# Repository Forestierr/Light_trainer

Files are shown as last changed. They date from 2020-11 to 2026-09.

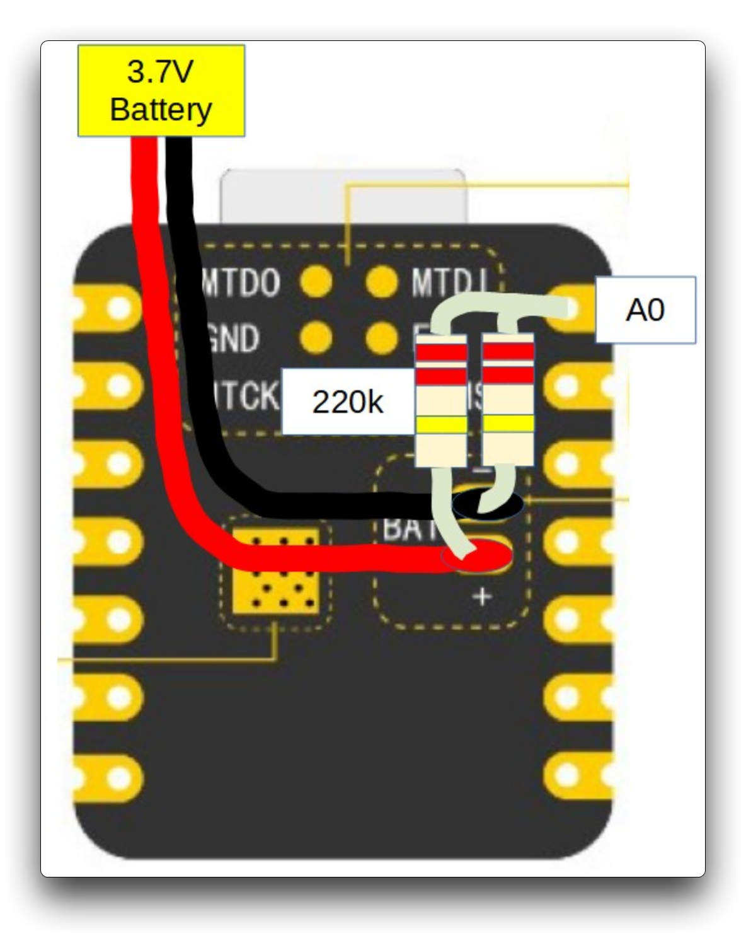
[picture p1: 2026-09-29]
1_Documentation/images/battery_mesurement.png

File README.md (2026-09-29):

<h1 align="center">⚡ Light Trainer — Système d'Entraînement Réactif Sans Fil ⚡</h1>

<p align="center">
  
  
  
  
  
</p>

<p align="center">
  <b>Pods lumineux interactifs, ultra-réactifs et modulaires pour l'entraînement sportif, le travail des réflexes, de l'agilité et de la réactivité cognitive.</b>
</p>

---

## 🌟 Points Forts du Système

* 🚀 **Zéro Latence & Réseau Maillé Auto-Organisé** : Communication instantanée multi-sauts via **ESP-NOW (2.4 GHz)**. Pas besoin de routeur Wi-Fi, les pods se découvrent et se synchronisent automatiquement.
* ✋ **Interaction 100% Sans Contact (ToF Laser)** : Télémètre **VL53L0X** cadencé à 50 Hz pour une détection millimétrique des frappes sans usure mécanique.
* 🌈 **Affichage 360° Haute Visibilité** : Anneau de 7 LEDs RVB adressables **WS2812B** avec gestion de jauges de progression et flashs de confirmation.
* 🔋 **Gestion d'Énergie Avancée & Autonomie** :
  * Batterie LiPo 3.7V avec **recharge USB-C automatique**.
  * **Deep Sleep ultra-basse consommation ($\approx 10\,\mu\text{A}$)** via coupure d'alimentation commutée $3\text{V}3\_S$ et réveil instantané sur interrupteur.
  * Mesure continue de la tension de batterie avec compensation ADC d'usine eFuse.
* 📱 **Double Interface** : Pilotage 100% gestuel sur le pod + portail Web de configuration intégré (Wi-Fi SoftAP).

---

## 📂 Structure du Répertoire

```
Light_trainer/
├── 1_Documentation/               # 📖 Documentation complète & schémas
│   ├── Architecture_Systeme.md    # Spécifications techniques & protocoles
│   ├── Dashboard_Web_App.md       # Spécifications de l'interface Web & API
│   ├── Guide_Montage_Materiel.md  # Guide pas-à-pas d'assemblage & BOM
│   ├── Manuel_Utilisation_et_Modes.md # Guide des gestes & 5 modes de jeu
│   ├── Roadmap_Idees_et_TODO.md   # Feuille de route & TODO pour la production
│   └── DOC_FAB/schema.pdf         # Schéma électronique officiel V3
├── 2_Mesures/                     # 📊 Cahier d'expérimentation & banc d'essais
│   └── Protocole_de_Tests_et_Mesures.md # Tableaux de relevés et qualification
├── 3_Datasheets/                  # 📑 Fiches techniques des composants
├── 4_Fabrication/                 # 🛠️ Fichiers de fabrication KiCad & Gerber
│   └── Version_02/light_trainer/  # Projet PCB KiCad V3
├── 5_Programmation/               # 💻 Codes sources & firmware
│   ├── XIAO-esp32-v3/main/        # Firmware principal complet (Production)
│   └── TEST_BENCH/                # Suite de qualification unitaire matérielle
└── README.md                      # Ce document
```

---

## 📐 Schéma & Câblage Matériel (V3 / Veroboard)

### Pinout du Seeed Studio XIAO ESP32-C3

```
                       +-------------------+
                       |    [ USB-C ]      |
     (ADC Batt)   D1 --| 2              14 |-- 5V VBUS  (Détection Charge USB)
   (Switch SW1)   D2 --| 3              13 |-- GND      (Masse Commune)
  (Buzzer Opt.)   D3 --| 4              12 |-- 3V3_OUT  (Sortie Régulateur LDO)
     (I2C SCL)    D4 --| 5              11 |-- D10      (Entrée Diviseur Charge)
     (I2C SDA)    D5 --| 6              10 |-- D9
                  D6 --| 7               9 |-- D8
    (LED Data)    D7 --| 8               8 |-- 3V3
                       +-------------------+
                          |  [BAT+]  [GND] |
                          |   (21)    (22) |
```

> [!TIP]
> **Résistances $100\text{ k}\Omega$ Unifiées** : Le circuit utilise uniquement des résistances standard de **$100\text{ k}\Omega$** ($R_1$ à $R_6$), simplifiant l'approvisionnement et le montage.

Consultez le [**Guide de Montage Matériel**](file:///c:/Users/Robin/Desktop/GitHub/Light_trainer/1_Documentation/Guide_Montage_Materiel.md) pour les détails d'implantation et les schémas complets.

---

## 🎮 Modes de Jeu & Navigation Gestuelle

| Geste ToF | Durée | Action en Mode Menu | Action en Cours de Jeu |
| :--- | :--- | :--- | :--- |
| **Tap Court** | $< 500\text{ ms}$ | Défilement des 5 modes (0 $\rightarrow$ 1 $\rightarrow$ 2 $\rightarrow$ 3 $\rightarrow$ 4 $\rightarrow$ 0) | *Ignoré* |
| **Hold Départ** | $1.5\text{ s}$ | **Départ de partie** (Jauge circulaire 0 à 100%) | *Non applicable* |
| **Frappe (Hit)** | $< 300\text{ ms}$ | *Ignoré* | **Validation de la cible** (Flash blanc instantané) |
| **Hold Menu** | $3.0\text{ s}$ | *Réinitialisation* | **Arrêt du jeu** et retour synchronisé au Menu pour tout le réseau |

Consultez le [**Manuel d'Utilisation**](file:///c:/Users/Robin/Desktop/GitHub/Light_trainer/1_Documentation/Manuel_Utilisation_et_Modes.md) pour découvrir les **5 modes sportifs** disponibles (Vitesse Solo, Duel Bicolore, Réflexe Aléatoire, Agilité Cognitive et Jeu Simon).

---

## 🧪 Banc de Tests et Qualification

Un firmware dédié autonome [`5_Programmation/TEST_BENCH/TEST_BENCH.ino`](file:///c:/Users/Robin/Desktop/GitHub/Light_trainer/5_Programmation/TEST_BENCH/TEST_BENCH.ino) permet de mesurer précisément les performances de votre prototype :

1. `TEST_BATTERY_STRESS` : Décharge extrême à pleine puissance (LEDs 100% blanches + RF) avec export CSV.
2. `TEST_BATTERY_GAME_SIM` : Test d'autonomie en conditions de match réelles.
3. `TEST_TOF_BENCHMARK` : Test de portée ToF, cadence de frappe (hits/min) et tenue aux perturbations solaires.
4. `TEST_RADIO_PING_RTT_RSSI` : Mesure de la portée radio, de la latence RTT (ms) et de la force du signal (RSSI).
5. `TEST_DEEP_SLEEP_POWER` : Validation de l'interrupteur matériel et mesure du courant de veille.
6. `TEST_ALL_INTERACTIVE` : Tableau de bord interactif par commandes Série.

---

## 🚀 Démarrage Rapide

### Prérequis Logiciels
* [Arduino IDE](https://www.arduino.cc/en/software) (version 2.x recommandée).
* Package de cartes : **ESP32 by Espressif Systems** (version 2.0.14+ ou 3.x).
* Sélectionner la carte : **`XIAO_ESP32C3`**.
* **Configuration Indispensable de la Flash** :
  > [!IMPORTANT]
  > Dans le menu **Outils $\rightarrow$ Partition Scheme**, sélectionnez impérativement **`Huge APP (3MB No OTA/1MB SPIFFS)`**.
  > La puce physique du XIAO ESP32-C3 dispose de 4 Mo de Flash. Sans ce réglage, le schéma standard réserve seulement 1.3 Mo à l'application, ce qui est insuffisant pour accueillir l'interface Web complète et provoque une erreur de compilation *`Sketch too big`*.
* Bibliothèques Arduino requises :
  * `FastLED`
  * `Adafruit_VL53L0X`

### Flasher le Projet
1. Ouvrez [`5_Programmation/XIAO-esp32-v3/main/main.ino`](file:///c:/Users/Robin/Desktop/GitHub/Light_trainer/5_Programmation/XIAO-esp32-v3/main/main.ino).
2. Branchez le XIAO ESP32-C3 via un câble USB-C.
3. Vérifiez que la carte est bien configurée en **Huge APP (3MB)**.
4. Cliquez sur **Téléverser**.
5. Ouvrez le Moniteur Série à **115200 bauds** pour observer le tableau de bord temps réel.

---

## 🗺️ Feuille de Route & Production

Pour découvrir les axes d'évolution logicielle pour le déploiement à grande échelle (SoftAP master exclusif, WebSockets, Gzip, PWA, calibration ToF, Web OTA et PlatformIO), consultez notre [**Feuille de Route & TODO Backlog**](file:///c:/Users/Robin/Desktop/GitHub/Light_trainer/1_Documentation/Roadmap_Idees_et_TODO.md).

---

## 📄 Licence

Ce projet est distribué sous licence **Apache 2.0**. Consultez le fichier [`LICENSE`](file:///c:/Users/Robin/Desktop/GitHub/Light_trainer/LICENSE) pour plus de détails.

---
<p align="center"><i>Robin Forestier — Projet Light Trainer</i></p>

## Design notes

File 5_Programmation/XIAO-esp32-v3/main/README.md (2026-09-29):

# Light Trainer - ESP32 Game System

Un système de jeu multi-joueurs utilisant ESP32 avec communication ESP-NOW, capteur de distance VL53L0X et LEDs WS2812B.

## Structure du Projet

```
main/
├── main.ino          # Fichier principal Arduino
├── Config.h          # Définitions de configuration globales
├── GameEngine.cpp    # Implémentation du moteur de jeu
├── GameEngine.h      # Déclarations du moteur de jeu
├── GameNetwork.cpp   # Implémentation de la logique réseau ESP-NOW
├── GameNetwork.h     # Déclarations de la logique réseau ESP-NOW
├── Hardware.cpp      # Implémentation de la gestion du matériel (LEDs, Capteur)
├── Hardware.h        # Déclarations de la gestion du matériel
├── WebConfig.cpp     # Implémentation du portail de configuration web
├── WebConfig.h       # Déclarations du portail de configuration web
└── README.md         # Ce fichier
```

## Matériel Requis

- **Seeed Studio XIAO ESP32-C3**
- **Capteur VL53L0X** (distance laser ToF I2C)
- **LEDs WS2812B** (ruban circulaire 7 LEDs)
- **Batterie LiPo 3.7V**
- **6 Résistances 100 kΩ** ($R_1$ à $R_6$)
- **1 Condensateur 100 nF** ($C_1$)
- **1 Interrupteur à glissière SPDT** ($SW_1$)

## Gestion de la Batterie & Recharge USB

Le système intègre une gestion complète de la batterie et de la recharge :

### Fonctionnalités

*   **Recharge USB-C automatique :** La batterie LiPo connectée aux pads `BAT+` / `GND` sous le XIAO est rechargée automatiquement dès le branchement du câble USB-C.
*   **Détection matérielle de Charge (D10) :** La broche `D10` est reliée au 5V `VBUS` via un pont $100\text{ k}\Omega / 200\text{ k}\Omega$ ($3.33\text{ V}$) pour détecter instantanément la connexion USB.
*   **Interrupteur ON/OFF & Veille Profonde (D2) :** L'interrupteur $SW_1$ coupe l'alimentation $3\text{V}3\_S$ du capteur/LEDs et bascule $D_2$ à LOW, mettant le XIAO en **Deep Sleep** ($\approx 10\,\mu\text{A}$). Le basculement sur ON réveille instantanément le système.
*   **Surveillance de la Tension (D1) :** Pont diviseur $100\text{ k}\Omega / 100\text{ k}\Omega$ avec condensateur de découplage $100\text{ nF}$ sur la broche ADC `D1`.
*   **Indication LED d'état :**
    *   **Orange :** Câble USB branché (Recharge en cours).
    *   **Rouge :** Batterie faible ($< 3.4\text{ V}$).
    *   **Veille de sécurité :** Coupure automatique si la batterie descend sous $3.0\text{ V}$.

## Configuration des Pins (Schéma V3 / Veroboard)

```cpp
#define LED_PIN     D7    // LEDs WS2812B Data (Broche 8)
#define SCL_PIN     D4    // I2C SCL VL53L0X (Broche 5)
#define SDA_PIN     D5    // I2C SDA VL53L0X (Broche 6)
#define SW_PIN      D2    // Interrupteur ON/OFF & Wake-up (Broche 3)
#define CHARGE_PIN  D10   // Détection Charge USB 5V (Broche 11)
#define BAT_ADC_PIN D1    // Mesure ADC Batterie (Broche 2)
#define BUZZER_PIN  D3    // Prévision Buzzer (Broche 4)
```

### Schéma de Câblage Veroboard

1. **Alimentation & Batterie :**
   * Pôle (+) de la batterie $\rightarrow$ Pad `BAT+` (Pin 21) du XIAO.
   * Pôle (-) de la batterie $\rightarrow$ Pad `GND` (Pin 22) du XIAO et masse commune `GND`.
2. **Interrupteur $SW_1$ :**
   * Broche 2 $\rightarrow$ `3V3_OUT` (Pin 12) du XIAO.
   * Broche 1 $\rightarrow$ Rail $3\text{V}3\_S$, relié à la broche `D2` et à la résistance pull-down $R_3$ ($100\text{ k}\Omega$ vers `GND`).
3. **LEDs WS2812B :**
   * `DIN` $\rightarrow$ Broche `D7` du XIAO.
   * `VDD` $\rightarrow$ Rail $3\text{V}3\_S$.
   * `GND` $\rightarrow$ `GND`.
4. **Capteur ToF VL53L0X :**
   * `VIN` $\rightarrow$ Rail $3\text{V}3\_S$.
   * `GND` $\rightarrow$ `GND`.
   * `SCL` $\rightarrow$ Broche `D4` du XIAO.
   * `SDA` $\rightarrow$ Broche `D5` du XIAO.
5. **Diviseur Batterie :**
   * $R_1$ ($100\text{ k}\Omega$) entre `BAT` et `D1`.
   * $R_2$ ($100\text{ k}\Omega$) et $C_1$ ($100\text{ nF}$) en parallèle entre `D1` et `GND`.
6. **Diviseur Détection USB (VBUS) :**
   * $R_4$ ($100\text{ k}\Omega$) entre `VBUS` (Pin 14) et `D10`.
   * $R_5 + R_6$ ($100\text{ k}\Omega + 100\text{ k}\Omega$) en série entre `D10` et `GND`.

## Modes de Jeu

Le système supporte 5 modes de jeu différents :

1.  **Mode 0**: Vitesse Solo — Couleur principale : Vert (`0x00FF00`), sans délai.
2.  **Mode 1**: Duel Bicolore — Joueur 1 : Rouge (`0xFF0000`), Joueur 2 : Vert (`0x00FF00`), sans délai (2 cibles actives en permanence).
3.  **Mode 2**: Réflexe Aléatoire — Couleur principale : Bleu (`0x0000FF`), délai aléatoire de 1 à 5s.
4.  **Mode 3**: Agilité Cognitive — C1 : Jaune (`0xFFFF00`), C2 : Magenta (`0xFF00FF`), délai aléatoire de 1 à 5s.
5.  **Mode 4**: Jeu Simon — Mémoire séquentielle & accélération progressive (rose de départ, couleurs signatures par pod).

## Configuration de Compilation (IDE Arduino / PlatformIO)

> [!IMPORTANT]
> Dans le menu **Outils $\rightarrow$ Partition Scheme**, sélectionnez **`Minimal SPIFFS (1.9MB APP with OTA/190KB SPIFFS)`** (ou `min_spiffs.csv` sous PlatformIO).
> Grâce à la pré-compression GZIP de l'interface Web (réduite de 84 Ko à 18 Ko), le binaire complet ne pèse que 1.45 Mo. Cela permet de réserver **deux partitions applicatives de 1.9 Mo** (`ota_0` et `ota_1`) et d'assurer les mises à jour sans fil **Over-The-Air (OTA)** sans câble USB.

## Fonctionnalités Clés

*   **Initialisation des lumières en début de partie** : Au démarrage d'une partie, le pod maître éteint ses lumières. Les pods esclaves reçoivent la couleur du mode de jeu sélectionné et l'affichent immédiatement.
*   **Retour au menu via le capteur ToF** : Il est possible de revenir au menu principal à tout moment pendant le jeu en couvrant le capteur ToF (courte distance) pendant 3 secondes. Si un pod esclave déclenche cette action, il envoie un signal au pod maître, qui propage ensuite la commande à tous les autres pods pour réinitialiser le système en mode MENU.

## États du Système

- **MENU**: État initial, en attente de sélection de mode ou démarrage du jeu.
- **CONTROLLER**: Pod maître, gère le déroulement du jeu et les activations.
- **CONTROLLER_TARGET**: Le maître est une cible active.
- **ACTIVE_TARGET**: Pod esclave, est une cible active.
- **IDLE_LISTENER**: Pod esclave, en attente d'activation.

## Diagramme d'États

```mermaid
stateDiagram-v2
    [*] --> MENU

    MENU --> CONTROLLER : startGame() / 's' / ToF (< TOF_MIN_DISTANCE)
    MENU --> IDLE_LISTENER : CMD_START from CONTROLLER

    CONTROLLER --> CONTROLLER_TARGET : CMD_ACTIVATE (self)
    CONTROLLER_TARGET --> CONTROLLER : triggerHit / ToF (< TOF_MIN_DISTANCE)

    IDLE_LISTENER --> ACTIVE_TARGET : CMD_ACTIVATE (self)
    ACTIVE_TARGET --> IDLE_LISTENER : triggerHit / ToF (< TOF_MIN_DISTANCE)

    CONTROLLER --> MENU : returnToMenu() / 'r' / ToF (3s)
    CONTROLLER_TARGET --> MENU : returnToMenu() / 'r' / ToF (3s)
    IDLE_LISTENER --> MENU : CMD_RETURN_TO_MENU from CONTROLLER / 'r' / ToF (3s) (initiateur)
    ACTIVE_TARGET --> MENU : CMD_RETURN_TO_MENU from CONTROLLER / 'r' / ToF (3s) (initiateur)

    note left of MENU : État initial, en attente de sélection de mode ou démarrage du jeu.
    note right of CONTROLLER : Pod maître, gère le déroulement du jeu et les activations.
    note right of CONTROLLER_TARGET : Le maître est une cible active.
    note left of IDLE_LISTENER : Pod esclave, en attente d'activation.
    note left of ACTIVE_TARGET : Pod esclave, est une cible active.
```

### Types de Messages

- `CMD_START`: Démarrage du jeu
- `CMD_ACTIVATE`: Activation d'une cible
- `CMD_HIT`: Cible touchée
- `CMD_PING`: Découverte des nœuds & mesure RTT/RSSI
- `CMD_ACK`: Accusé de réception ping
- `CMD_RETURN_TO_MENU`: Retour synchronisé au menu principal
- `CMD_MANUAL_SET`: Allumage forcé en mode manuel coach
- `CMD_TEST_LEDS`: Banc de test dynamique des LEDs
- `CMD_POD_TELEMETRY`: Télémétrie périodique batterie & charge USB
- `CMD_HEARTBEAT`: Battement de cœur régulier du Master (maintien du bail & synchro état)
- `CMD_CLAIM_MASTER`: Revendication du rôle Master (élection dynamique ou geste Hold 1.5s)

### Structure des Messages

```cpp
typedef struct __attribute__((packed)) struct_message {
  uint32_t msgId;     // Identifiant unique séquentiel
  uint64_t senderID;  // ID du pod expéditeur
  uint64_t targetID;  // ID de la cible (0 = broadcast à tous)
  uint8_t msgType;    // Type de message (CMD_*)
  uint8_t ttl;        // Nombre de sauts restants (Mesh multi-hop)
  uint32_t color;     // Couleur à afficher
} struct_message;
```

## Utilisation & Expérience Utilisateur (UX)

### Contrôles Gestuels par Capteur ToF (VL53L0X)

L'interaction repose sur des gestes numériques fiables et rapides, avec tolérance aux reflets et micro-coupures optiques :

- **Changer de Mode (en mode MENU) - *Tap Court*** :
  - Un passage bref de la main ($< 150\text{ mm}$ pendant moins de $500\text{ ms}$) fait défiler les modes (**Mode 0 $\rightarrow$ 1 $\rightarrow$ 2 $\rightarrow$ 3 $\rightarrow$ 0**).
  - Les 7 LEDs s'illuminent immédiatement de la couleur du mode sélectionné.
- **Lancer la Partie (en mode MENU) - *Maintien 1.5s (Hold)*** :
  - Maintenez la main au-dessus du pod ($< 150\text{ mm}$).
  - Les 7 LEDs affichent une **jauge circulaire de progression** qui se remplit. À $100\%$ ($1.5\text{ s}$), un flash blanc confirme le départ et le jeu commence.
- **Toucher une Cible (en Jeu) - *Hit Ultra-Rapide*** :
  - Tout passage rapide à $< 150\text{ mm}$ valide instantanément la touche avec un **flash blanc de confirmation ($60\text{ ms}$)**.
  - Le capteur tourne en mode `HIGH_SPEED` (50 Hz) pour garantir 0 latence.
- **Retour au Menu (depuis n'importe quel état) - *Maintien 3s*** :
  - Maintenez la main sur n'importe quel pod pendant $3\text{ secondes}$.
  - L'action réinitialise tous les pods du réseau en mode MENU de manière synchronisée.

### Contrôles Série

- `'s'`: Démarrer le jeu (le pod devient `CONTROLLER`)
- `'h'`: Simuler un hit
- `'0'-'3'`: Changer de mode de jeu (en mode `MENU`)
- `'r'`: Retour au menu principal
- `'d'`: Afficher immédiatement le Dashboard complet de débogage
- `'?'`: Afficher l'aide des commandes série

## Débogage Série Avancé (Dashboard)

Le système intègre un **tableau de bord ASCII temps réel** imprimé automatiquement toutes les 5 secondes (ou sur commande `'d'`) sur le port Série (115200 bauds) :

```text
+-----------------------------------------------------------------------+
|                     LIGHT TRAINER - DEBUG DASHBOARD                   |
+-----------------------------------------------------------------------+
| Pod ID           : 34:B7:DA:55:A1:2C (Dec: 57962454147372)
| Etat du Pod      : CONTROLLER (Master)
| Mode de Jeu      : Mode 1 (Duel - 2 Couleurs, sans delai)
| Parametres Mode  : C1=#FF0000, C2=#00FF00, Delai=[0ms - 0ms]
| Capteur ToF      : 115 mm [MAIN DETECTEE - Zone active <= 150mm]
| Pods Connectes   : 2 pod(s) decouvert(s)
|   [1] ID: E0:5A:1B:77:88:99 (Dec: 246675200379033)
|   [2] ID: F4:12:FA:11:22:33 (Dec: 268361099682355)
| Cibles Actives   : 1 cible(s) en cours
|   * Pod E0:5A:1B:77:88:99 | Couleur: #FF0000 | Activee depuis: 2.3s (Timeout: 15s)
| Dernier Msg RX   : CMD_HIT (msgId: 14, Emetteur: E0:5A:1B:77:88:99, Cible: 0 (BROADCAST), Couleur: #FF0000, Il y a 1s)
| Dernier Msg TX   : CMD_ACTIVATE (msgId: 15, Cible: E0:5A:1B:77:88:99, Couleur: #FF0000, Il y a 1s)
| Derniere Erreur  : Aucune erreur enregistree
| Uptime / RAM     : Uptime: 45s | Free Heap: 182340 octets
+-----------------------------------------------------------------------+
| Commandes Serie  : [s]=Start  [h]=Hit  [0-3]=Mode  [r]=Menu  [d]=Dashboard [?]=Aide
+-----------------------------------------------------------------------+
```

Vous pouvez également modifier la verbosité des logs en temps réel via `#define CURRENT_DEBUG_LEVEL` dans `Config.h` (`DEBUG_ERROR`, `DEBUG_INFO`, `DEBUG_VERBOSE`).

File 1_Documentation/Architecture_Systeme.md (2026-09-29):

# Architecture Système & Spécifications Techniques — Light Trainer V3

Ce document décrit en détail l'architecture matérielle, logicielle, réseau et énergétique du système **Light Trainer V3**.

---

## 1. Vue d'Ensemble du Système

Le **Light Trainer** est un écosystème de pods lumineux interactifs et autonomes destinés à l'entraînement sportif (réactivité, agilité, vitesse de décision).

```mermaid
graph TD
    User["Utilisateur / Sportif"] -->|Geste / Frappe sans contact| ToF["Capteur ToF VL53L0X (I2C)"]
    ToF -->|Interruption / Distance mm| ESP["Microcontrôleur Seeed XIAO ESP32-C3"]
    ESP -->|Signal Data D7 (GRB)| LEDs["Anneau 7 LEDs WS2812B"]
    ESP -->|ESP-NOW Mesh Flooding (2.4 GHz)| Peer["Autres Pods Light Trainer"]
    ESP -->|WiFi SoftAP + Web Server| Smartphone["Interface Web Config (Mobile/PC)"]
    
    Battery["Batterie LiPo 3.7V"] -->|BAT+ / BAT-| Charger["Chargeur Linéaire Intégré (USB-C)"]
    Battery -->|Pont 100k/100k| ADC["Mesure ADC (D1)"]
    Switch["Interrupteur SPDT (SW1)"] -->|Alimentation 3V3_S| ToF
    Switch -->|Alimentation 3V3_S| LEDs
    Switch -->|Signal D2 (Wakeup)| ESP
    USB["Port USB-C (5V VBUS)"] -->|Pont 100k/200k| ChargePin["Détection Charge (D10)"]
```

---

## 2. Architecture Électrique & Énergie

### 2.1. Étage d'Alimentation et Gestion de Batterie
* **Microcontrôleur** : Seeed Studio XIAO ESP32-C3 (Flash physique 4 Mo, architecture RISC-V 32 bits, 160 MHz).
* **Schéma de Partitionnement Flash** : Nécessite la configuration **`Huge APP (3MB No OTA/1MB SPIFFS)`** dans l'IDE Arduino. L'interface Web complète intégrée en Flash (`PROGMEM`) représentant environ 1.3 Mo de binaire, la table standard de 1.3 Mo déborde sans ce réglage.
* **Batterie** : Accumulateur Lithium-Polymère (LiPo) 3.7 V monocellule (4.2 V max, 3.0 V coupure).
* **Recharge USB-C** : Assurée automatiquement par le contrôleur de charge intégré sous le XIAO ESP32-C3 via les pads `BAT+` et `GND`.

### 2.2. Cartographie des Pins (Pinout V3 / Veroboard)

| Nom Broche | Pin XIAO | GPIO ESP32-C3 | Fonction | Rôle & Caractéristiques |
| :--- | :--- | :--- | :--- | :--- |
| **`BAT_ADC_PIN`** | `D1` | `GPIO3` | Entrée ADC Batterie | Pont diviseur $100\text{ k}\Omega / 100\text{ k}\Omega$ ($V_{\text{batt}} = 2 \times V_{\text{ADC}}$) + C1 $100\text{ nF}$ |
| **`SW_PIN`** | `D2` | `GPIO4` | Détection Switch / Wakeup | Détection $3\text{V}3\_S$ + Réveil Deep Sleep sur front montant |
| **`BUZZER_PIN`** | `D3` | `GPIO5` | Sortie Buzzer (Option) | Sortie PWM pour signaux sonores (TP2) |
| **`SCL_PIN`** | `D4` | `GPIO6` | Bus I2C SCL | Horloge I2C pour VL53L0X (Pull-up $10\text{ k}\Omega$ intégrée au module) |
| **`SDA_PIN`** | `D5` | `GPIO7` | Bus I2C SDA | Données I2C pour VL53L0X (Pull-up $10\text{ k}\Omega$ intégrée au module) |
| **`LED_PIN`** | `D7` | `GPIO20` | Sortie WS2812B Data | Signal série cadencé à 800 kHz pour les 7 LEDs |
| **`CHARGE_PIN`** | `D10` | `GPIO10` | Détection USB 5V VBUS | Pont diviseur $100\text{ k}\Omega / 200\text{ k}\Omega$ ($V_{\text{pin}} = 3.33\text{ V}$) |

### 2.3. Gestion de l'Interrupteur et Mode Veille Profonde (Deep Sleep)
Pour maximiser l'autonomie et supprimer tout courant de fuite sans nécessiter d'interrupteur haute puissance :
1. L'interrupteur à glissière $SW_1$ coupe la ligne $3\text{V}3\_S$ alimentant les périphériques (LEDs et capteur ToF).
2. Lorsque $SW_1$ est basculé sur OFF, la broche `D2` passe à `LOW` (tirée à la masse par la résistance de pull-down $R_3 = 100\text{ k}\Omega$).
3. Le microcontrôleur détecte la transition, éteint la radio WiFi, isole ses GPIOs (`LED_PIN`, `SCL`, `SDA` configurées en haute impédance / pull-down), configure le réveil sur front montant via `esp_deep_sleep_enable_gpio_wakeup(1ULL << D2, ESP_GPIO_WAKEUP_GPIO_HIGH)`, et entre en **Deep Sleep** ($I_{\text{sleep}} \approx 10\text{--}15\,\mu\text{A}$).
4. Le basculement de $SW_1$ sur ON réinjecte $3.3\text{ V}$ sur `D2`, ce qui réveille instantanément le microcontrôleur.

---

## 3. Protocole Réseau & Topologie Mesh ESP-NOW

### 3.1. Philosophie du Réseau
* **Protocole de transport** : ESP-NOW (Protocole propriétaire Espressif sans fil basé sur des trames d'action 802.11 sans association de point d'accès).
* **Canal radio** : Canal 1 fixe verrouillé.
* **Topologie** : Réseau Mesh sans maître fixe prédéfini (*Peer-to-Peer* avec élection dynamique du Master lors du démarrage de partie).

### 3.2. Format de la Trame Radio (`struct_message`)
La trame est compactée sur 28 octets pour garantir une latence d'émission inférieure à 2 ms :

```cpp
typedef struct __attribute__((packed)) struct_message {
  uint32_t msgId;     // Identifiant unique incrémental pour le filtrage anti-boucle
  uint64_t senderID;  // Adresse MAC unique du pod expéditeur (64 bits)
  uint64_t targetID;  // ID du pod cible (0 = BROADCAST à tous, sinon MAC ciblée)
  uint8_t  msgType;   // Type de commande (MsgType)
  uint8_t  ttl;       // Time-To-Live (nombre de sauts restants, défaut = 3)
  uint32_t color;     // Couleur RGB associée OU données de télémétrie compactées
} struct_message;
```

#### Commandes Réseau (`enum MsgType`) :
| Valeur | Nom | Rôle & Charge Utile |
| :--- | :--- | :--- |
| `0` | **`CMD_START`** | Ordre de début de partie émis par le Master vers la flotte. |
| `1` | **`CMD_ACTIVATE`** | Activation d'un pod spécifique (ou broadcast). `color` contient le code RGB. |
| `2` | **`CMD_HIT`** | Signal de frappe émis par l'esclave touché vers le Master. |
| `3` | **`CMD_PING`** | Requête de mesure de portée, latence RTT et force de signal ($RSSI$). |
| `4` | **`CMD_ACK`** | Réponse immédiate de l'esclave au ping avec horodatage. |
| `5` | **`CMD_RETURN_TO_MENU`** | Ordre d'arrêt synchronisé de la partie et réinitialisation en mode Menu. |
| `6` | **`CMD_MANUAL_SET`** | Ordre du coach via l'interface Web pour forcer l'allumage manuel d'un pod. |
| `7` | **`CMD_TEST_LEDS`** | Déclenchement d'un banc de test visuel sur les 7 LEDs d'un pod distant. |
| `8` | **`CMD_POD_TELEMETRY`** | Diffusion périodique (toutes les 5 s) de l'état de batterie et de charge. |

#### Encapsulation de Télémétrie sur 32 bits (`CMD_POD_TELEMETRY`) :
Pour éviter de gonfler la taille du paquet radio, les informations de santé du pod sont encapsulées dans le champ 32 bits `color` :
* **Bits 0 à 7** (`color & 0xFF`) : Pourcentage de batterie restant (`batPct`, $0\text{--}100\,\%$).
* **Bits 8 à 23** (`(color >> 8) & 0xFFFF`) : Tension batterie en centièmes de Volt ($V_{\text{batt}} \times 100$, ex: $412 = 4.12\text{ V}$).
* **Bit 24** (`(color >> 24) & 0x01`) : Statut de charge USB (`isCharging`, $1$ si branché sur $5\text{V}$, $0$ sur batterie).

---

### 3.3. Algorithme de Routage Mesh (Flooding avec Déduplication)
```mermaid
sequenceDiagram
    autonumber
    participant M as Pod Maître (Controller)
    participant P1 as Pod 1 (Relais Mesh)
    participant P2 as Pod 2 (Cible finale)

    M->>P1: CMD_ACTIVATE (Target=Pod 2, TTL=3, msgId=101)
    Note over P1: Vérifie cache : msgId 101 non vu.<br/>Ajoute à la table des messages vus.
    P1->>P2: Relais Mesh : CMD_ACTIVATE (Target=Pod 2, TTL=2, msgId=101)
    Note over P2: Target = Mon ID !<br/>Allume les LEDs en Vert.
    P2-->>P1: CMD_HIT (Sender=Pod 2, Target=Broadcast, TTL=3, msgId=202)
    P1-->>M: Relais Mesh : CMD_HIT (Sender=Pod 2, TTL=2, msgId=202)
    Note over M: Validation du point et activation de la cible suivante !
```

---

### 3.4. Gestion de Présence de la Flotte (Node Liveness, Sommeil & Élagage)
* **Battement de Cœur (Heartbeat / Discovery)** : Chaque pod diffuse son paquet `CMD_POD_TELEMETRY` toutes les $5\text{ s}$ (`DISCOVERY_INT`).
* **Détection de Veille / Déconnexion ($12\text{ s}$)** :
  - Tout pod distant dont la dernière trame reçue remonte à plus de $12\text{ secondes}$ (`millis() - node.lastSeen > 12000`) est immédiatement qualifié hors-ligne (`online = false`).
  - Dans l'interface Web (Mode Manuel et Diagnostic), il est grisé avec la mention *"💤 En veille"*.
  - **Protection du Moteur de Jeu** : La méthode `GameNetwork.getKnownNodes()` filtre strictement les pods inactifs. Le moteur de jeu ne sélectionnera jamais un pod endormi comme cible !
* **Élagage Automatique (Pruning à $60\text{ s}$)** :
  - Si un pod reste silencieux pendant plus de $60\text{ secondes}$, il est supprimé de la table des nœuds connus dans `GameNetwork.update()` afin de libérer de l'espace pour de nouveaux pods sans saturation mémoire.

---

## 4. Moteur Gestuel & Détection Optique ToF (VL53L0X)

Le capteur de distance laser à temps de vol (Time-of-Flight) VL53L0X est configuré en mode **`HIGH_SPEED`** à 50 Hz (cycle de 20 ms) pour une réactivité sportive instantanée sans contact.

```mermaid
stateDiagram-v2
    [*] --> HorsPortee : Distance > 150 mm

    HorsPortee --> ZoneActive : Distance <= 150 mm
    
    state ZoneActive {
        [*] --> TapDetect : t < 500 ms
        TapDetect --> StartHold : t >= 1500 ms (Jauge 100%)
        StartHold --> MenuHold : t >= 3000 ms
    }

    ZoneActive --> HitValide : Retrait rapide de la main en jeu
    ZoneActive --> HorsPortee : Retrait de la main en Menu
```

### Paramètres de Détection
* **Seuil de frappe (`TOF_TRIGGER_DISTANCE`)** : $150\text{ mm}$ (détection fiable de la main sans toucher physiquement le pod).
* **Tap Court (`GESTURE_TAP_MAX_MS`)** : $< 500\text{ ms}$ (changement de mode de jeu en Menu).
* **Maintien Démarrage (`GESTURE_START_HOLD_MS`)** : $1500\text{ ms}$ avec jauge visuelle circulaire.
* **Maintien Retour Menu (`GESTURE_MENU_HOLD_MS`)** : $3000\text{ ms}$ pour réinitialiser tout le système.
* **Tolérance aux micro-décrochages (`GESTURE_GLITCH_TOLERANCE_MS`)** : $250\text{ ms}$ (évite d'annuler le maintien en cas de vibration ou ombre).

---

## 5. Machine à États Logicielle (Game Engine)

```mermaid
stateDiagram-v2
    [*] --> MENU

    MENU --> CONTROLLER : Maintien 1.5s / Touche 's' (Ce pod devient Maître)
    MENU --> IDLE_LISTENER : Réception CMD_START d'un autre pod

    CONTROLLER --> CONTROLLER_TARGET : Le Maître s'active lui-même comme cible
    CONTROLLER_TARGET --> CONTROLLER : Hit détecté sur le Maître

    CONTROLLER --> CONTROLLER : Réception CMD_HIT d'un esclave -> Choix nouvelle cible

    IDLE_LISTENER --> ACTIVE_TARGET : Réception CMD_ACTIVATE (Cible = Mon ID)
    ACTIVE_TARGET --> IDLE_LISTENER : Hit détecté sur l'esclave -> Envoi CMD_HIT

    CONTROLLER --> MENU : Maintien 3s / 'r' -> Envoi CMD_RETURN_TO_MENU
    IDLE_LISTENER --> MENU : Réception CMD_RETURN_TO_MENU / Maintien 3s
    ACTIVE_TARGET --> MENU : Réception CMD_RETURN_TO_MENU / Maintien 3s
```

---

## 6. Architecture Web Embarquée, Streaming Zero-Copy & Portail Captif

### 6.1. Streaming HTTP Zero-Copy depuis la Flash (`PROGMEM`)
L'interface Web complète du Light Trainer (HTML5, SVG vectoriels, styles CSS modernes, scripts d'animation et moteur de graphes) représente environ 75 Ko de code source.
* **Problématique de la mémoire RAM (Heap)** : Dans l'environnement Arduino ESP32, instancier une `String` de 75 Ko ou concaténer de gros buffers entraîne une fragmentation sévère du tas (Heap). Le serveur Web échoue alors à allouer le buffer contigu nécessaire et renvoie un en-tête `Content-Length: 0`, provoquant une page blanche ou le blocage du portail captif.
* **Solution Zero-Copy (`server.send_P`)** :
  - La chaîne complète est déclarée en mémoire Flash constante : `static const char DASHBOARD_HTML[] PROGMEM = R"rawliteral(...)rawliteral";`.
  - Le serveur Web utilise la méthode zero-copy : `server.send_P(200, "text/html", DASHBOARD_HTML, sizeof(DASHBOARD_HTML) - 1);`.
  - Le microcontrôleur lit directement la Flash via le bus MMU et transmet les octets par paquets réseau MTU (1460 octets) sans jamais allouer la page en RAM !

### 6.2. Portail Captif Haute Résilience
Pour garantir l'ouverture automatique du tableau de bord lors de la connexion WiFi sur iOS, Android, Windows et macOS :
1. **Serveur DNS Wildcard (Port 53 UDP)** : Toutes les requêtes de résolution de noms de domaine sont interceptées et redirigées vers l'IP locale `192.168.4.1`.
2. **Codes d'Erreur DNS (`NoError`)** : Configuration explicite de `dnsServer.setErrorReplyCode(DNSReplyCode::NoError)` afin de ne pas rejeter les requêtes modernes AAAA (IPv6) ou HTTPS (Type 65) qui feraient abandonner le système d'exploitation mobile.
3. **Interception des Sondes Dédiées OS** :
   - Apple iOS / macOS : `/hotspot-detect.html`, `/canonical.html`
   - Android / ChromeOS : `/generate_204`, `/gen_204`
   - Windows 10/11 : `/connecttest.txt`, `/ncsi.txt`
   - Firefox / Linux : `/success.txt`, `/library/test/success.html`
4. **Gestion des Redirections 302** : Toute URI inconnue non préfixée par `/api/` renvoie un code HTTP `302 Redirect` vers `http://192.168.4.1/` avec un corps textuel d'accompagnement pour satisfaire les clients stricts.

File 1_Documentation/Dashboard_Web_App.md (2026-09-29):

# Spécifications & Architecture Détaillée : Dashboard Web & Portail Captif V3

Ce document formalise la conception complète du portail captif et de l'interface Web du **Light Trainer V3**.

---

## 🧭 1. Vue d'Ensemble des 4 Espaces de l'Interface Web

L'application s'articule autour de **4 onglets ergonomiques** :

```mermaid
graph TD
    Root["Interface Web (Portail Captif 192.168.4.1)"]
    Root --> Tab1["🎯 1. Entraînement Auto<br/>(Chronomètre, Scores, Stats & Graphiques)"]
    Root --> Tab2["🕹️ 2. Mode Manuel Coach<br/>(Carte des pods, Allumage pod par pod)"]
    Root --> Tab3["🧪 3. Tests & Diagnostic<br/>(Test ToF, Ping Radio, Test LEDs, Batterie)"]
    Root --> Tab4["⚙️ 4. Réglages & Logs<br/>(Journal en direct, Paramètres NVS, Export CSV)"]
```

---

## 📱 2. Détail des Fonctionnalités par Onglet

### 🎯 Onglet 1 : Mode Jeu / Entraînement Automatique
* **Chronomètre & Télécommande** : Grand affichage numérique avec boutons `[Démarrer]`, `[Pause]`, `[Stop]`.
* **Sélection du Mode Sportif** :
  * Mode 0 : Vitesse Solo (1 Couleur, sans délai)
  * Mode 1 : Duel 2 Joueurs (Bicolore Rouge vs Vert, sans délai)
  * Mode 2 : Réflexe Aléatoire (1 Couleur avec délai variable)
  * Mode 3 : Agilité Cognitive (Alternance 2 Couleurs avec délai variable)
  * Mode 4 : Jeu Simon (Mémoire séquentielle & accélération progressive)
* **Statistiques Live & Cartes Dynamiques** :
  * *Vue Duel* : Comparaison en direct Joueur 1 vs Joueur 2, temps moyen, record et barre de domination proportionnelle.
  * *Vue Simon* : Badge d'état (Démonstration / À vous / Succès / Game Over), Tour actuel, Longueur de séquence, Record de la session, Progression étape par étape et Vitesse tempo ($ms$).
  * *Synthèse Globale* : Total de touches, Cadence ($BPM$), Temps moyen ($ms$), Meilleur record ($ms$).
* **Graphique Haute Précision Auto-Adaptatif** : Tracé vectoriel lissé avec axe $Y$ dynamique (adapté aux temps $> 500\text{ ms}$) et ligne de moyenne pointillée.

---

### 🕹️ Onglet 2 : Mode Manuel (Contrôle Direct par le Coach)
* **Visualisation de la Grille des Pods & Suivi de Présence** :
  * Le compteur d'en-tête affiche la proportion de pods actifs : ex. `1/3 Pods` si 2 pods sont en veille ou éteints.
  * Chaque pod découvert dans le réseau maillé apparaît sous forme de carte interactive :
    * Nom / ID du pod (`Pod 1 (Master)`, `Pod 2`, `Pod 3`...)
    * Niveau de batterie ($V$ et $\%$) et icône de charge USB `⚡`
    * Force du signal radio ($RSSI$ en $dBm$)
    * Statut actif (Cible en cours avec liseré vert fluo)
  * **Gestion Visuelle des Pods en Veille (Deep Sleep)** :
    * Tout pod silencieux depuis $>12\text{ s}$ est automatiquement détecté hors-ligne.
    * Sa carte passe en mode estompé (`opacity: 0.38`), l'avatar adopte une bordure en pointillés, et la mention *"💤 En veille (Xs)"* apparaît.
    * Les clics sont désactivés pour éviter d'envoyer des commandes infructueuses dans le vide.
* **Contrôle Tactile Instantané** :
  * Palette de couleurs rapides : 🟢 Vert, 🔴 Rouge, 🔵 Bleu, 🟡 Jaune, 🟣 Magenta, ⚪ Blanc.
  * **Clic sur un Pod Actif** : Le coach clique sur le Pod #2 $\rightarrow$ le pod #2 s'allume immédiatement de la couleur choisie.
  * **Boutons globaux** : `[Tout Allumer]`, `[Tout Éteindre]`, `[Flash Général]`.
* **Détection de frappe en mode manuel** : Lorsqu'un athlète frappe le pod allumé, le pod s'éteint et la page Web émet un signal sonore/visuel avec le temps écoulé depuis l'allumage par le coach !

---

### 🧪 Onglet 3 : Banc de Tests & Diagnostics en Direct
Permet à l'utilisateur de vérifier l'état du matériel en 1 coup d'œil sans démonter :

| Composant | Outil de Diagnostic Intégré | Ce que l'utilisateur voit à l'écran |
| :--- | :--- | :--- |
| **Capteur ToF** | Testeur de Distance Temps Réel | Jauge dynamique indiquant la distance exacte en $mm$ et détection d'obstacle (Vert si $< 150\text{ mm}$, indicateur d'erreurs optiques/soleil). |
| **Réseau Radio** | Outil Ping & Portée Actif | Bouton `[Tester la liaison]` : Envoie des pings (`CMD_PING`) vers chaque pod distant via ESP-NOW, mesure et affiche le temps de réponse (RTT en $ms$) et la force du signal ($RSSI$ en $dBm$). |
| **LEDs WS2812B** | Séquenceur de Test LED | Boutons de test rapide : Cycle RGB, Blanc $100\%$ (test de puissance), Chenillard circulaire (test des 7 LEDs individuelles). |
| **Alimentation Flotte** | Tableau de Batterie Global | Section dédiée **"Batterie de toute la flotte"** : Cartes individuelles pour le Master et tous les esclaves avec tension en direct ($V$), jauge colorée ($\%$, alerte rouge si $\le 20\%$), badge de charge USB (`⚡ Charge USB`), et statut hors-ligne/veille. |

---

### ⚙️ Onglet 4 : Réglages, Logs Système & Exportation

#### A. Journal d'Événements en Direct (Console de Logs)
* Fenêtre de log déroulante (type terminal) affichant tous les événements système horodatés :
  ```text
  [12:04:15.120] [RADIO] Nouveau pod découvert : Pod #2 (MAC: E0:5A:1B:77:88:99) RSSI: -52 dBm
  [12:04:18.450] [GAME] Démarrage du Mode 0 (Vitesse Solo)
  [12:04:19.230] [HIT] Pod #2 touché ! Temps de réaction : 215 ms
  [12:04:20.100] [TOF] Mesure : 112 mm (Main détectée)
  [12:04:25.800] [POWER] Tension batterie Pod Master : 4.12V (95%)
  ```
* Filtres de logs : `Tous`, `Erreurs`, `Radio`, `Jeu`, `Batterie`.
* Bouton `[Effacer les logs]` et `[Copier les logs]`.

#### B. Paramètres Système (Sauvegardés en Flash NVS)
* Curseur de luminosité globale des LEDs ($10\%$ à $100\%$).
* Éditeur de couleurs des modes de jeu (Color Picker).
* Réglage des délais aléatoires min/max entre cibles.
* Seuil de déclenchement ToF (ajustable de $50\text{ mm}$ à $300\text{ mm}$).

#### C. Export des Données (CSV)
* Bouton `[Télécharger la séance (CSV)]` : Télécharge le fichier structuré de la session directement sur le smartphone pour analyse dans Excel / Google Sheets.

---

## ⚡ 3. Architecture Logicielle & Coexistence Radio

```mermaid
flowchart TD
    subgraph ESP32["Seeed Studio XIAO ESP32-C3"]
        subgraph ModeAP["Interface SoftAP (192.168.4.1)"]
            DNS["Serveur DNS Captif (Port 53)<br/>Redirection globale"]
            HTTP["Serveur Web HTTP (Port 80)"]
            REST["Endpoints REST API (JSON)"]
        end

        subgraph ModeSTA["Interface STA (Canal 1 fixe)"]
            ESPNOW["ESP-NOW Mesh Flooding<br/>(Zéro latence avec les pods)"]
        end

        subgraph Core["Moteur de Jeu & Logique"]
            GameEngine["Game Engine (Auto / Manuel)"]
            LogBuffer["Buffer Circulaire de Logs (RAM)"]
            HitHistory["Historique des Frappes (RAM)"]
            HardwareMgr["Hardware (ToF 50Hz, LEDs, ADC)"]
        end

        DNS --> HTTP
        HTTP --> REST
        REST <--> GameEngine
        REST <--> LogBuffer
        REST <--> HitHistory
        GameEngine <--> ESPNOW
        GameEngine <--> HardwareMgr
    end

    Phone["Smartphone / Tablette (Portail Captif)"] <-->|Requêtes HTTP / JSON (Poll 250ms)| HTTP
```

---

## 🔌 4. Spécification des Endpoints API REST (JSON)

| Méthode & Route | Description | Exemple de Données Échangées |
| :--- | :--- | :--- |
| `GET /api/status` | Statut du jeu, chronomètre, scores, bicolore, ToF et historique batterie | `{"state":"RUNNING","mode":0,"time":34820,"hits":18,"lastRt":210,"bestRt":175,"avgRt":238,"cadence":31,"vBat":4.12,"batPct":92,"charging":false,"tofDist":85,"batHistory":[{"t":0,"pct":85,"v":4.02,"chg":false},{"t":60,"pct":92,"v":4.12,"chg":true}]}` |
| `GET /api/pods` | Liste complète des pods du réseau avec télémétrie, état de veille et MAC | `{"pods":[{"id":"34B7DA55A12C","name":"Pod 1 (Master)","isMaster":true,"isTarget":false,"rssi":0,"vBat":4.12,"batPct":92,"charging":false,"online":true,"lastSeenSec":0,"mac":"34:B7:DA:55:A1:2C"},{"id":"E05A1B778899","name":"Pod 2","isMaster":false,"isTarget":true,"rssi":-52,"vBat":3.98,"batPct":85,"charging":false,"online":true,"lastSeenSec":3,"mac":"E0:5A:1B:77:88:99"}]}` |
| `GET /api/logs` | Derniers logs système horodatés | `{"logs":[{"t":12450,"lvl":"INFO","msg":"Hit Pod 2 (210ms)"}]}` |
| `GET /api/history` | Historique de toutes les frappes de la séance | `{"hits":[{"num":1,"pod":"Pod 2","col":"#00FFFF","rt":210,"t":1450}]}` |
| `POST /api/game` | Actions de jeu (Start, Pause, Stop, Mode) | `{"action":"START", "mode": 1}` |
| `POST /api/manual` | Allumage/extinction manuel d'un pod spécifique ou global | `{"action":"SET_POD", "podId":"12345", "color":"00FF00"}` |
| `POST /api/test` | Déclenchement de tests unitaires (Ping, LED, Logs) | `{"type":"PING"}`, `{"type":"LED"}`, `{"type":"CLEAR_LOGS"}` |
| `POST /api/settings` | Sauvegarde des réglages (Luminosité NVS, Redémarrage) | `{"brightness":80}`, `{"action":"RESTART"}` |
| `GET /api/export` | Fichier CSV prêt à télécharger | `Numero_Touche;Pod_ID;Couleur_RGB;Temps_Reaction_ms;Temps_Ecoule_s\n...` |

#### Détail des Champs Renvoyés par `/api/pods` :
* `id` : Identifiant unique 64 bits du microcontrôleur (adresse MAC sous forme d'entier).
* `name` : Nom lisible du pod (`Pod 1 (Master)`, `Pod 2`, `Pod 3`...).
* `isMaster` : `true` pour le nœud coordinateur hébergeant le serveur Web.
* `isTarget` : `true` si le pod est actuellement la cible allumée à frapper.
* `rssi` : Puissance du signal reçu en dBm ($0\text{ dBm}$ pour le Master local).
* `vBat` : Tension de batterie mesurée en Volts (précision $0.01\text{ V}$).
* `batPct` : Estimation du pourcentage de batterie restant ($0\text{--}100\,\%$).
* `charging` : `true` si le câble USB $5\text{V}$ est branché (recharge active).
* `online` : `true` si une trame radio a été reçue il y a $\le 12\text{ secondes}$, `false` si le pod est en veille ou éteint.
* `lastSeenSec` : Nombre de secondes écoulées depuis la dernière réception radio.
* `mac` : Adresse MAC formatée en hexadécimal standard (`XX:XX:XX:XX:XX:XX`).

---

## 💡 5. Extension du Protocole ESP-NOW pour le Mode Manuel & Tests

Pour supporter le contrôle manuel et les tests de diagnostic à distance, nous étendons les types de messages (`MsgType`) :

```cpp
enum MsgType {
  CMD_START,          // Démarrage jeu auto
  CMD_ACTIVATE,       // Activation d'une cible auto
  CMD_HIT,            // Confirmation de frappe
  CMD_PING,           // Découverte & mesure RTT/RSSI
  CMD_ACK,            // Réponse au ping
  CMD_RETURN_TO_MENU, // Arrêt & retour menu
  CMD_MANUAL_SET,     // Allumer un pod spécifique en mode manuel
  CMD_TEST_LEDS,      // Ordre de test visuel LED sur un pod distant
  CMD_POD_TELEMETRY   // Remontée de télémétrie périodique (Batterie, Charge)
};
```

---

## 🚀 6. Performance Mémoire & Portail Captif Résilient

### 6.1. Zéro Allocation Dynamique sur le Tas (PROGMEM Streaming)
* **Contrainte** : Le bundle HTML/CSS/JS complet mesure $\approx 75\text{ Ko}$. Sur ESP32, allouer une telle chaîne en RAM provoque immédiatement un épuisement du tas contigu (`heap fragmentation`), provoquant des réponses `Content-Length: 0` ou un reboot `LoadProhibited`.
* **Solution** : Le document entier est stocké en mémoire Flash morte via la macro `PROGMEM` :
  ```cpp
  static const char DASHBOARD_HTML[] PROGMEM = R"rawliteral(<!DOCTYPE html>...</html>)rawliteral";
  ```
  Le serveur utilise l'API de streaming zero-copy :
  ```cpp
  server.send_P(200, "text/html", DASHBOARD_HTML, sizeof(DASHBOARD_HTML) - 1);
  ```
  Les octets sont injectés directement depuis la Flash vers le contrôleur WiFi sans occuper un seul octet de RAM dynamique supplémentaire.

### 6.2. Configuration DNS Captive Portal sans Erreur
* **Compatibilité Multi-OS** :
  - `dnsServer.setErrorReplyCode(DNSReplyCode::NoError)` est activé pour renvoyer des réponses DNS valides même sur requêtes AAAA (IPv6) ou HTTPS (Type 65).
  - L'IP du serveur DNS est annoncée dans la configuration DHCP SoftAP (`WiFi.softAPConfig(apIP, apIP, subnet, IPAddress(192, 168, 4, 2), apIP)`).
  - Interception native des sondes captive Android, iOS, Windows et macOS avec redirection 302 descriptive.

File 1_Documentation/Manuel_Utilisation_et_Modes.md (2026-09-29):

# Manuel d'Utilisation & Guide des Modes de Jeu — Light Trainer V3

Ce manuel explique comment faire fonctionner vos pods **Light Trainer**, naviguer dans les menus grâce aux gestes sans contact et profiter des différents modes d'entraînement.

---

## 1. Démarrage Rapide

1. **Mise sous tension** :

   - Basculez l'interrupteur mécanique $SW_1$ sur la position **ON**.
   - Les pods s'allument instantanément en mode **MENU** (couleur du mode actif affichée sur les 7 LEDs).

2. **Synchronisation automatique** :

   - Les pods se découvrent mutuellement via le réseau sans fil maillé ESP-NOW dès l'allumage, sans aucune configuration WiFi nécessaire !

---

## 2. Contrôle Gestuel par Capteur ToF (VL53L0X)

L'intégralité du système se pilote par de simples mouvements de la main au-dessus du pod (portée $< 150\text{ mm}$), sans avoir à toucher physiquement le boîtier.

```
                  [ MAIN DU JOUEUR ]
                         ||
                      ( 15 cm )
                         ||
                 [ CAPTEUR ToF LASER ]
               +-----------------------+
               |  (O) (O) (O) (O) (O)  |  (Anneau 7 LEDs)
               +-----------------------+
```

### Table des Gestes :

| Geste | Durée | Action en Mode MENU | Action en Cours de JEU |
| :--- | :--- | :--- | :--- |
| **Tap Court** | $< 500\text{ ms}$ | **Changement de Mode** (Passe au mode suivant 0 $\rightarrow$ 1 $\rightarrow$ 2 $\rightarrow$ 3 $\rightarrow$ 4 $\rightarrow$ 0) | *Ignoré (évite les fausses frappes)* |
| **Maintien Démarrage (Hold 1.5s)** | $1.5\text{ s}$ | **Lancer la Partie** : Les 7 LEDs affichent une jauge circulaire progressive. À 100%, flash blanc et départ immédiat ! | *Non applicable* |
| **Frappe Rapide (Hit)** | $< 300\text{ ms}$ | *Ignoré* | **Validation de la Cible** : Flash blanc instantané ($60\text{ ms}$) et transmission radio au Master. |
| **Maintien Retour Menu (Hold 3s)** | $3.0\text{ s}$ | *Réinitialisation* | **Arrêter le Jeu & Retour au Menu** : Envoie un ordre d'arrêt synchronisé à tous les pods du réseau. |

---

## 3. Les Modes d'Entraînement Sportif

### 🟢 Mode 0 — Vitesse Simple (Solo Training)
* **Couleur de base** : Vert (`#00FF00`).
* **Délai entre cibles** : $0\text{ seconde}$ (activation instantanée de la cible suivante).
* **Déroulement** :
  1. Dès le départ, une cible s'allume en Vert.
  2. Le joueur frappe la cible.
  3. Dès la touche validée, une nouvelle cible s'allume instantanément sur un autre pod au hasard.
* **Objectif** : Vitesse pure, cardio et travail d'appuis.

---

### 🔴🟢 Mode 1 — Duel & Vitesse Bicolore (2 Joueurs)
* **Couleurs** : Joueur 1 = Rouge (`#FF0000`), Joueur 2 = Vert (`#00FF00`).
* **Délai entre cibles** : $0\text{ seconde}$ (réapparition instantanée).
* **Déroulement & Mécanique Compétitive** :
  1. Dès le départ, **deux pods s'allument simultanément** : l'un en Rouge (pour le Joueur 1), l'autre en Vert (pour le Joueur 2).
  2. Chaque joueur se concentre sur sa propre couleur.
  3. Dès que le Joueur 1 éteint la cible Rouge, **une nouvelle cible Rouge s'allume instantanément** sur un autre pod disponible, sans affecter la cible Verte qui reste allumée !
  4. De la même façon, dès que le Joueur 2 éteint la cible Verte, celle-ci réapparaît immédiatement sur un autre pod.
  5. Il y a donc en permanence deux couleurs actives sur le terrain, permettant une course aux points effrénée et continue.
* **Objectif** : Compétition directe 1 contre 1, vision périphérique et discrimination visuelle sous pression.

---

### 🔵 Mode 2 — Réflexe & Attention Aléatoire
* **Couleur de base** : Bleu (`#0000FF`).
* **Délai aléatoire** : Entre $0.5\text{ seconde}$ et $5\text{ secondes}$.
* **Déroulement** :
  1. Après extinction d'une cible, un temps mort imprévisible s'écoule.
  2. Soudainement, un pod s'allume en Bleu.
* **Objectif** : Temps de réaction au stimulus imprévisible, concentration et posture d'attente active.

---

### 🟡🟣 Mode 3 — Agilité Cognitive & Coordination
* **Couleurs** : Jaune (`#FFFF00`) et Magenta (`#FF00FF`).
* **Délai aléatoire** : Entre $0\text{ s}$ et $4\text{ secondes}$.
* **Déroulement** :
  - Les cibles alternent entre des couleurs différentes imposant des règles motrices (ex: Jaune = main droite / pied droit, Magenta = main gauche / pied gauche).
* **Objectif** : Agilité motrice, coordination et dissociation droite/gauche.

---

### 🔴🟡🔵 Mode 4 — Jeu Simon (Mémoire Séquentielle & Accélération)
* **Couleur de base / Représentation** : Rose système (`#FF2D55`). Chaque pod de la flotte dispose d'une couleur signature unique :
  - Pod 1 (Master) : Vert (`#30D158`)
  - Pod 2 : Rouge (`#FF453A`)
  - Pod 3 : Bleu (`#0A84FF`)
  - Pod 4 : Jaune (`#FFD60A`)
  - Pod 5 : Magenta (`#BF5AF2`)
  - Pod 6 : Cyan (`#30B0C7`)
  *(Si 1 seul pod est connecté, les couleurs alternent séquentiellement sur l'anneau central du Master).*
* **Déroulement** :
  1. **Phase Démonstration** : Les pods s'allument l'un après l'autre selon une séquence générée dynamiquement.
  2. **Phase Joueur** : Le joueur doit reproduire la séquence exacte en frappant les pods dans le bon ordre.
  3. **Progression & Accélération** : À chaque manche réussie, flash vert général, la séquence gagne $+1$ étape et la vitesse de démonstration s'accélère automatiquement selon le coefficient configuré (ex. $-6\%$ par tour).
  4. **Fin de Partie** : En cas d'erreur de frappe ou d'inactivité ($>5\text{ s}$), flash rouge général et enregistrement du score record.
* **Objectif** : Mémoire de travail sous effort, lucidité et vitesse de mémorisation spatiale.

---

## 4. Signaux Lumineux de la Batterie & Recharge

| Couleur des LEDs | Signification | Action Recommandée |
| :--- | :--- | :--- |
| 🟠 **Orange Fixe** | **Câble USB branché** (Recharge de la batterie LiPo en cours). | Laisser branché jusqu'à charge complète. |
| 🔴 **Rouge Clignotant** | **Batterie Faible** ($V_{\text{batt}} < 3.4\text{ V}$, reste environ 10%). | Rebrancher le pod sur un chargeur USB-C. |
| 🔴 **Rouge Fixe puis Extinction** | **Coupure Critique** ($V_{\text{batt}} \le 3.0\text{ V}$). | Le pod se met en sécurité pour préserver la chimie LiPo. |

### Suivi de la Batterie de Toute la Flotte via le Web :
Dans l'onglet **Diagnostics** du portail Web, la section **"Batterie de toute la flotte"** centralise en temps réel :
* La tension exacte ($V$) et le pourcentage restant ($\%$) de chaque pod du maillage.
* Le statut de charge USB (`⚡ Charge USB`).
* L'état de présence : les pods éteints ou en veille prolongée sont signalés par la mention *"💤 En veille"* avec le temps écoulé depuis la dernière émission radio.

---

## 5. Portail Web de Configuration & Entraînement

En plus des gestes physiques ToF, le Light Trainer intègre un portail Web complet et réactif accessible sans installation depuis n'importe quel smartphone, tablette ou ordinateur :

1. Connectez votre appareil au réseau WiFi diffusé par le pod maître : **`LightTrainer_Config`** (ou `LightTrainer`).
2. Ouvrez votre navigateur internet à l'adresse : **`http://192.168.4.1`** (le portail captif s'ouvre généralement automatiquement).
3. Vous disposez alors de 4 espaces de contrôle :
   - **🎯 Entraînement Automatique** : Lancez et pilotez à distance les 5 modes d'entraînement (Vitesse Solo, Duel Bicolore, Réflexe Aléatoire, Agilité Cognitive, Jeu Simon), avec chronomètre géant, graphiques de temps de réaction et analyse comparative Duel / Simon.
   - **🕹️ Mode Manuel Coach** : Allumez n'importe quel pod à la couleur de votre choix d'un simple toucher sur votre écran, mesurez le temps mis par l'athlète pour frapper le pod ordonné, ou déclenchez des flashs d'alerte généraux.
   - **🧪 Tests & Diagnostic** : Visualisez la distance mesurée par le capteur ToF en millimètres, lancez un test de ping radio ESP-NOW mesurant le temps d'aller-retour ($RTT$) et le niveau de signal ($RSSI$) de chaque pod, et contrôlez l'état de batterie de toute la flotte.
   - **⚙️ Réglages & Export CSV** : Réglez la luminosité globale des LEDs ($10\%$ à $100\%$, mémorisée en Flash NVS), consultez la console de logs en direct, et exportez l'historique complet des frappes de votre séance d'entraînement au format CSV.

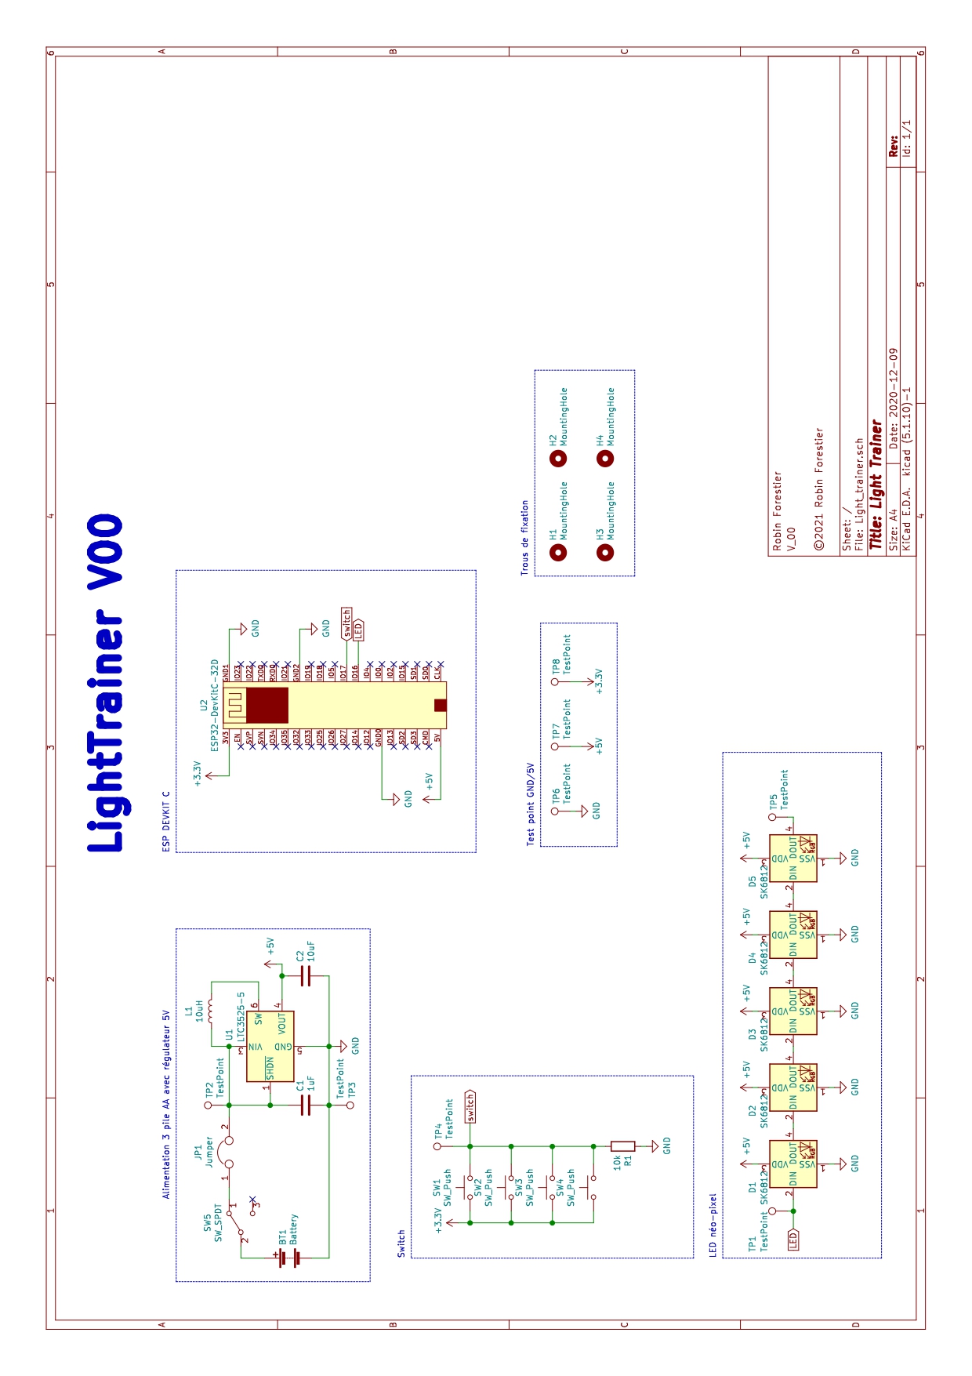
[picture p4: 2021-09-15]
1_Documentation/Wiki/SCHEMATICS_V1.jpg

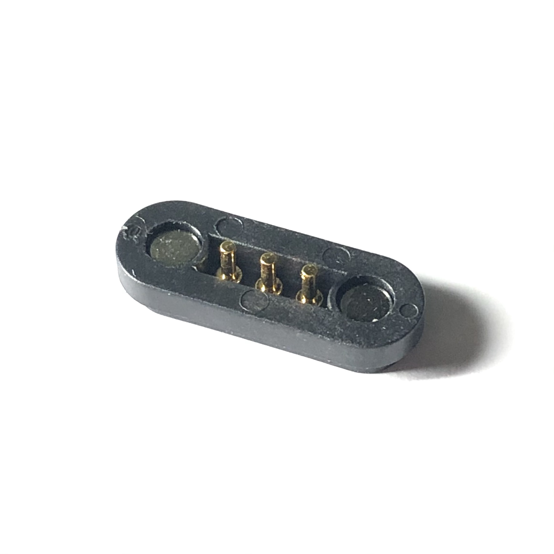
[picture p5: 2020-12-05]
1_Documentation/Photos/Conn_2.JPEG

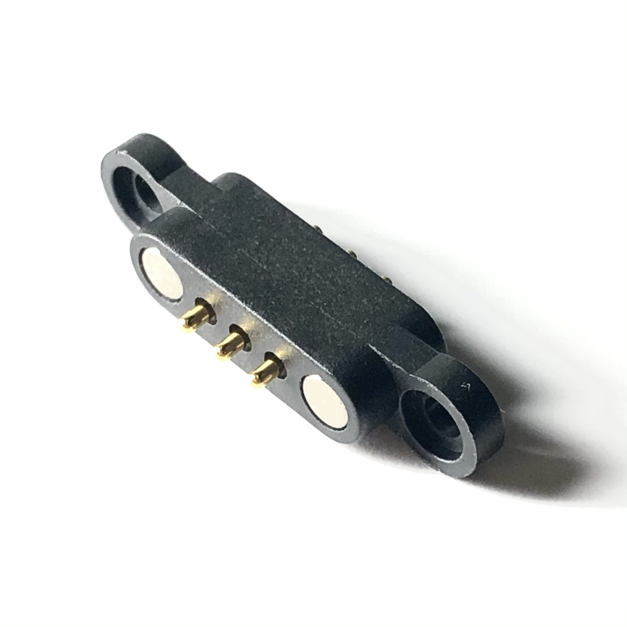
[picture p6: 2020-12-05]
1_Documentation/Photos/Conn_3.JPEG

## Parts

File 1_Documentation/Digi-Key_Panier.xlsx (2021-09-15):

Index | Quantité | Référence | Référence fabricant | Description | Référence client | Disponible | Articles différés | Prix unitaire | Prix calculé CHF
1 | 5 | 1965-1000-ND | ESP32-DEVKITC-32D | EVAL BOARD FOR ESP-WROOM-32 |  | 5 | 0 | 9,1 | 45,50 Fr.
2 | 5 | MCP1825S-5002E/DB-ND | MCP1825S-5002E/DB | IC REG LINEAR 5V 500MA SOT223-3 |  | 5 | 0 | 0,57000 | 2,85 Fr.
3 | 3 | 1528-1104-ND | 1655 | ADDRESS LED DISC SERIAL RGB 1=10 |  | 3 | 0 | 4,10000 | 12,30 Fr.
4 | 20 | CH160-ND | MX1A-11NW | SWITCH PUSH SPST-NO 0.01A 12V |  | 20 | 0 | 0,80600 | 16,12 Fr.
5 | 5 | LTC3525ESC6-5#TRMPBFCT-ND | LTC3525ESC6-5#TRMPBF | IC REG BOOST 5V 175MA SC70-6 |  | 5 | 0 | 4,45000 | 22,25 Fr.
6 | 5 | 36-2464-ND | 2464 | BATTERY HOLDER AA 3 CELL PC PIN |  | 5 | 0 | 1,56000 | 7,80 Fr.
7 | 5 | 1276-6471-1-ND | CL21B105KOFNNNG | CAP CER 1UF 16V X7R 0805 |  | 5 | 0 | 0,09 | 0,45 Fr.
8 | 5 | 1276-6455-1-ND | CL21A106KOQNNNG | CAP CER 10UF 16V X5R 0805 |  | 5 | 0 | 0,10000 | 0,50 Fr.
9 | 5 | 587-3064-1-ND | CBC3225T100KR | FIXED IND 10UH 900MA 172.9 MOHM |  | 5 | 0 | 0,27000 | 1,35 Fr.
10 | 5 | RNCP1206FTD10K0CT-ND | RNCP1206FTD10K0 | RES 10K OHM 1% 1/2W 1206 |  | 5 | 0 | 0,09000 | 0,45 Fr.
11 | 5 | CKN10602-ND | 1101M2S5CQE2 | SWITCH SLIDE SPDT 6A 120V |  | 5 | 0 | 5,29000 | 26,45 Fr.

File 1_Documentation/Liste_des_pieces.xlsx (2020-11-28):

Nom | Vendeur | prix unitaire | nombres | prix total | Liens
Geekcreit® ESP32 | Bangood | 8.30 CHF | 2 | 16.60 CHF | https://www.banggood.com/fr/Geekcreit-ESP32-WiFi+bluetooth-Development-Board-Ultra-Low-Power-Consumption-Dual-Cores-Pins-Unsoldered-p-1214159.html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
Batterie Charger 10x | Bangood | 3.70 CHF | 1 | 3.70 CHF | https://www.banggood.com/fr/10-Pcs-TP4056-Micro-USB-5V-1A-Lithium-Battery-Charging-Module-Board-TE585-Lipo-Charger-p-1255764.html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
Batterie Module indicateur | Bangood | 1.60 CHF | 2 | 3.20 CHF | https://www.banggood.com/fr/1S-8S-Single-3_7V-Lithium-Battery-Capacity-Indicator-Module-4_2V-Blue-Display-Electric-Vehicle-Battery-Power-Tester-Li-ion-p-17474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
LiPo 750mAh Eachine | Bangood | 5.70 CHF | 2 | 11.40 CHF | https://www.banggood.com/fr/Eachine-3_7V-750mah-25C-Lipo-Battery-for-Eachine-QX95-QX90-QX80-E30-E30W-Syma-X5-X5C-X5SC-X5SW-CX30W-p-995494.html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
Connecteur a ressort 5x | AliExpresse | 10.86 CHF | 1 | 10.86 CHF
 |  | 0.00 CHF | 0 | 0.00 CHF
 |  | 0.00 CHF | 0 | 0.00 CHF
 |  | 0.00 CHF | 0 | 0.00 CHF
 |  | 0.00 CHF | 0 | 0.00 CHF
 |  | 0.00 CHF | 0 | 0.00 CHF
 |  | 0.00 CHF | 0 | 0.00 CHF
 |  | 0.00 CHF | 0 | 0.00 CHF
 |  | 0.00 CHF | 0 | 0.00 CHF
 |  | 0.00 CHF | 0 | 0.00 CHF
 |  | 0.00 CHF | 0 | 0.00 CHF
 |  | 0.00 CHF | 0 | 0.00 CHF
 |  | 0.00 CHF | 0 | 0.00 CHF
 |  | 0.00 CHF | 0 | 0.00 CHF
 |  | 0.00 CHF | 0 | 0.00 CHF
 |  | 0.00 CHF | 0 | 0.00 CHF
 |  | 0.00 CHF | 0 | 0.00 CHF
 |  | 0.00 CHF | 0 | 0.00 CHF
 |  | 0.00 CHF | 0 | 0.00 CHF
 |  | 0.00 CHF | 0 | 0.00 CHF
 |  | 0.00 CHF | 0 | 0.00 CHF
 |  | 0.00 CHF | 0 | 0.00 CHF
Total |  |  |  | 45.76 CHF

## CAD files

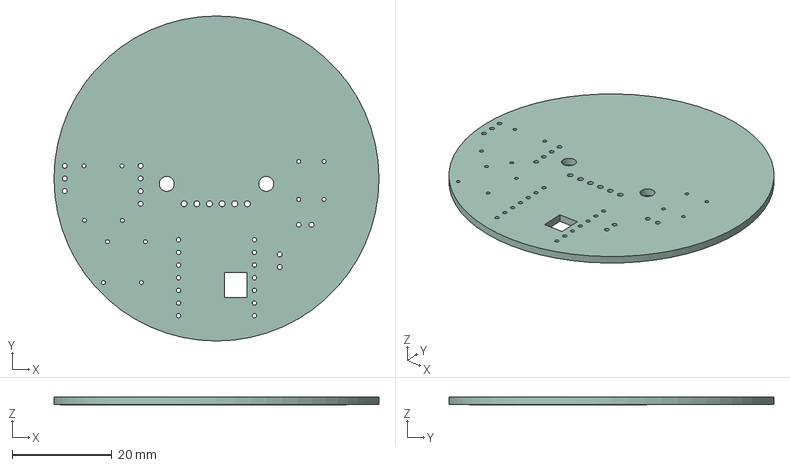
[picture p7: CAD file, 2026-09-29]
4_Fabrication/Version_02/light_trainer/shapes3D/LIGHT_TRAINER_PCB.step
65.3 x 65.3 x 1.54 mm
light_trainer_copper
light_trainer_PCB

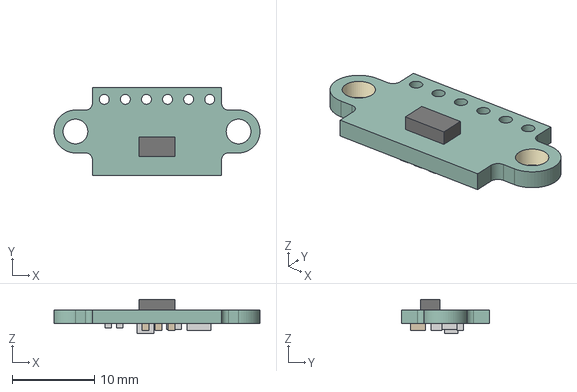
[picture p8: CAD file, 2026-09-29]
4_Fabrication/Version_02/light_trainer/shapes3D/VL53L0_1XV2.step
25.0 x 10.7 x 4.15 mm

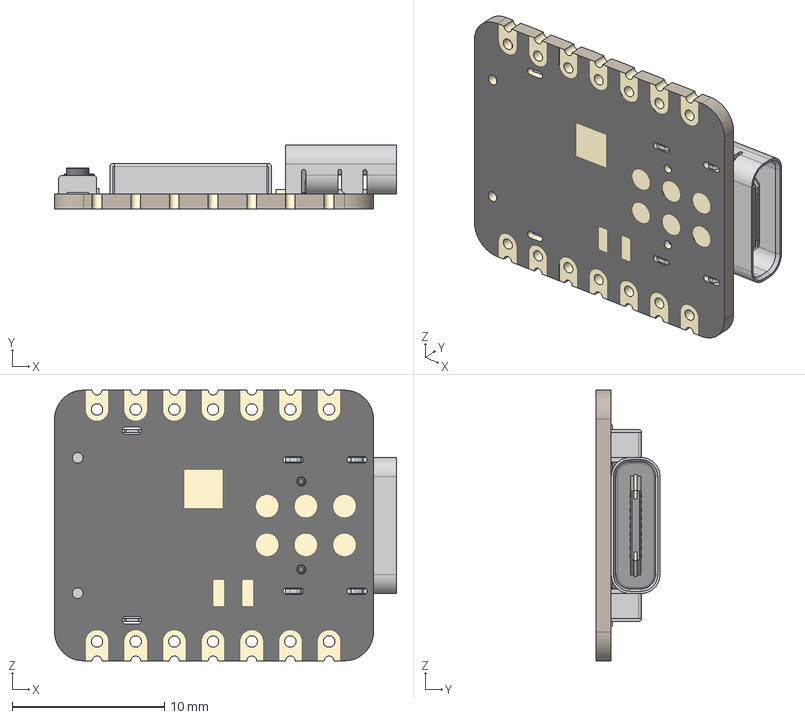
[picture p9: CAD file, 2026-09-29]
4_Fabrication/Version_02/light_trainer/shapes3D/Seeed Studio XIAO-ESP32-C3.step
22.5 x 4.21 x 17.8 mm
BOSS-EXTRUDE14_8_
BOSS-EXTRUDE7_4_
BOSS-EXTRUDE7_3_
BOSS-EXTRUDE14_4_
BOSS-EXTRUDE14_2_
BOSS-EXTRUDE14_11_
BOSS-EXTRUDE7_7_
BOSS-EXTRUDE14_9_
BOSS-EXTRUDE14_3_
BOSS-EXTRUDE14_7_
MIRROR2
BOSS-EXTRUDE14_5_
BOSS-EXTRUDE14_12_
BOSS-EXTRUDE7_8_
BOSS-EXTRUDE7_1_
BOSS-EXTRUDE14_10_
BOSS-EXTRUDE7_9_
BOSS-EXTRUDE14_6_
BOSS-EXTRUDE14_1_
BOSS-EXTRUDE7_6_
BOSS-EXTRUDE7_2_
CUT-EXTRUDE5
BOSS-EXTRUDE7_5_
U.FL Connector v1
Button (1) x 2
Shield

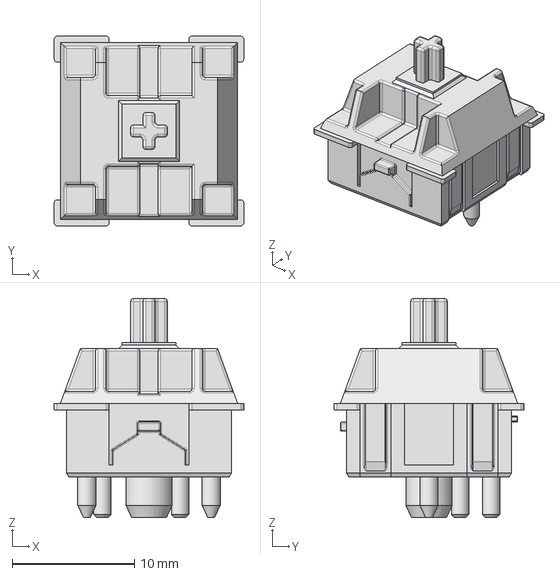
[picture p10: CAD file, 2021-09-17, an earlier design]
4_Fabrication/Version_00/C_KiCAD/Light_trainer_v1/shapes3D/Cherry_-_MX1A-11NW.step
15.5 x 15.5 x 17.9 mm

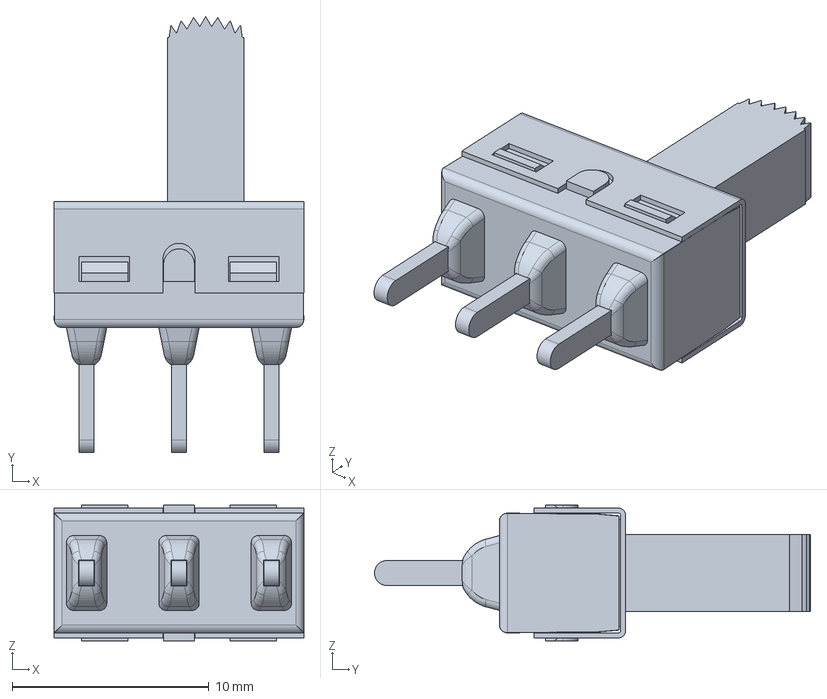
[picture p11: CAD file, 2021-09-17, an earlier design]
4_Fabrication/Version_00/C_KiCAD/Light_trainer_v2/shapes3D/1101M2S5CQE2.stp
12.7 x 22.2 x 6.91 mm

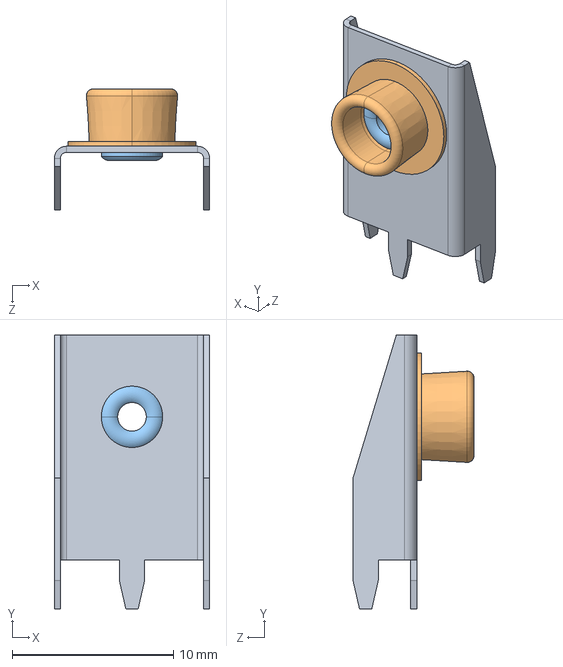
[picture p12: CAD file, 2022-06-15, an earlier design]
4_Fabrication/Version_01/C_KiCAD/Light_trainer_v1/shapes3D/keystone-PN593.STEP
9.65 x 17.0 x 7.52 mm

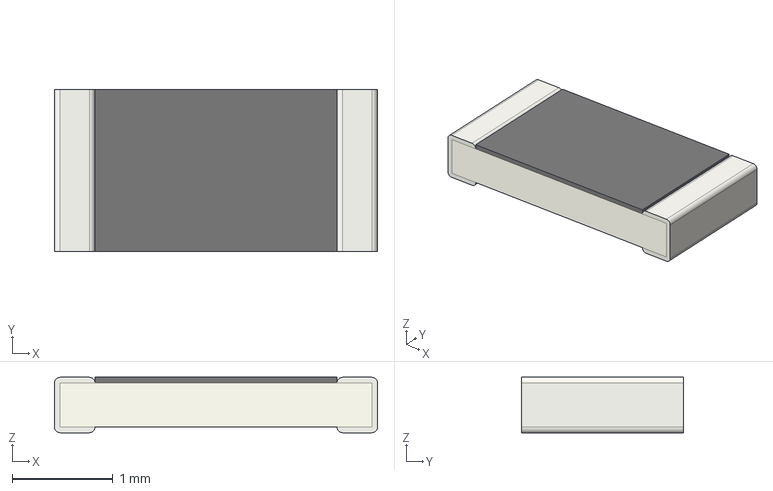
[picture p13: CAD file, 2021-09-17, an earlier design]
4_Fabrication/Version_00/C_KiCAD/Light_trainer_v1/shapes3D/R_1206_3216Metric.step
3.20 x 1.60 x 0.55 mm

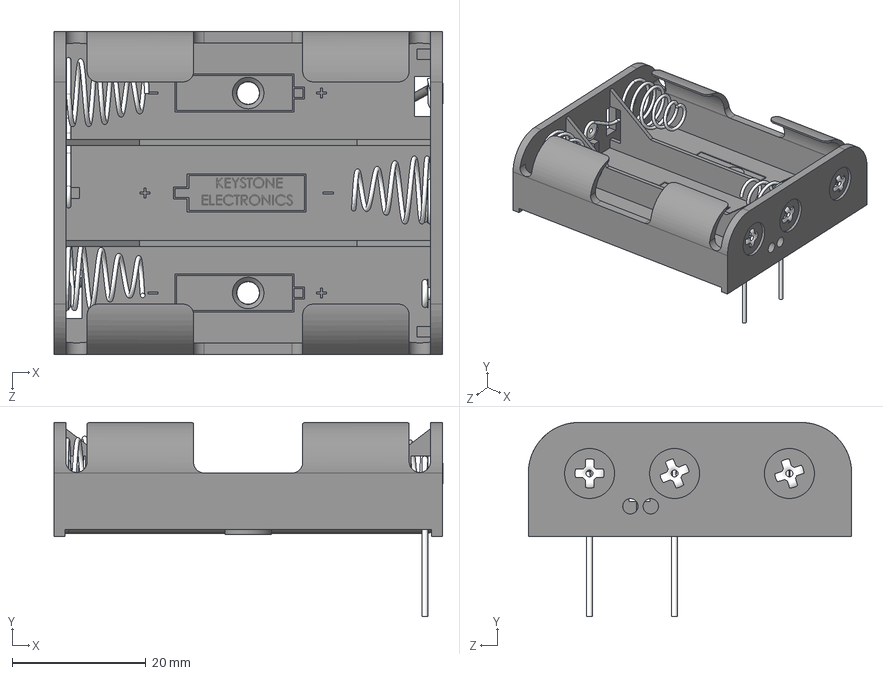
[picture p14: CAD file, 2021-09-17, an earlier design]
4_Fabrication/Version_00/C_KiCAD/Light_trainer_v2/shapes3D/keystone-PN2464.step
58.1 x 29.0 x 48.3 mm

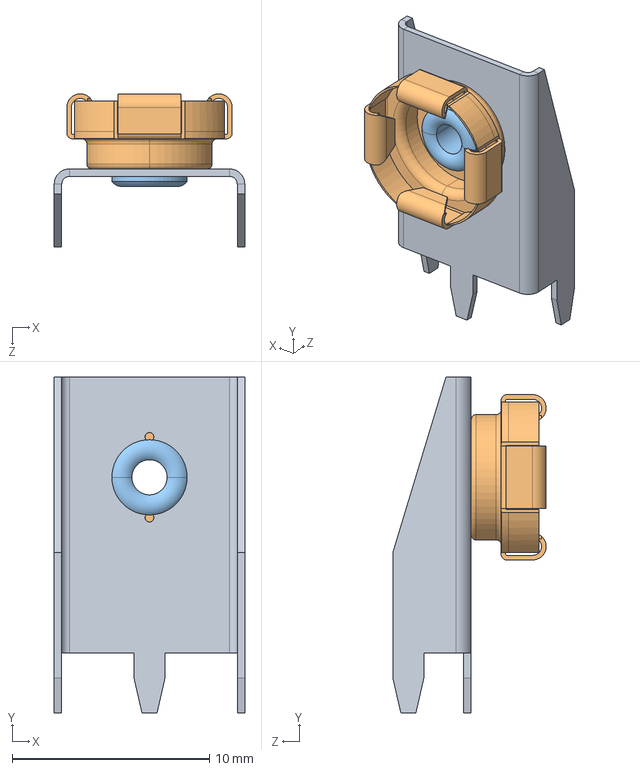
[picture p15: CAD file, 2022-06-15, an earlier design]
4_Fabrication/Version_01/C_KiCAD/Light_trainer_v1/shapes3D/keystone-PN594.step
9.65 x 17.0 x 7.77 mm

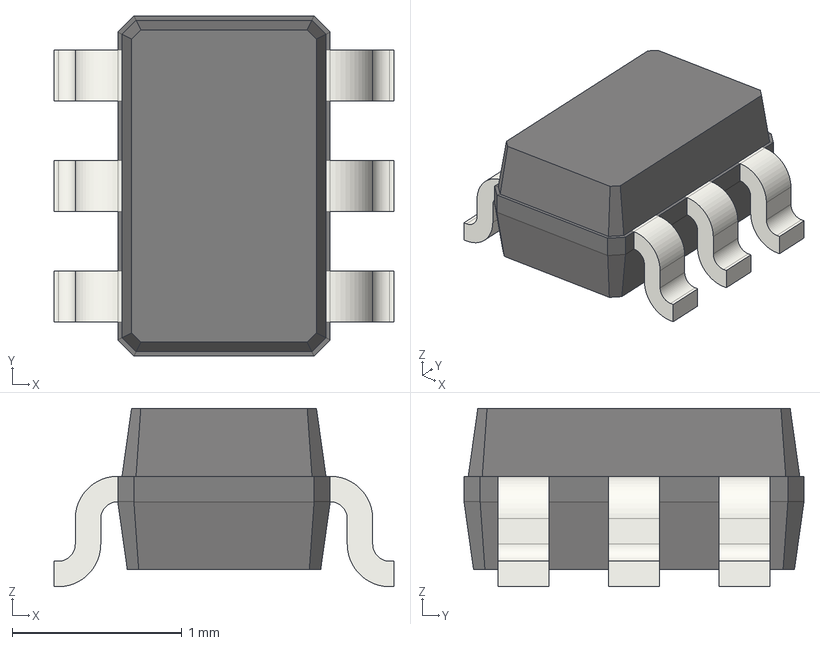
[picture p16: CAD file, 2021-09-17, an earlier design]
4_Fabrication/Version_00/C_KiCAD/Light_trainer_v1/shapes3D/SOT-363_SC-70-6.step
2.00 x 2.00 x 1.05 mm

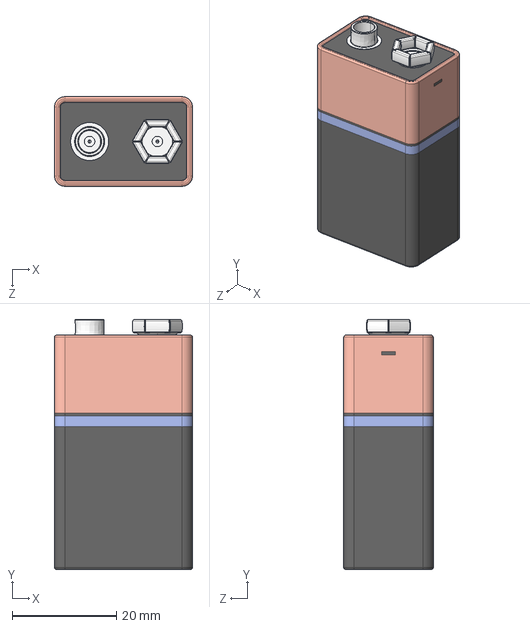
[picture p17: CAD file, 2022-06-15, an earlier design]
4_Fabrication/Version_01/C_KiCAD/Light_trainer_v1/shapes3D/9V Battery.STEP
26.5 x 48.0 x 17.2 mm

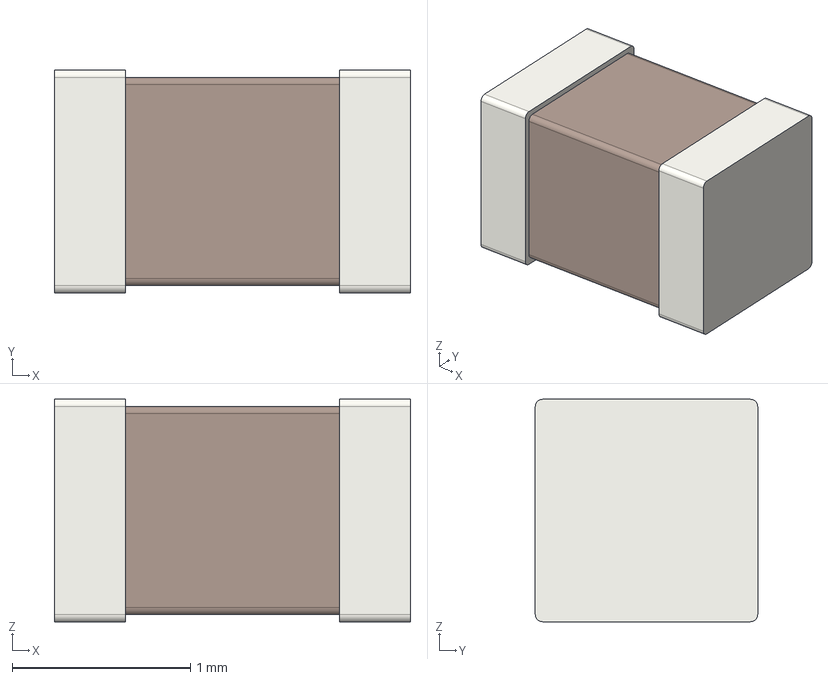
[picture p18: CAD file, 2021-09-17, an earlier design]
4_Fabrication/Version_00/C_KiCAD/Light_trainer_v1/shapes3D/C_0805_2012Metric.step
2.00 x 1.25 x 1.25 mm

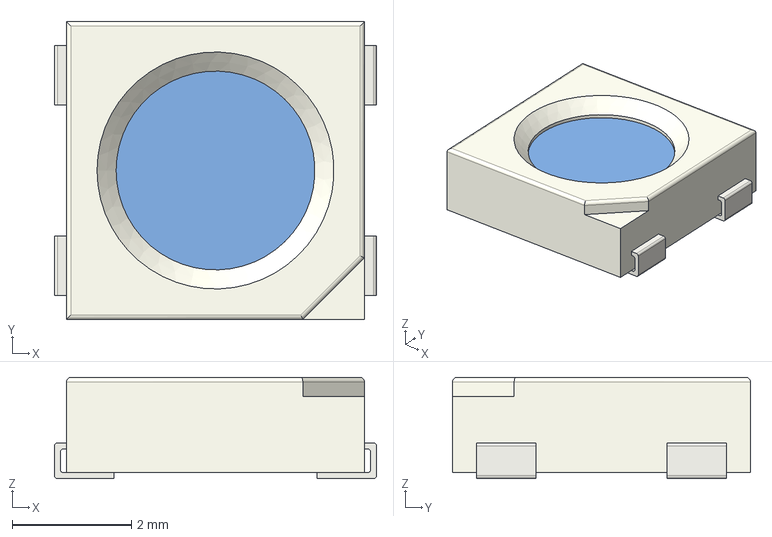
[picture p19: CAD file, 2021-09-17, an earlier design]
4_Fabrication/Version_00/C_KiCAD/Light_trainer_v2/shapes3D/LED_SK6812_PLCC4_5.0x5.0mm_P3.2mm.step
5.40 x 5.00 x 1.70 mm

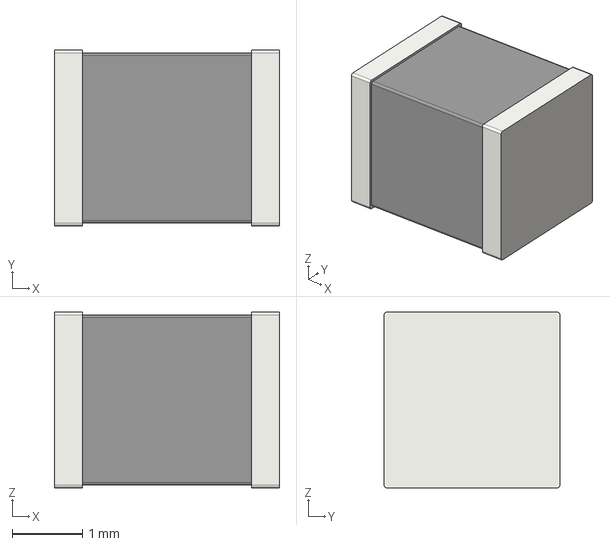
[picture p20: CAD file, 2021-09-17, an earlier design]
4_Fabrication/Version_00/C_KiCAD/Light_trainer_v1/shapes3D/L_1210_3225Metric.step
3.20 x 2.50 x 2.50 mm

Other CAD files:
4_Fabrication/Version_01/D_LIBS/629105150521.stp

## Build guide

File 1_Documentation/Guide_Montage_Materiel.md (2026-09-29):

# Guide de Montage & Fabrication Matérielle — Light Trainer V3

Ce guide détaille les étapes de montage, le schéma de câblage et la liste des composants (BOM) pour fabriquer un prototype **Veroboard** ou assembler le **PCB V3**.

---

## 1. Liste des Composants (BOM - Bill of Materials)

Pour fabriquer **1 Pod Light Trainer V3**, vous avez besoin de :

| Réf. Schéma | Désignation | Spécifications | Quantité | Rôle dans le circuit |
| :--- | :--- | :--- | :--- | :--- |
| **`U1`** | **Seeed Studio XIAO ESP32-C3** | Microcontrôleur WiFi/BLE + chargeur LiPo | 1 | Cerveau du pod, gestion RF et I/O |
| **`U2`** | **VL53L0X** | Module télémètre laser ToF (I2C) | 1 | Détection gestuelle sans contact |
| **`D1`..`D7`** | **Anneau LEDs WS2812B** | 7 LEDs RGB adressables 5050 (ou ruban) | 1 | Éclairage, jauges et animations visuelles |
| **`BT1`** | **Batterie LiPo 3.7V** | 1S (ex: 500 mAh à 1200 mAh avec protection) | 1 | Alimentation autonome nomade |
| **`SW1`** | **Interrupteur à glissière SPDT** | 1 pôle, 2 directions (ON/OFF) | 1 | Interrupteur matériel marche/arrêt |
| **`R1` à `R6`** | **Résistances $100\text{ k}\Omega$** | $1/4\text{ W}$, tolérance 1% ou 5% | **6** | Ponts diviseurs et pull-down unifiés |
| **`C1`** | **Condensateur $100\text{ nF}$** | Céramique multicouche (100nF / 50V) | 1 | Filtrage HF de la mesure ADC batterie |
| **`VERO`** | **Plaque d'essai Veroboard** | À bandes cuivrées ou à pastilles | 1 | Support mécanique et électrique |
| **`FILS`** | **Fils de câblage souples** | 28 AWG / 30 AWG (Siliconés recommandés) | Q.S. | Connexions inter-modules |

> [!TIP]
> **Uniformité des résistances** : Toutes les résistances ($R_1$ à $R_6$) ont été unifiées à la valeur standard **$100\text{ k}\Omega$**. Vous n'avez besoin que d'une seule référence de résistance pour l'ensemble du projet !

---

## 2. Schéma Électrique Détaillé

Le schéma complet est disponible au format PDF dans [`1_Documentation/DOC_FAB/schema.pdf`](file:///c:/Users/Robin/Desktop/GitHub/Light_trainer/1_Documentation/DOC_FAB/schema.pdf).

### Vue d'Ensemble des Blocs Fonctionnels :

```
             +-------------------------------------------------------+
             |               Seeed Studio XIAO ESP32-C3              |
             |                                                       |
 [BAT+] ---->| (Pad 21) BAT+                             3V3_OUT (12)|----+
 [BAT-] ---->| (Pad 22) GND                                 VBUS (14)|--+ |
             |                                                       |  | |
             | (D1 / Pin 2)  BAT_ADC                         GND (13)|  | |
             | (D2 / Pin 3)  SW_PIN / WAKEUP                         |  | |
             | (D4 / Pin 5)  SCL                                     |  | |
             | (D5 / Pin 6)  SDA                                     |  | |
             | (D7 / Pin 8)  LED_DATA                                |  | |
             | (D10 / Pin 11) CHARGE_PIN                             |  | |
             +-------------------------------------------------------+  | |
                                                                        | |
  +---------------------------------------------------------------------+ |
  | (Ligne VBUS 5V)                                                       |
  |                                                                       |
  +--[ R4: 100k ]----+----> Broche D10 (Détection USB)                   |
                     |                                                    |
             [ R5+R6: 200k ] (2x 100k en série)                           |
                     |                                                    |
                    GND                                                   |
                                                                          |
  +-----------------------------------------------------------------------+
  | (Ligne 3V3_OUT)
  |
  +----[ Broche 2 de SW1 ]
         [ Broche 1 de SW1 ] ----+---> Rail 3V3_S (Alimentation commutée)
                                 |
                                 +---> Broche D2 (Détection ON/OFF & Wakeup)
                                 |
                             [ R3: 100k ] (Pull-down)
                                 |
                                GND

  Ligne Batterie BAT+
  |
  +--[ R1: 100k ]----+----> Broche D1 (Mesure ADC Batterie)
                     |
               +-----+-----+
               |           |
           [ R2: 100k ] [ C1: 100nF ]
               |           |
               +-----+-----+
                     |
                    GND
```

---

## 3. Instructions de Montage Pas-à-Pas (Veroboard)

### Étape 1 : Préparation du XIAO ESP32-C3

1. Retournez le XIAO ESP32-C3 pour accéder aux pastilles de soudure de batterie sous la carte :
   - Soudez le fil **ROUGE (+)** de la batterie sur le pad **`BAT+`** (Pin 21).
   - Soudez le fil **NOIR (-)** de la batterie sur le pad **`GND`** (Pin 22).
2. Soudez deux rangées de connecteurs mâles (ou soudez directement les fils sur les pastilles latérales `D0` à `D10`).

### Étape 2 : Câblage de l'Interrupteur $SW_1$ & Rail $3\text{V}3\_S$

1. Connectez la **broche centrale (Broche 2)** de l'interrupteur $SW_1$ à la broche **`3V3_OUT`** (Pin 12) du XIAO.
2. Connectez la **broche de sortie (Broche 1)** de $SW_1$ au rail d'alimentation commuté nommé **`3V3_S`**.
3. Reliez ce rail `3V3_S` à :
   - La broche **`D2`** du XIAO (signal de réveil / détection d'état).
   - Une résistance de pull-down **$R_3 = 100\text{ k}\Omega$** reliée à la masse `GND`.
   - La broche **`VIN`** du capteur VL53L0X.
   - La broche **`VDD / +5V`** de l'anneau de LEDs WS2812B.

### Étape 3 : Câblage des Ponts Diviseurs

1. **Pont de mesure batterie (Broche D1)** :
   - Connectez **$R_1$ ($100\text{ k}\Omega$)** entre `BAT+` et `D1`.
   - Connectez **$R_2$ ($100\text{ k}\Omega$)** et **$C_1$ ($100\text{ nF}$)** en parallèle entre `D1` et `GND`.
2. **Pont de détection charge USB (Broche D10)** :
   - Connectez **$R_4$ ($100\text{ k}\Omega$)** entre `VBUS` (Pin 14) et `D10`.
   - Mettez **deux résistances $100\text{ k}\Omega$ en série ($R_5 + R_6 = 200\text{ k}\Omega$)** entre `D10` et `GND`.

### Étape 4 : Raccordement des Périphériques

1. **Capteur ToF VL53L0X** :
   - `VIN` $\rightarrow$ Rail `3V3_S`
   - `GND` $\rightarrow$ `GND`
   - `SCL` $\rightarrow$ Broche **`D4`** du XIAO
   - `SDA` $\rightarrow$ Broche **`D5`** du XIAO
2. **Anneau de LEDs WS2812B (7 LEDs)** :
   - `DIN` $\rightarrow$ Broche **`D7`** du XIAO
   - `VDD` $\rightarrow$ Rail `3V3_S`
   - `GND` $\rightarrow$ `GND`

---

## 4. Points de Contrôle Avant Mise sous Tension

Avant de brancher la batterie LiPo ou le câble USB, effectuez les contrôles suivants au multimètre en mode continuité (bip) :

1. [ ] **Pas de court-circuit `BAT+` / `GND`** : Résistance infinie ou $> 100\text{ k}\Omega$.
2. [ ] **Pas de court-circuit `3V3_OUT` / `GND`**.
3. [ ] **Pas de court-circuit `VBUS` / `GND`**.
4. [ ] **Fonctionnement de l'interrupteur $SW_1$** :
   - En position **ON** : Continuité entre `3V3_OUT` et `3V3_S`.
   - En position **OFF** : Résistance de $100\text{ k}\Omega$ entre `3V3_S` et `GND` (due à $R_3$).
5. [ ] **Tension sur D10 avec câble USB branché** : Doit être de **$\approx 3.33\text{ V}$** (diviseur 5V par 100k / 200k).
6. [ ] **Tension sur D1 avec batterie à 4.0V** : Doit être de **$\approx 2.00\text{ V}$** (diviseur 100k / 100k).

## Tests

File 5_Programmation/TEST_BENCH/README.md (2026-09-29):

# Banc de Tests et Qualification Matérielle - Light Trainer V3

Ce banc de test (`TEST_BENCH.ino`) est conçu pour mesurer et qualifier avec précision les performances réelles de votre prototype Light Trainer V3 (Veroboard / PCB V3 avec XIAO ESP32-C3).

---

## 📋 Comment utiliser le Banc de Test ?

1. Ouvrez `5_Programmation/TEST_BENCH/TEST_BENCH.ino` dans l'IDE Arduino.
2. À la ligne 30, choisissez le test que vous souhaitez effectuer avec `#define CURRENT_TEST` :
   ```cpp
   #define CURRENT_TEST TEST_TOF_BENCHMARK
   ```
3. Téléversez le code dans le XIAO ESP32-C3.
4. Ouvrez le **Moniteur Série Arduino** réglé à **115200 bauds** (ou le Traceur Série pour les graphiques).

---

## 🧪 Description des Tests Disponibles

### 1. `TEST_BATTERY_STRESS` — Décharge Maximale (Pire Cas)
* **Conditions de test** :
  - 7 LEDs blanches à 100% de puissance (`RGB = 255, 255, 255`).
  - Transmission radio ESP-NOW continue à 20 paquets / seconde.
  - Télémètre ToF VL53L0X en lecture continue à 50 Hz.
* **Consommation estimée** : ~450 mA à 500 mA.
* **Format de sortie (CSV prêt pour Excel)** :
  ```csv
  Temps_s; Horodatage; Tension_mV; Pourcentage_pct; USB
  0; 00:00:00; 4180; 98; NON
  5; 00:00:05; 4165; 97; NON
  ...
  ```
* **Objectif** : Mesurer l'autonomie minimale absolue de la batterie LiPo et tracer la courbe de décharge sous forte charge. Coupure automatique à 3.0V pour préserver la batterie.

---

### 2. `TEST_BATTERY_GAME_SIM` — Décharge en Session de Jeu Réelle
* **Conditions de test** :
  - Luminosité nominale (50 / 255).
  - Alternance dynamique des couleurs et flashs courts (60 ms).
  - Échanges radio ESP-NOW réalistes.
* **Consommation estimée** : ~80 mA à 120 mA moyen.
* **Objectif** : Valider l'autonomie réelle en entraînement sportif (objectif : **> 3 à 5 heures**).

---

### 3. `TEST_TOF_BENCHMARK` — Qualification ToF, Frappes & Perturbations Solaires
* **Fonctionnalités** :
  - **Mesure de distance en temps réel** (mm) à 50 Hz.
  - **Compteur de Hits validés** avec calcul de la durée de frappe (ms) et de la cadence (hits/minute).
  - **Détection des perturbations solaires / optiques** : comptabilise les erreurs optiques et les pertes de signal dues aux infrarouges du soleil.
  - **Retour visuel dynamique** :
    - Jauge bleue progressive à l'approche de la main (150 mm à 500 mm).
    - Jauge verte en zone active (< 150 mm).
    - **Flash blanc instantané** lors de la validation d'un Hit.
* **Objectif** :
  - Mesurer la réactivité (latence < 30 ms).
  - Tester en extérieur sous plein soleil pour mesurer le taux d'erreur optique.

---

### 4. `TEST_RADIO_PING_RTT_RSSI` — Portée Radio, Latence & Force du Signal
* **Configuration** :
  - Flashé sur **Pod 1** avec `#define RADIO_ROLE ROLE_PINGER`
  - Flashé sur **Pod 2** avec `#define RADIO_ROLE ROLE_PONGER`
* **Métriques mesurées** :
  - **Latence RTT (Round Trip Time)** : temps aller-retour en millisecondes.
  - **Force du signal RSSI** : niveau en dBm mesuré en réception.
  - **Taux de perte de paquets (Packet Loss %)** : pourcentage d'échecs.
* **Indicateur LED de qualité du signal en direct** :
  - 🟢 **Vert** : Signal excellent ($> -65\text{ dBm}$)
  - 🟡 **Jaune** : Signal moyen ($-65\text{ dBm}$ à $-80\text{ dBm}$)
  - 🔴 **Rouge** : Signal faible / limite de décrochage ($< -85\text{ dBm}$)
* **Objectif** : Éloigner les pods pour trouver la distance maximale en champ libre et en intérieur à travers des murs.

---

### 5. `TEST_DEEP_SLEEP_POWER` — Interrupteur ON/OFF & Veille Profonde
* **Fonctionnalités** :
  - Détection de l'état de l'interrupteur mécanique `SW1` sur `D2` (3V3_S).
  - Détection de la présence du câble USB 5V sur `D10` (`CHARGE_PIN`).
  - Mesure instantanée de la tension batterie sur `D1`.
  - **Test du Deep Sleep** : Lorsque l'interrupteur est basculé sur OFF (et hors USB), le microcontrôleur coupe les LEDs, ferme le bus I2C, isole les GPIOs et passe en veille profonde.
  - **Réveil instantané** dès que l'interrupteur est rebasculé sur ON.
* **Objectif** : Vérifier au multimètre que la consommation en veille est inférieure à $20\,\mu\text{A}$.

---

### 6. `TEST_ALL_INTERACTIVE` — Tableau de Bord Interactif
* **Commandes Série (115200 bauds)** :
  - `r` / `g` / `b` : Allume les LEDs en Rouge / Vert / Bleu
  - `w` : Allume les LEDs en Blanc 100%
  - `o` : Éteint les LEDs
  - `t` : Déclenche une mesure ToF
  - `p` : Envoie un paquet Ping ESP-NOW
  - `?` : Affiche le menu d'aide

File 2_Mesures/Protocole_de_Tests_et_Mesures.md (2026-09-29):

# Protocole de Tests et Relevé de Mesures — Light Trainer V3

Ce document sert de cahier d'expérimentation pour consigner les résultats mesurés sur les prototypes Veroboard / PCB V3.

---

## 📊 1. Test d'Autonomie et Décharge Batterie

* **Batterie testée** : LiPo 3.7V (Capacité : _______ mAh)
* **Mode de test** : `TEST_BATTERY_STRESS` ou `TEST_BATTERY_GAME_SIM`

| Temps (h:min) | Tension $V_{\text{batt}}$ (V) | Pourcentage (%) | Consommation mesurée (mA) | Remarques / Comportement |
| :--- | :--- | :--- | :--- | :--- |
| **00:00** | 4.20 V | 100 % | | Début du test |
| **00:30** | | | | |
| **01:00** | | | | |
| **01:30** | | | | |
| **02:00** | | | | |
| **03:00** | | | | |
| **04:00** | | | | |
| **Fin (Coupure)**| 3.00 V | 0 % | | Durée totale : _____ h _____ min |

---

## 📡 2. Test de Portée Radio & Latence ESP-NOW

* **Mode de test** : `TEST_RADIO_PING_RTT_RSSI` (Canal 1, Broadcast, 10 pings/sec)
* **Conditions météo / environnement** : ___________________________

| Distance (m) | Obstacles (Vue directe / Murs) | RSSI moyen (dBm) | Latence RTT (ms) | Perte de paquets (%) | Statut LED |
| :--- | :--- | :--- | :--- | :--- | :--- |
| **1 m** | Vue directe (Bench) | | | | 🟢 Vert |
| **5 m** | Vue directe | | | | |
| **10 m** | Vue directe | | | | |
| **20 m** | Vue directe (Extérieur) | | | | |
| **30 m** | Vue directe (Extérieur) | | | | |
| **50 m** | Vue directe (Extérieur) | | | | |
| **Portée Max** | Décrochage complet | | | | 🔴 Rouge |
| **Intérieur** | 1 Mur béton / brique | | | | |
| **Intérieur** | 2 Murs | | | | |

---

## 🎯 3. Qualification Capteur ToF (VL53L0X) & Tenue au Soleil

* **Mode de test** : `TEST_TOF_BENCHMARK`

| Environnement | Éclairement (Lux / Météo) | Distance max détectée (mm) | Faux Hits / min | Taux d'erreurs optiques (%) | Réactivité / Remarques |
| :--- | :--- | :--- | :--- | :--- | :--- |
| **Intérieur sombre** | < 100 lux | | 0 | | Réactivité maximale |
| **Intérieur éclairé**| ~500 lux (Néons/LEDs) | | 0 | | |
| **Extérieur à l'ombre**| ~5 000 lux | | | | |
| **Plein Soleil direct**| > 50 000 lux | | | | Vérifier saturation IR |

---

## ⚡ 4. Consommation Électrique & Veille Profonde (Deep Sleep)

* **Appareil de mesure** : Multimètre en série avec la batterie (calibre $\mu\text{A}$ / $\text{mA}$)

| État du Pod | Tension $V_{\text{batt}}$ (V) | Courant mesuré | Autonomie théorique calculée |
| :--- | :--- | :--- | :--- |
| **Deep Sleep (Switch OFF)** | 3.7 V | **_____ $\mu\text{A}$** | > 1 an |
| **Veille Inactivité (Timeout)** | 3.7 V | **_____ $\mu\text{A}$** | > 1 an |
| **Menu / Écoute passive** | 3.7 V | _____ mA | |
| **Cible active (LEDs 50%)** | 3.7 V | _____ mA | |
| **Stress Test (LEDs 100% Blanc + RF)** | 3.7 V | _____ mA | |
| **Recharge USB en cours** | 5.0 V (USB) | _____ mA | Temps de charge : _____ min |

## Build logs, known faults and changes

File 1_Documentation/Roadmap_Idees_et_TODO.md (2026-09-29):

# Feuille de Route, Idées d'Évolution & TODO — Light Trainer

Ce document consigne les axes d'amélioration logicielle, les évolutions architecturales et le plan d'action (TODO) pour faire évoluer le projet **Light Trainer** d'un stade de prototype fonctionnel vers un **produit fini, robuste, déployable et industrialisable**.

---

## 🧭 Synthèse des Piliers Stratégiques

```mermaid
mindmap
  root((Light Trainer<br/>Roadmap Production))
    1. Réseau & Flotte
      Master SoftAP Exclusif
      Élection Dynamique du Master
      Heartbeat & Synchro Microseconde
      Veille Synchronisée Mesh
    2. Web & Interface Coach
      WebSockets ou SSE
      Compression Gzip / Assets
      PWA Installable Hors-ligne
      Créateur d'Entraînements & Drills
    3. Optique & ToF
      Auto-calibration Lumière Ambiante
      Détection par Dérivée d(dist)/dt
      Sauvegarde des Profils en NVS
    4. Déploiement & OTA
      Mise à jour Web OTA Multi-Pods
      Gestion des Noms & Identifiants
      Logs Crash Persistants (LittleFS)
    5. Ergonomie & Hardware
      Feedback Audio (Buzzer PWM)
      Jauges & Animations LED Étendues
    6. Toolchain & Qualité
      Migration PlatformIO
      Intégration Continue (CI)
```

---

## 1. Architecture Réseau & Flotte

### 1.1. SoftAP Exclusif au Master (Suppression des Conflits RF)
* **Constat actuel** : Tous les pods démarrent actuellement un point d'accès SoftAP (`LightTrainer` ou `LightTrainer_Config`) sur le canal 1. Lorsque 6 pods sont allumés à proximité, 6 points d'accès diffusent des balises 802.11 balayant le spectre radio et augmentant les collisions de paquets ESP-NOW.
* **Solution cible** :
  - Tous les pods démarrent en mode **`WIFI_STA` pur**.
  - Seul le pod qui prend le rôle de **Master** (démarré via appui long 1.5s ou sélection Web initiale) active son interface SoftAP (`WIFI_AP_STA`).
  - Si le Master s'éteint ou est mis en veille, un autre pod peut reprendre l'AP automatiquement.
* **Bénéfice** : Réduction drastique de la congestion RF 2.4 GHz, gain d'autonomie pour les pods esclaves (pas de balises AP à émettre).

### 1.2. Élection Dynamique du Master & Tolérance aux Pannes
* **Constat actuel** : Le Master est déterminé par le premier pod sur lequel l'utilisateur déclenche un démarrage de jeu ou connecte son smartphone.
* **Solution cible** :
  - Implémenter un protocole d'élection de leader inspiré de Raft/Bully pour les réseaux ad-hoc : le pod avec l'ID MAC le plus bas ou le niveau de batterie le plus élevé assure la coordination si le Master actif tombe en panne.
  - Sauvegarde de l'état de jeu courant dans les trames de heartbeat pour reprise transparente.

### 1.3. Synchronisation Temporelle & Mesure Précise de la Latence ($\mu\text{s}$)
* **Constat actuel** : Le temps de réaction est calculé entre l'activation ordonnée par le Master et la réception du message `CMD_HIT`. Cela inclut la latence aller-retour radio (~2 à 5 ms).
* **Solution cible** :
  - Intégrer un horodatage absolu dans chaque pod synchronisé par trames périodiques ESP-NOW (synchronisation d'horloge type SNTP local / PTP léger).
  - L'esclave horodate la détection physique ToF à la microseconde près et transmet `reactionTimeMs` directement dans le paquet `CMD_HIT`.

---

## 2. Interface Web Coach & Expérience Applicative

### 2.1. Migration HTTP Polling $\rightarrow$ WebSockets ou Server-Sent Events (SSE)
* **Constat actuel** : Le dashboard interroge l'ESP32 toutes les 250 ms (`pollStatus`) et 2000 ms (`pollPods`) via des requêtes HTTP `GET` répétées. Bien que fonctionnel grâce à `send_P`, cela génère un trafic TCP/HTTP constant et sollicite inutilement la stack réseau.
* **Solution cible** :
  - Passer sur une connexion persistante **WebSocket** ou **SSE** (Server-Sent Events).
  - Le Master pousse un événement JSON uniquement lors d'un changement d'état : nouvelle touche, chronomètre, détection batterie ou changement de statut pod.
* **Bénéfice** : Réactivité instantanée (< 5 ms affichage Web), consommation CPU et RF réduite sur l'ESP32.

### 2.2. Compression GZIP & Pipeline d'Assets
* **Constat actuel** : Le code HTML/CSS/JS est stocké en clair sous forme de chaîne `PROGMEM` (~75 Ko).
* **Solution cible** :
  - Pré-compiler et compresser les assets Web en **GZIP** (`index.html.gz` ~20 Ko).
  - Utiliser `server.sendHeader("Content-Encoding", "gzip")` et `server.send_P(200, "text/html", DASHBOARD_GZ, sizeof(DASHBOARD_GZ))`.
* **Bénéfice** : Division par 3.5 du temps de chargement initial de la page sur mobile et économie de 50 Ko de mémoire Flash.

### 2.3. Transformation en Progressive Web App (PWA)
* **Constat actuel** : L'utilisateur ouvre la page via le navigateur ou le portail captif.
* **Solution cible** :
  - Ajouter un `manifest.json` et un Service Worker minimal.
  - Permettre l'installation en "Application native" sur l'écran d'accueil iOS/Android avec icône personnalisée, fonctionnement en plein écran sans barre d'adresse et cache hors-ligne.
* **Est - ce fonctionelle ?**

### 2.4. Créateur d'Entraînements Personnalisés (Drill Builder)
* **Idée** : Permettre au coach de programmer des séquences d'entraînement personnalisées :
  - Exemple : Pod 1 (Rouge) $\rightarrow$ Pod 3 (Bleu) $\rightarrow$ Pause 2s $\rightarrow$ Pod 2 (Vert).
  - Enregistrement des séquences favorites dans la mémoire NVS de l'ESP32 ou dans le `localStorage` du navigateur.

---

## 3. Capteur ToF & Traitement du Signal Optique

### 3.1. Auto-Calibration Dynamique de la Lumière Ambiante
* **Constat actuel** : Le seuil de déclenchement est fixé statiquement à $150\text{ mm}$. En plein soleil ou sous des néons fluorescents pulsés à 100 Hz, le VL53L0X peut renvoyer des valeurs erratiques (code d'erreur 8190 ou distances instables).
* **Solution cible** :
  - À l'allumage, réaliser une séquence d'étalonnage de 1 seconde pour mesurer le bruit de fond ambiant et la distance au plafond / obstacles fixes.
  - Ajuster automatiquement la fenêtre de validité et le seuil de détection.

### 3.2. Détection par Dérivée Temporelle ($d(\text{dist})/dt$)
* **Constat actuel** : Détection sur condition statique `distance <= TOF_TRIGGER_DISTANCE`.
* **Solution cible** :
  - Calculer la vitesse d'approche de la main : si $\frac{\Delta \text{distance}}{\Delta t} < -V_{\text{seuil}}$, la main est en mouvement rapide d'attaque vers le pod.
  - Rejeter les fausses détections dues aux passages lointains ou ombres lentes.

### 3.3. Sauvegarde des Profils de Calibration en Flash NVS
* Sauvegarder un offset optique propre à chaque boîtier (lié à la vitre de protection en polycarbonate/acrylique et aux tolérances mécaniques) directement en mémoire non-volatile via l'API `Preferences` d'ESP32.

---

## 4. Déploiement, Maintenance & Production Industrielle

### 4.1. Mises à Jour Over-The-Air (Web OTA Multi-Pods)
* **Constat actuel** : Chaque mise à jour du firmware nécessite de brancher physiquement chaque pod en USB-C sur le PC et d'utiliser l'IDE Arduino.
* **Solution cible** :
  - Intégrer un endpoint `/update` sur le serveur Web (bibliothèque `Update.h` d'ESP32).
  - Permettre au coach de téléverser un fichier `.bin` depuis son smartphone pour mettre à jour le Master.
  - Option avancée : Propager le nouveau binaire aux pods esclaves via des blocs ESP-NOW (Mesh OTA distribué).

### 4.2. Identification & Nommage Personnalisé des Pods
* Permettre au coach de renommer chaque pod depuis l'interface Web (ex. : *"Pod Poteau Gauche"*, *"Pod Ligne Centrale"*).
* Sauvegarder ce nom personnalisé en Flash NVS sur le pod correspondant.

### 4.3. Journal d'Erreurs Persistant (Crash Dumper)
* Stocker les 20 derniers crashs système ou redémarrages inattendus (cause de reset ESP32, trace mémoire, exception) dans la partition SPIFFS/LittleFS pour faciliter le diagnostic SAV à distance.

---

## 5. Ergonomie & Retour Sensoriel

### 5.1. Intégration du Buzzer Piézoélectrique (Sortie D3 / GPIO5)
* Le schéma matériel V3 prévoit la broche `D3` (TP2) pour un buzzer passif ou magnétique.
* **Évolutions logicielles** :
  - Bips courts de compte à rebours au départ ($3, 2, 1, \text{GO}$).
  - Tonalité aiguë ($2.5\text{ kHz}, 30\text{ ms}$) pour valider une frappe réussie.
  - Tonalité grave ($400\text{ Hz}, 200\text{ ms}$) en cas de fausse couleur ou d'erreur sur le jeu Simon.
  - Option silencieuse configurable depuis le Dashboard Web pour les entraînements en salle fermée.

---

## 6. Chaîne de Compilation & Qualité Logicielle

### 6.1. Migration vers PlatformIO
* **Bénéfices** :
  - Fichier `platformio.ini` standardisant le partitionnement (`huge_app.csv`), la vitesse d'horloge, les flags de compilation (`-O2`, `-DDEBUG`) et les versions strictes des bibliothèques (`FastLED`, `Adafruit_VL53L0X`).
  - Suppression des erreurs de partitionnement manuelles dans l'IDE Arduino.
  - Téléversement et monitoring série en une seule commande en ligne de commande.

### 6.2. Intégration Continue (GitHub Actions)
* Compiler automatiquement le code à chaque push/pull-request pour garantir l'absence de régression de compilation ou de dépassement de mémoire Flash/RAM.

---

## 📋 Tableau de Suivi des Tâches (TODO Backlog)

### 🔴 Priorité P0 — Indispensable pour la Fiabilité en Production
- [x] **Réseau** : Désactiver le point d'accès SoftAP sur tous les pods esclaves (`WIFI_STA` pur) ; n'activer le SoftAP que sur le Master.
- [ ] **Compilation** : Fournir un fichier de partitionnement personnalisé ou formaliser la configuration IDE Arduino `Partition Scheme -> Huge APP (3MB)` dans tous les guides.
- [x] **Réseau** : Gérer la ré-élection du Master si le Master actuel s'éteint ou est mis en veille pendant une session.
- [ ] **Robustesse Web** : Mettre en cache les requêtes DNS sur le portail captif pour limiter les interruptions sur Android / iOS récents.

### 🟡 Priorité P1 — Confort, Performance & UX Avancée
- [x] **Web** : Compresser le payload HTML/CSS/JS en GZIP (`.gz`) dans la mémoire Flash pour réduire le temps de transfert HTTP (15.6 Ko vs 72 Ko).
- [x] **Web** : Remplacer le polling HTTP 250 ms par un Smart Polling adaptatif (100 ms en jeu / 1000 ms en veille, flux déclenché par événements, séparation `/api/config`) pour alléger la boucle `loop()`.
- [ ] **Optique** : Ajouter un algorithme de détection de dérivée de distance pour fiabiliser la détection des frappes rapides.
- [ ] **Énergie** : Implémenter la commande de mise en veille synchronisée de la flotte (`CMD_SLEEP_FLEET`).
- [ ] **Audio** : Implémenter le driver PWM pour le buzzer sur la broche `D3` (départ, hit, erreur Simon).
- [ ] **UX Web** : Ajouter le fichier `manifest.json` pour permettre l'installation PWA sur smartphone.

### 🟢 Priorité P2 — Évolutions Fonctionnelles & Outils
- [ ] **Firmware** : Implémenter la mise à jour Over-The-Air (Web OTA) via l'interface `/update`.
- [ ] **Toolchain** : Ajouter la configuration PlatformIO (`platformio.ini`) à la racine du dossier programmation.
- [ ] **Entraînement** : Créer un éditeur de parcours personnalisés (Drill Builder) dans l'interface Web.
- [ ] **Persistance** : Permettre au coach de nommer les pods individuellement et sauvegarder les noms en NVS.
- [ ] **CI/CD** : Mettre en place un workflow GitHub Actions pour vérifier la compilation automatique du firmware.

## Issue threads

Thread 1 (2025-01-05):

Try to use Adafruit ESP32-S3 Feather

Forestierr, 2025-01-05:
I can use the [Adafruit ESP32-S3 Feather with STEMMA QT / Qwiic - 8MB Flash No PSRAM](https://www.adafruit.com/product/5323)
With a [Lithium Ion Battery - 3.7V 2000mAh](https://www.adafruit.com/product/2011)
For  total of 30 CHF on adafruit.
https://learn.adafruit.com/adafruit-esp32-s3-feather/overview

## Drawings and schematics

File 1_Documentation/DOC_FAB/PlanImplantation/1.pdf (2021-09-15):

Ref lookup | Filter
Light Trainer | Rev:

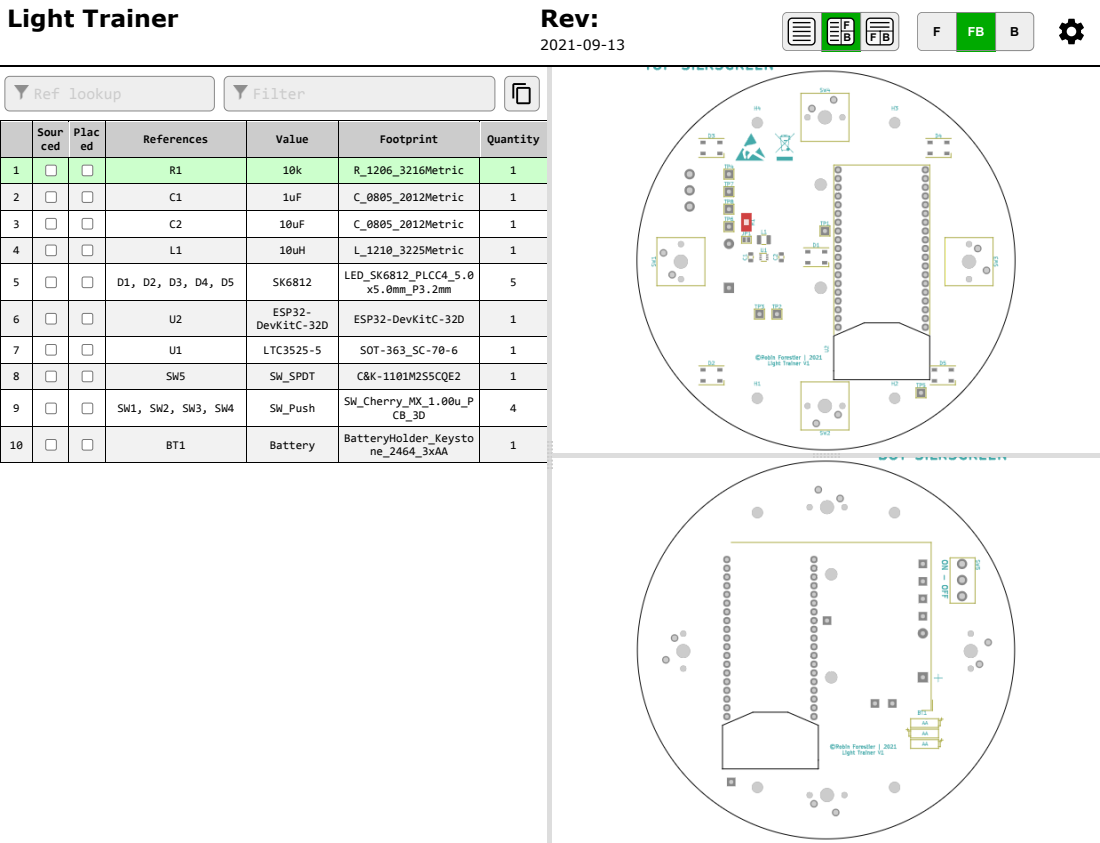
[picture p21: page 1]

Sour ced | Plac ed | References | Value | Footprint | Quantity

1 | | | R1 | 10k | R_1206_3216Metric | 1

2 | | | C1 | 1uF | C_0805_2012Metric | 1

3 | | | C2 | 10uF | C_0805_2012Metric | 1

4 | | | L1 | 10uH | L_1210_3225Metric | 1
5 | | | D1, D2, D3, D4, D5 | SK6812 | LED_SK6812_PLCC4_5.0 x5.0mm_P3.2mm | 5

6 | | | U2 | ESP32-DevKitC-32D | ESP32-DevKitC-32D | 1

7 | | | U1 | LTC3525-5 | SOT-363_SC-70-6 | 1

8 | | | SW5 | SW_SPDT | C&K-1101M2S5CQE2 | 1
9 | | | SW1, SW2, SW3, SW4 | SW_Push | SW_Cherry_MX_1.00u_P CB_3D | 4

10 | | | BT1 | Battery | BatteryHolder_Keysto ne_2464_3xAA | 1

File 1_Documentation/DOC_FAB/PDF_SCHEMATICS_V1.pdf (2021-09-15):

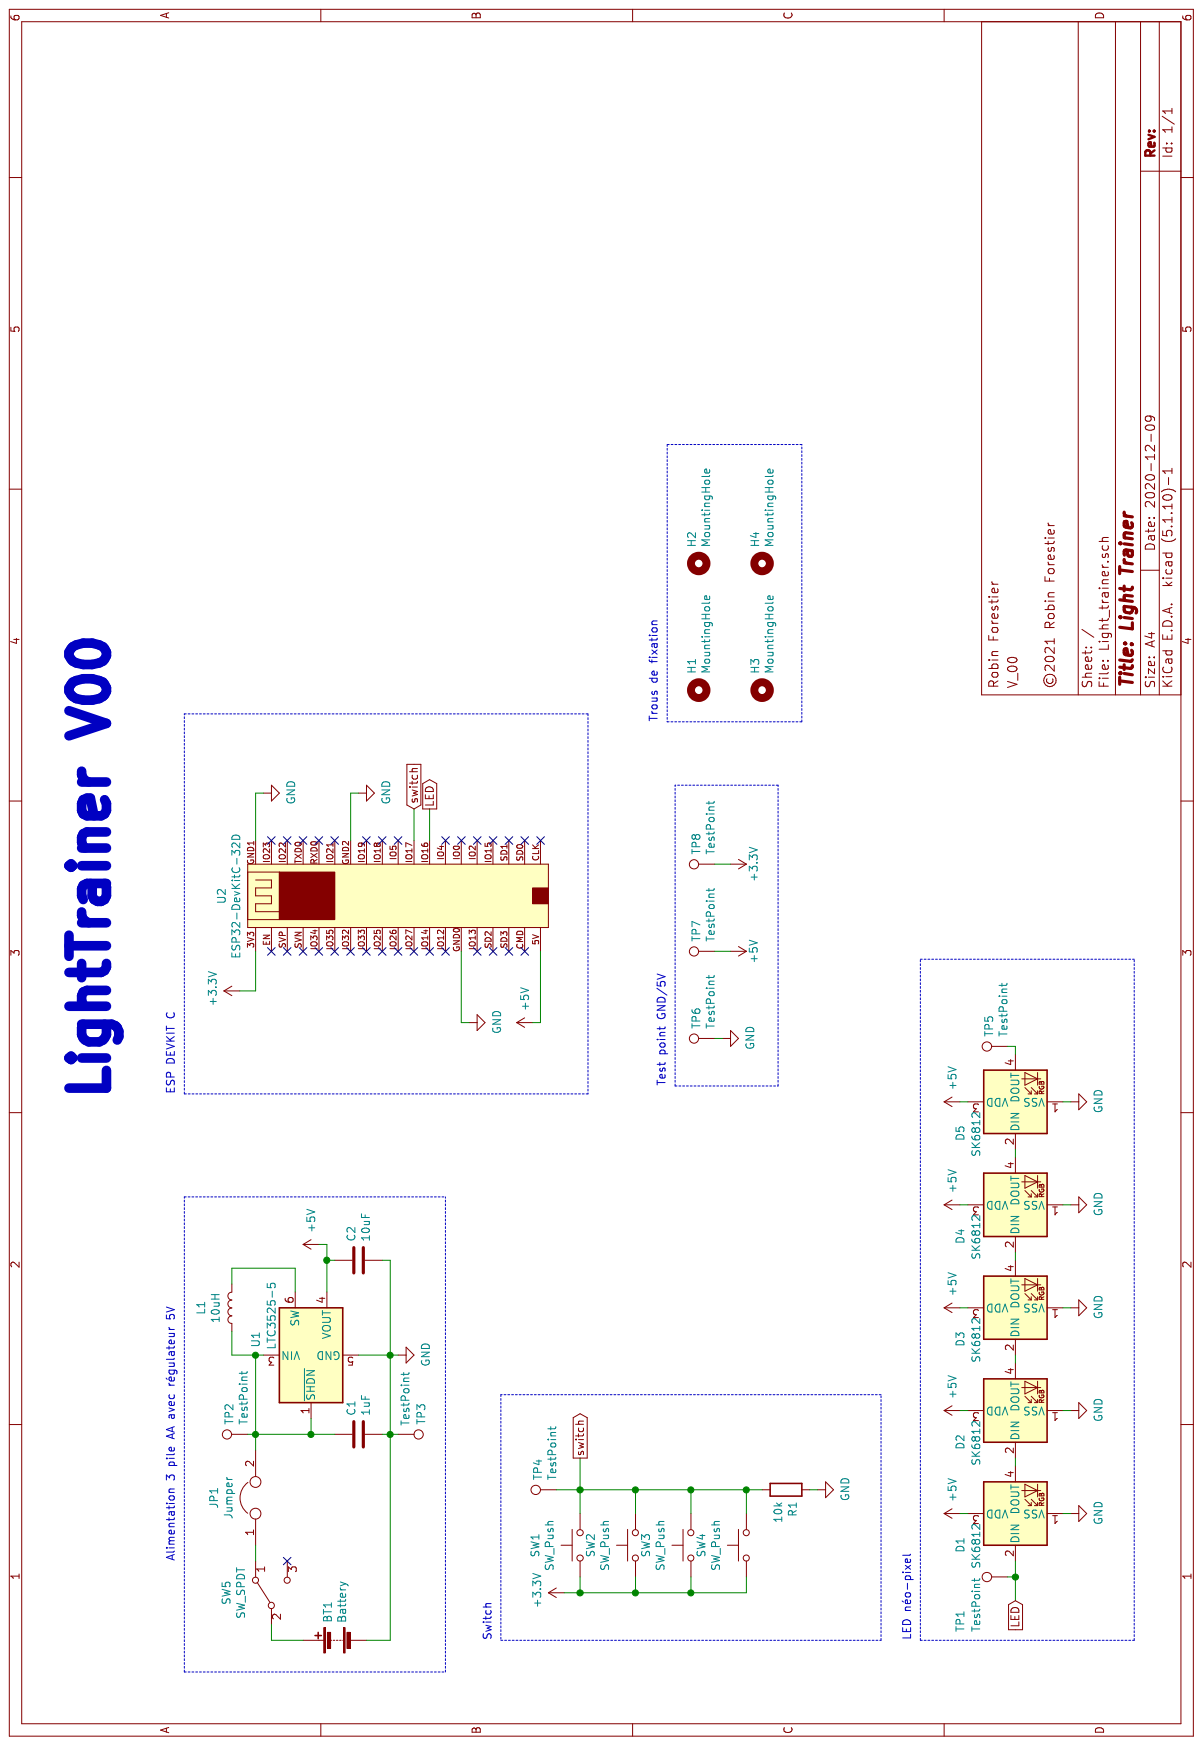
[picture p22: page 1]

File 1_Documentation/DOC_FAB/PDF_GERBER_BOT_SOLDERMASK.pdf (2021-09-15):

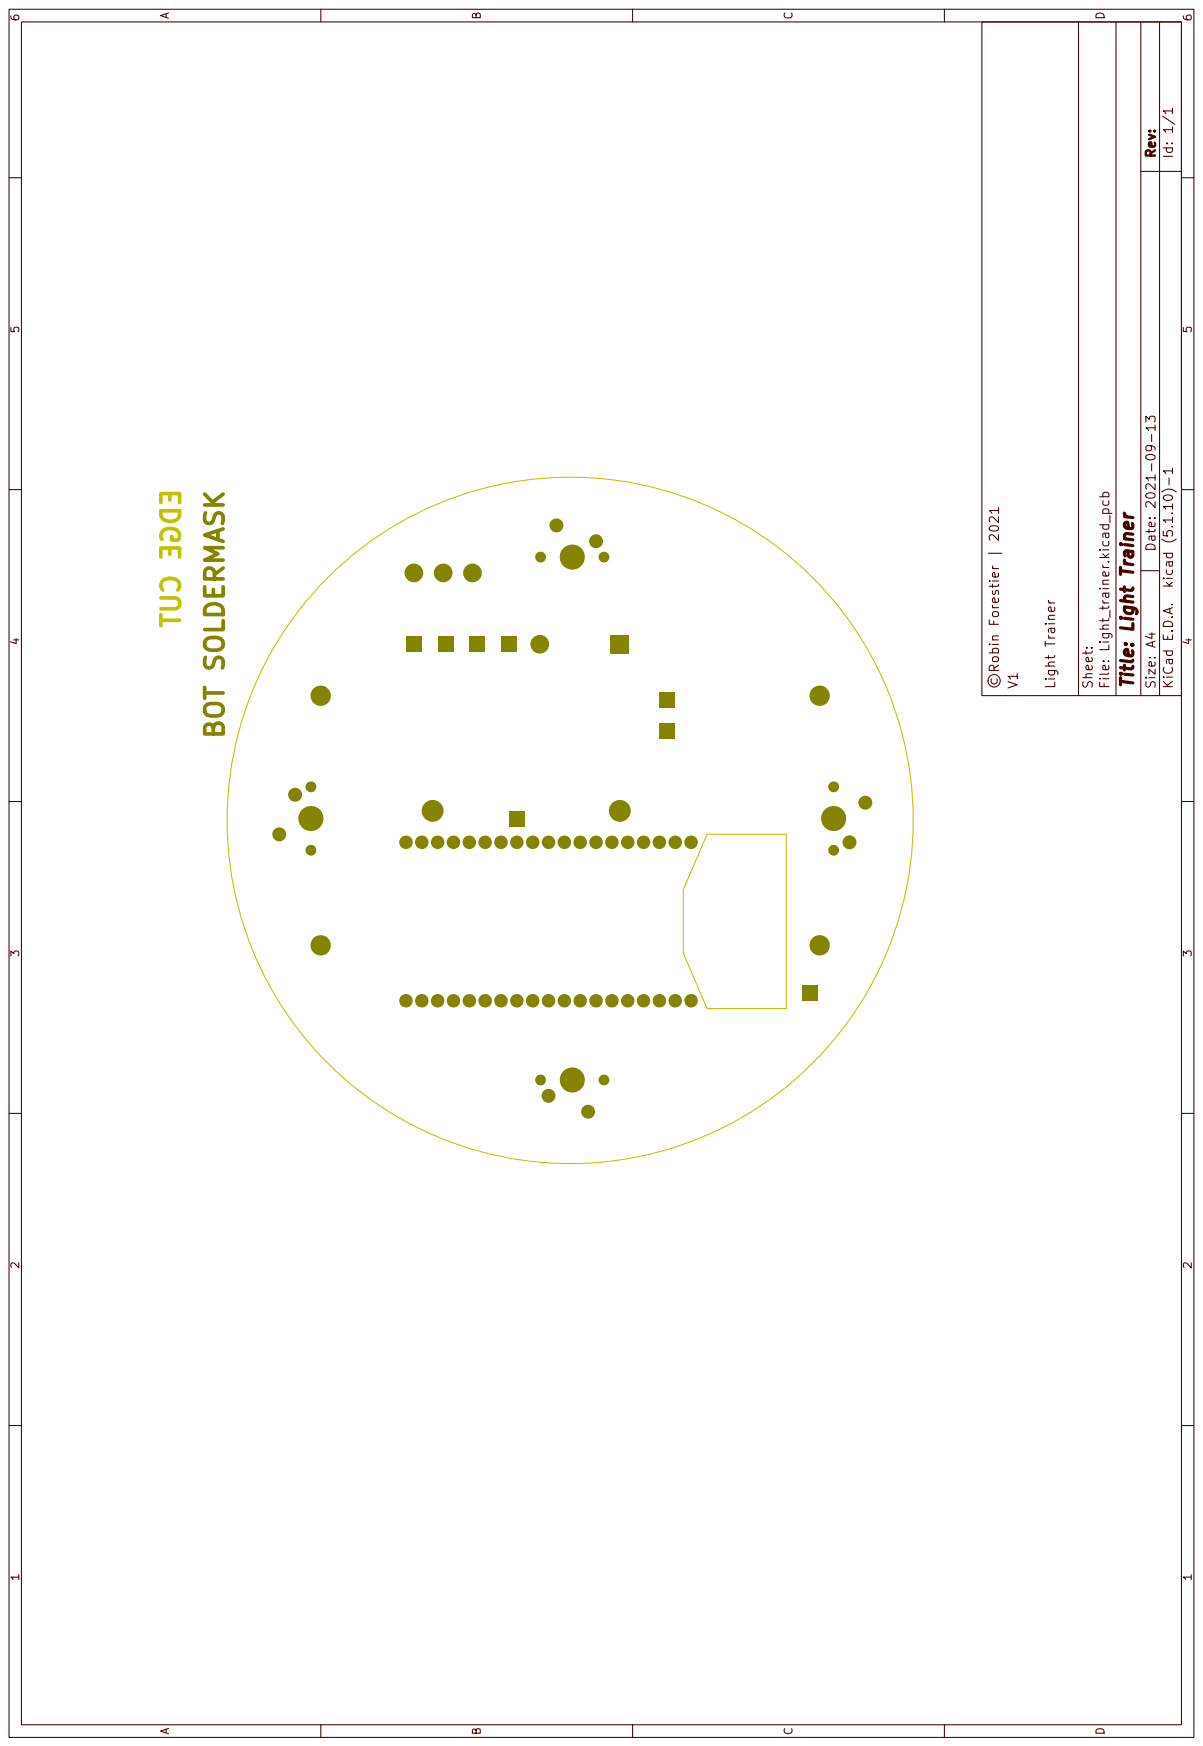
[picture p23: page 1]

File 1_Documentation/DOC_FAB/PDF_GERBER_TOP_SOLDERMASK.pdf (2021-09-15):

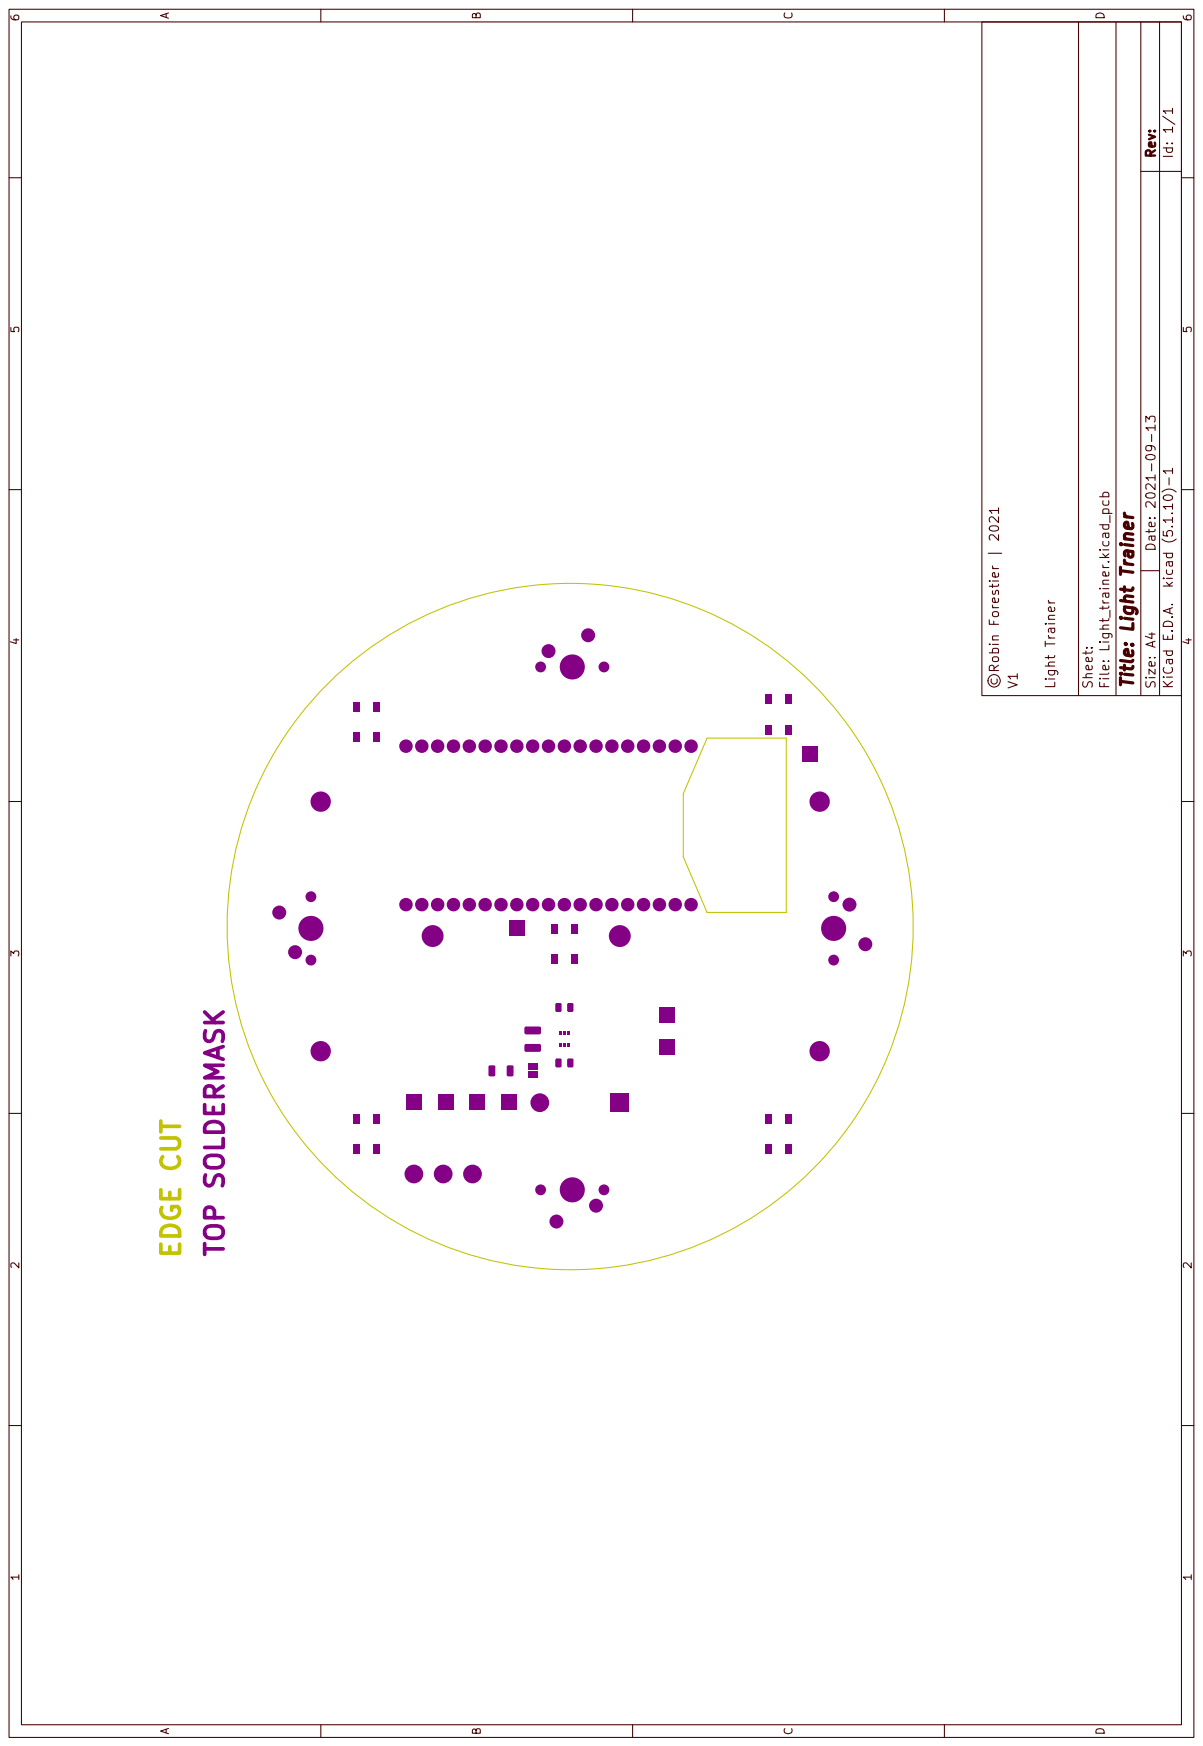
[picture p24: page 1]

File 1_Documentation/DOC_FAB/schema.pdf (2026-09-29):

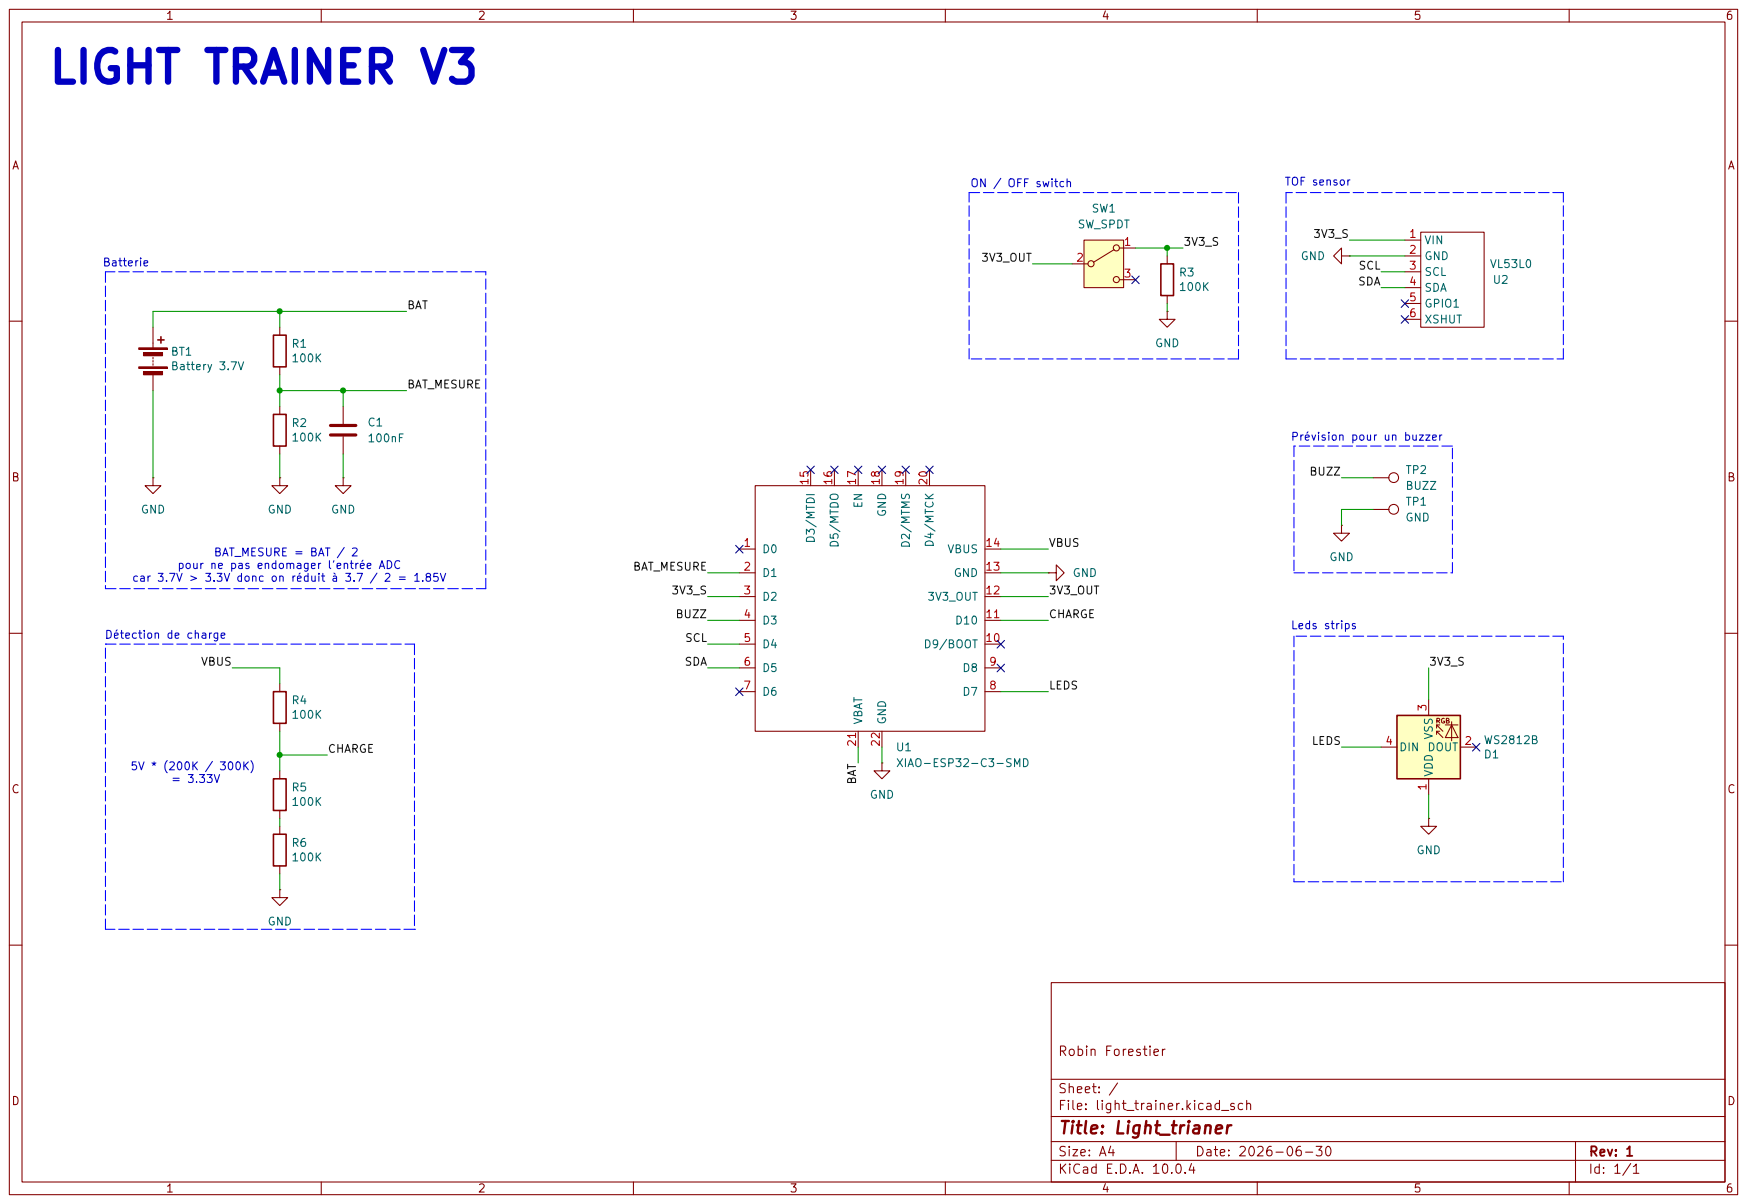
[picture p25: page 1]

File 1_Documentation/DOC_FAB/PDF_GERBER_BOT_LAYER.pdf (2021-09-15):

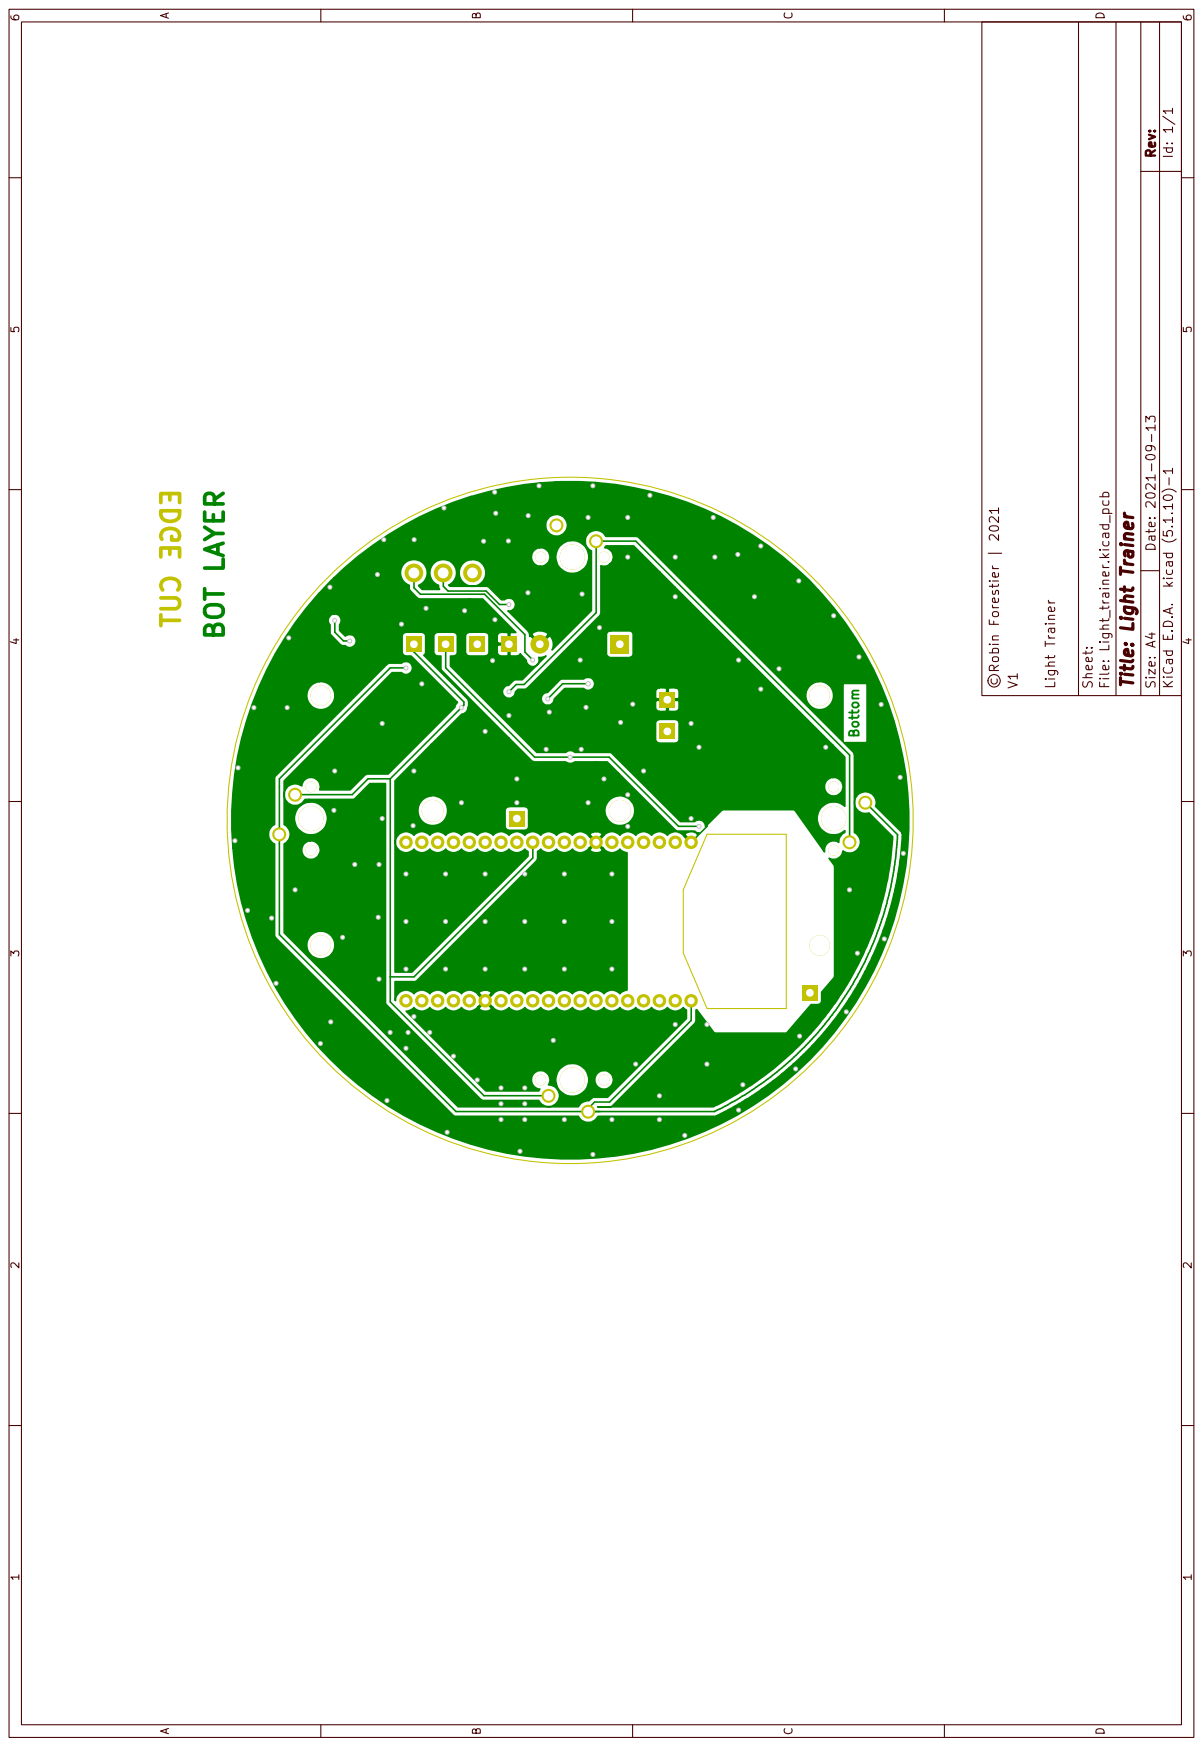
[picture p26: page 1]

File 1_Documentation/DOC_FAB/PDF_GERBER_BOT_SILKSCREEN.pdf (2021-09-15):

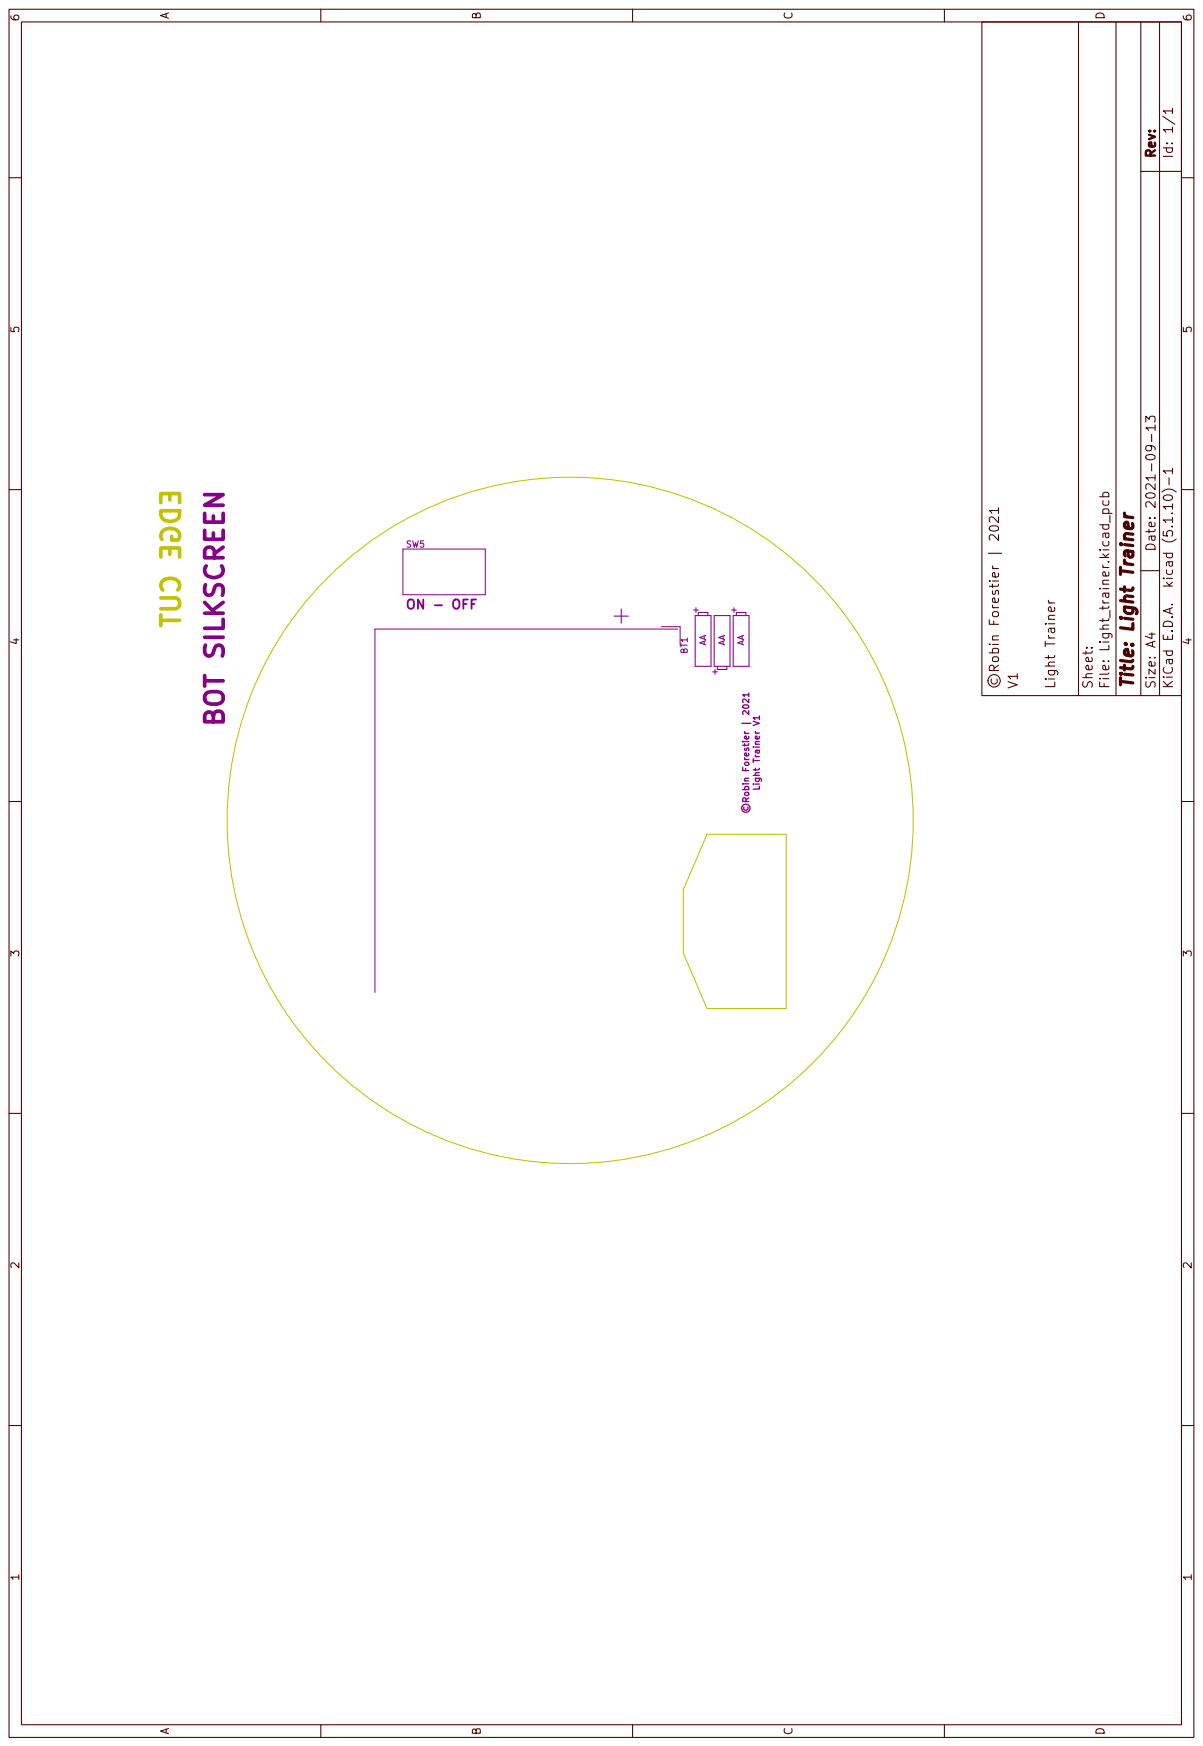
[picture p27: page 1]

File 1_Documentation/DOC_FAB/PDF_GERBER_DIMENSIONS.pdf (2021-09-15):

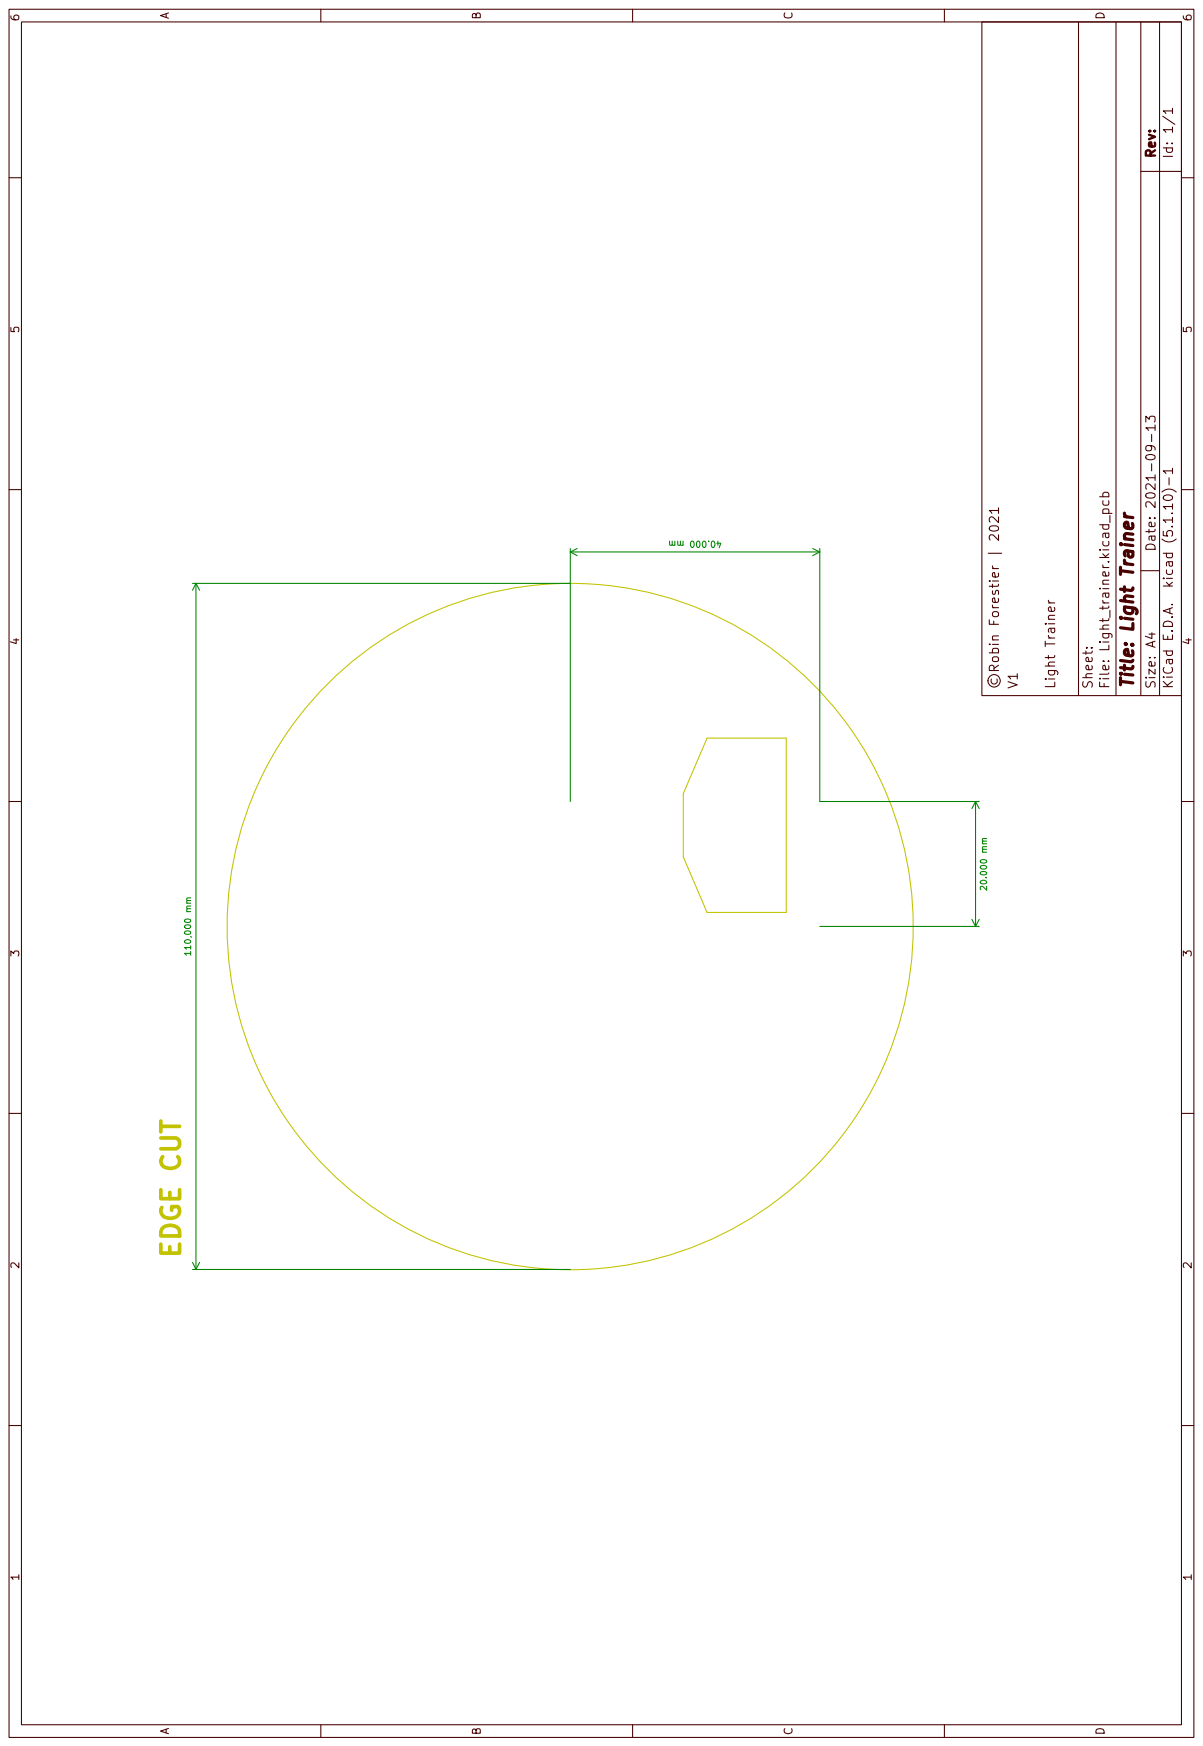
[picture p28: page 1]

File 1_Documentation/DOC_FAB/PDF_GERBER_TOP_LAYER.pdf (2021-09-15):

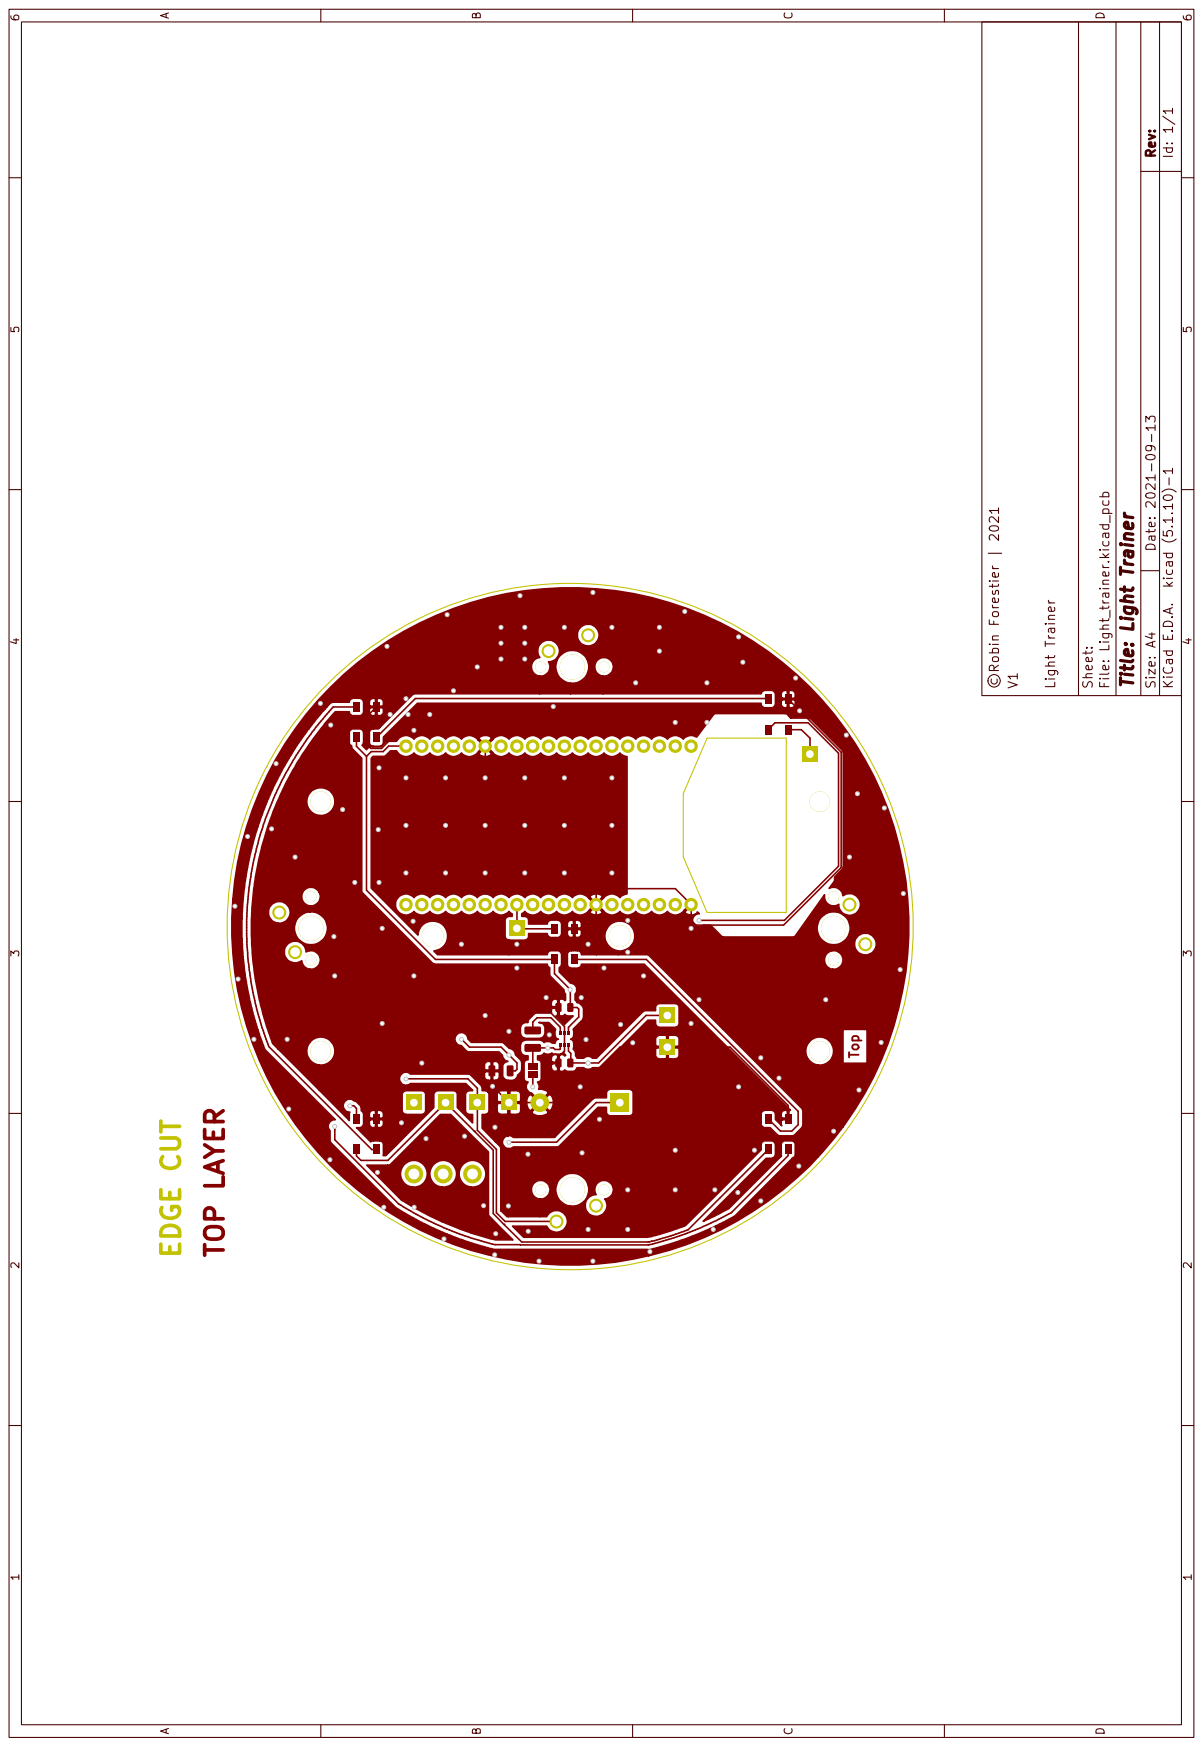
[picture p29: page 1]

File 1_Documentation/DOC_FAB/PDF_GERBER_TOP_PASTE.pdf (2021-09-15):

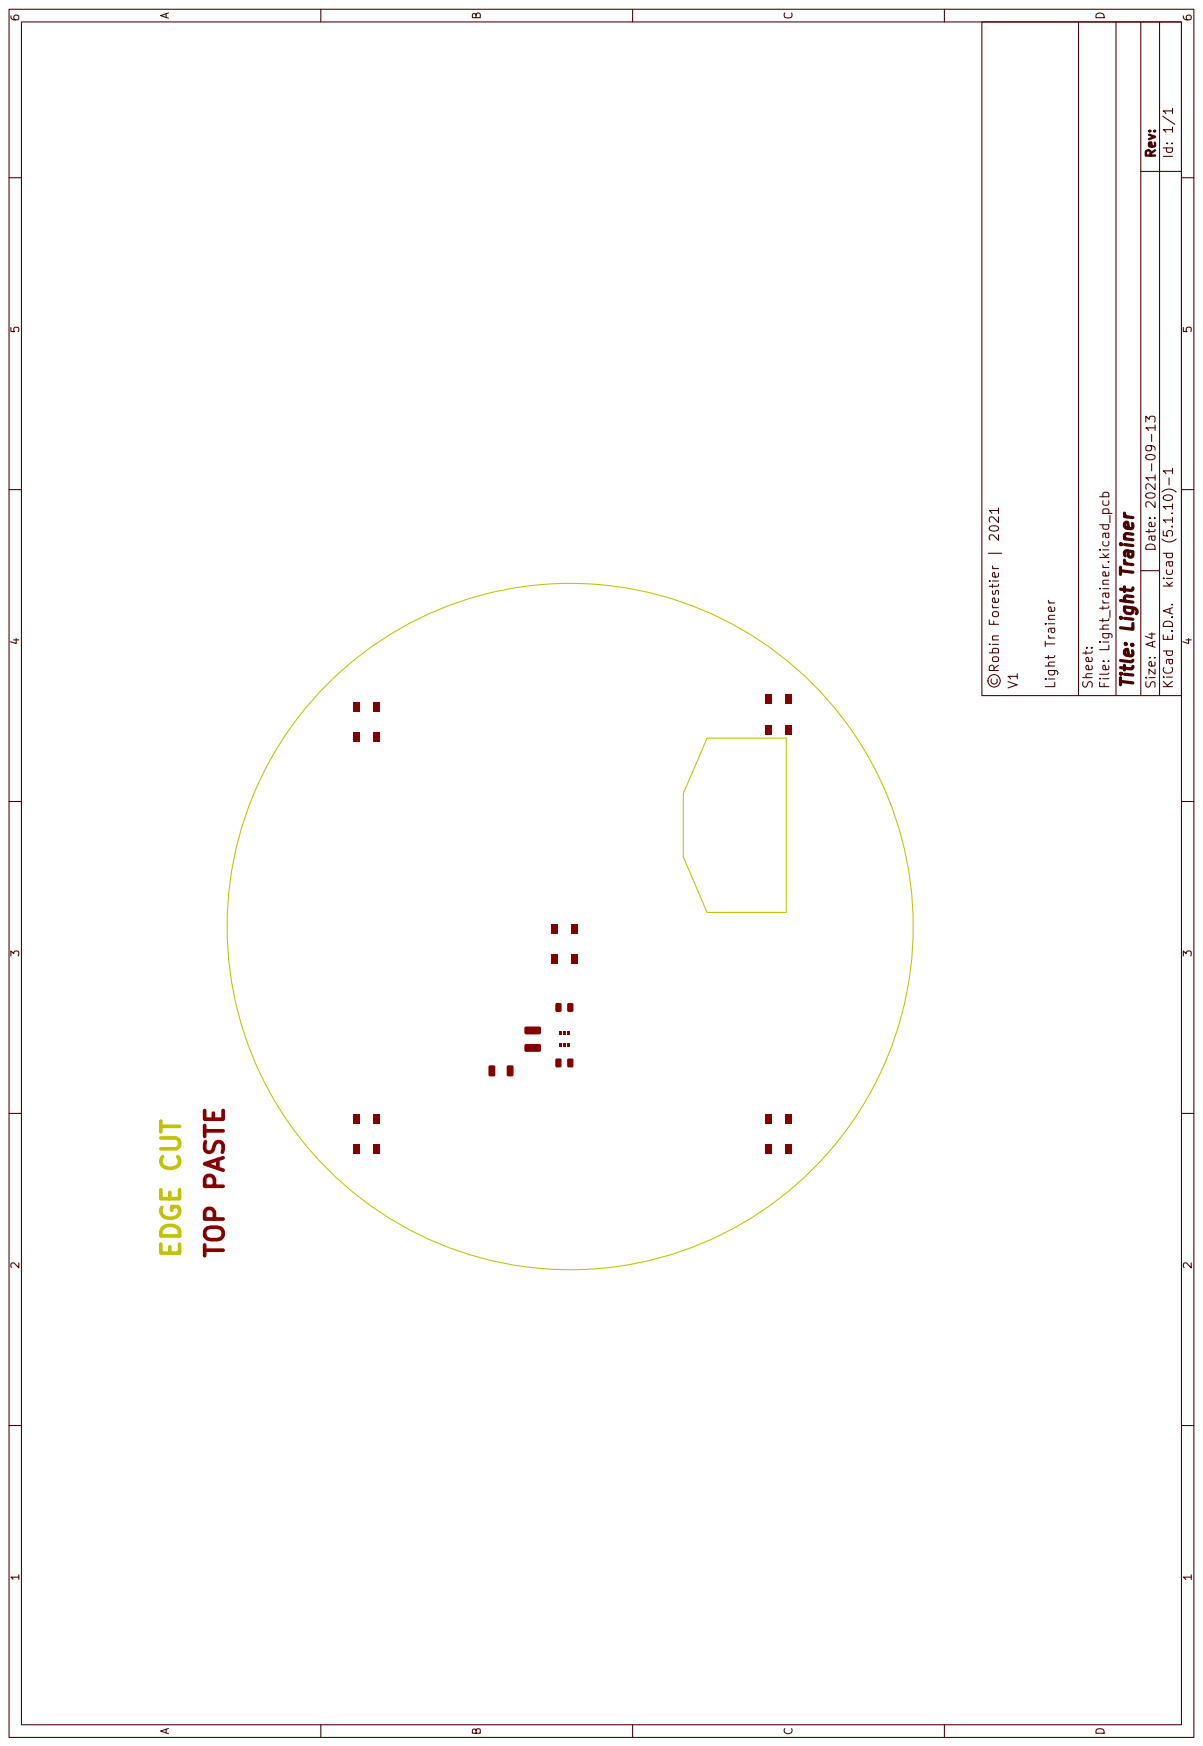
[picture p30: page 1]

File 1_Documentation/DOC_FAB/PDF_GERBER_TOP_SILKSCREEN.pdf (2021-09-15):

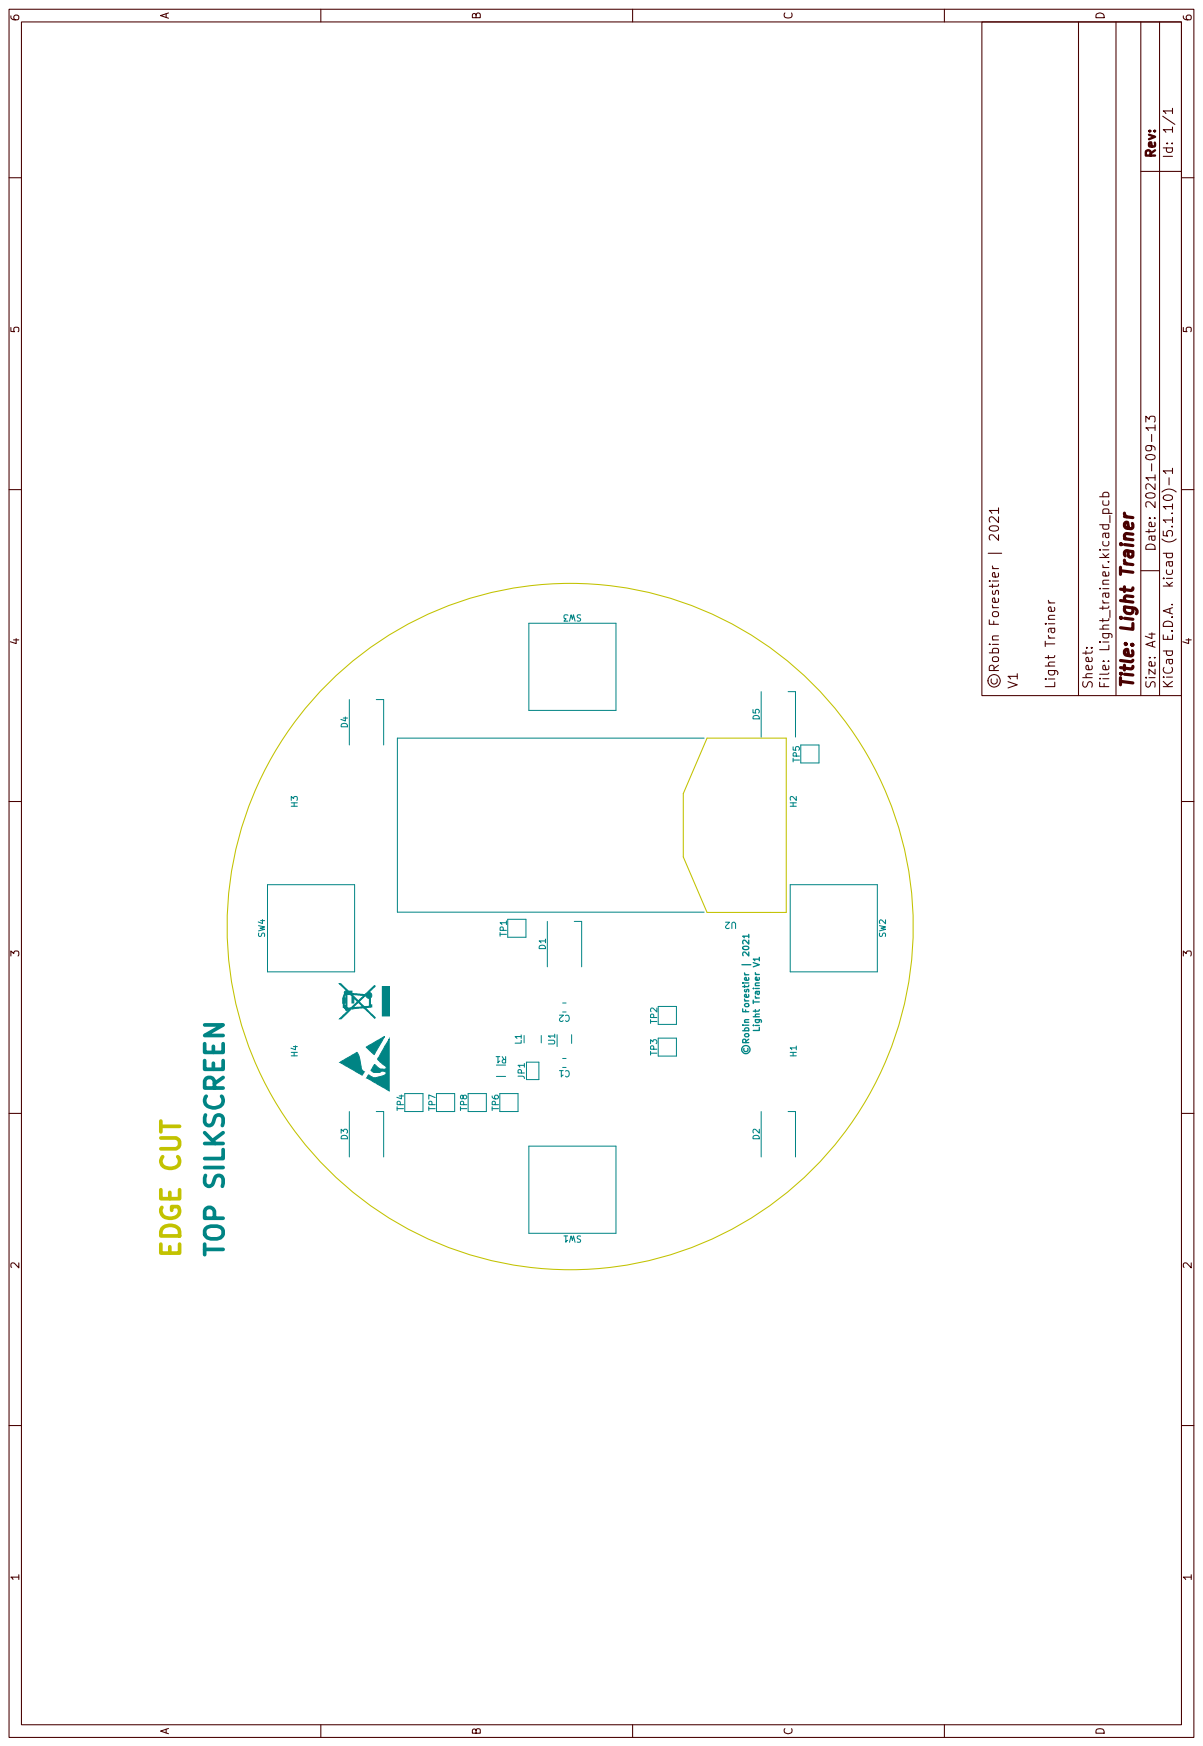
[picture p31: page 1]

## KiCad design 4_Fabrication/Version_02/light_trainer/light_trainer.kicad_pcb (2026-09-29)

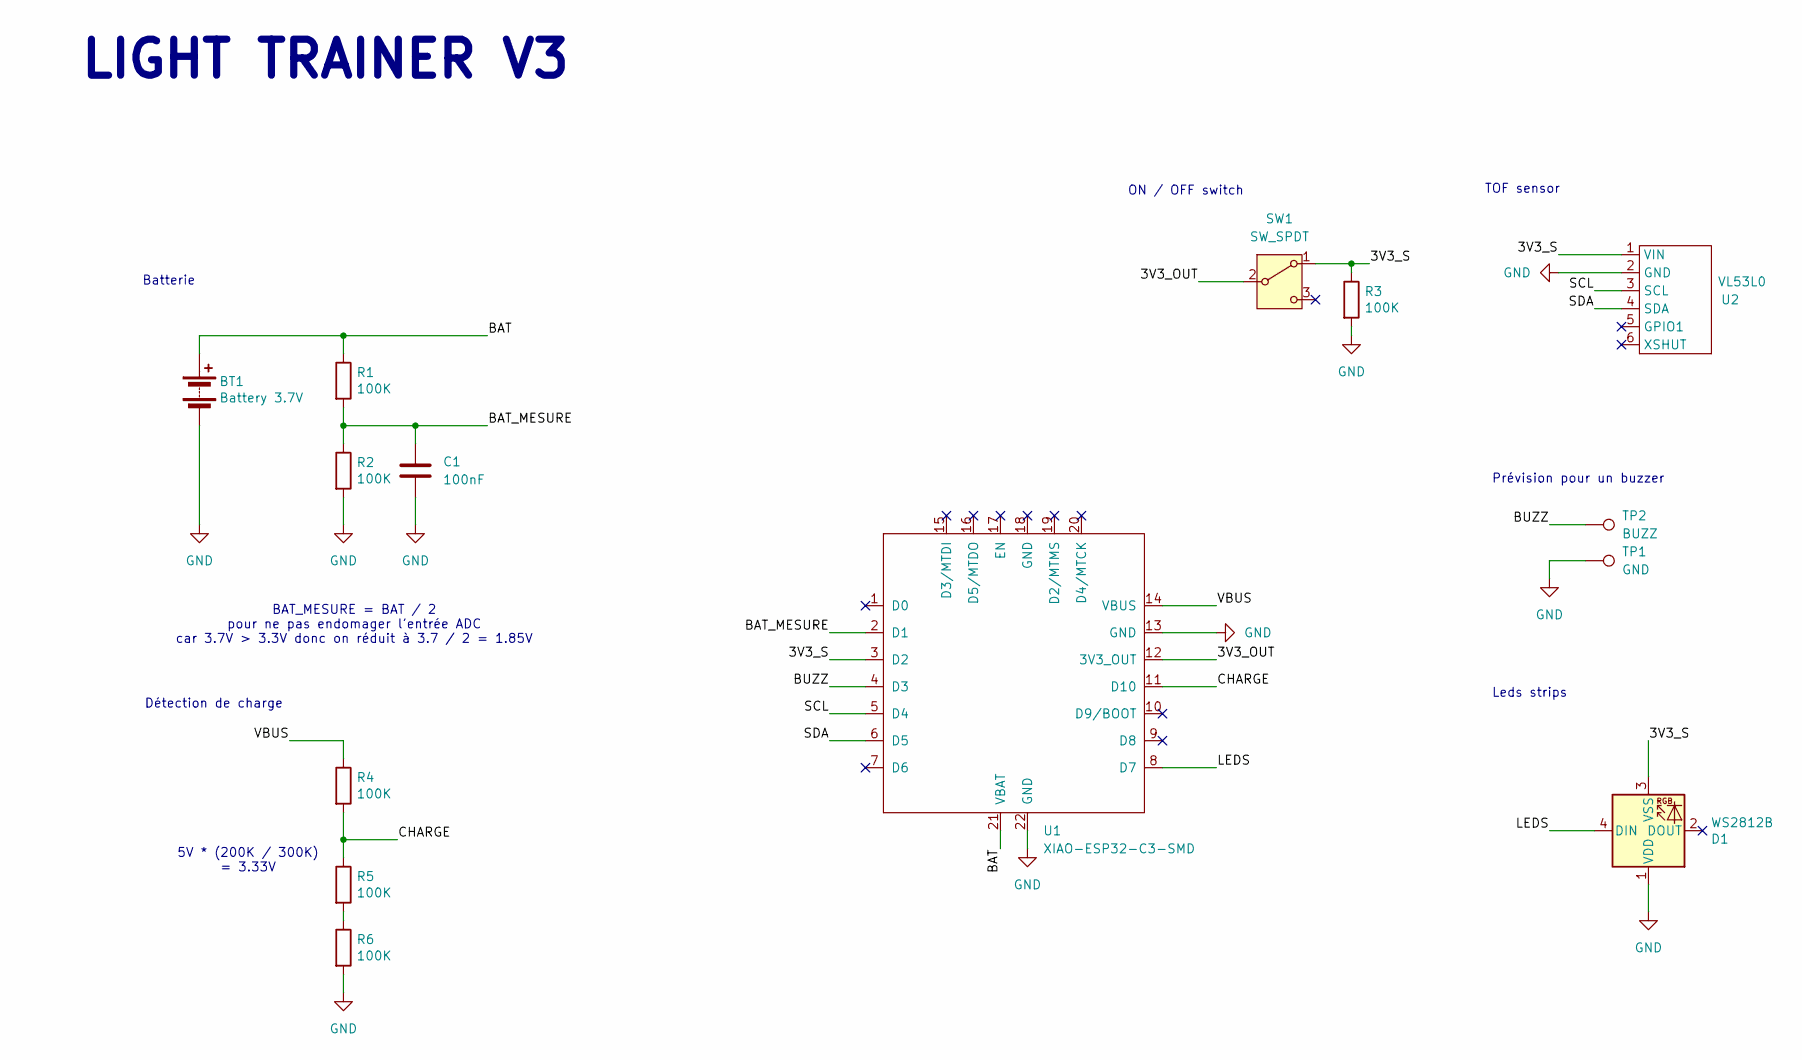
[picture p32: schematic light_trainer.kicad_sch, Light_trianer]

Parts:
BT1: Battery 3.7V; PinHeader_1x02_P2.54mm_Vertical
C1: 100nF; CP_Radial_D5.0mm_P2.50mm
D1: WS2812B; PinHeader_1x04_P2.54mm_Vertical
R1, R2, R3, R4, R5, R6: 100K; R_Axial_DIN0207_L6.3mm_D2.5mm_P7.62mm_Horizontal
SW1: SW_SPDT; PinSocket_1x03_P2.54mm_Vertical
TP1: GND; PinHeader_1x01_P2.54mm_Vertical
TP2: BUZZ; PinHeader_1x01_P2.54mm_Vertical
U1: XIAO-ESP32-C3-SMD; XIAO-ESP32-C3-DIP-SMD
U2: VL53L0

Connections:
/3V3_OUT: SW1.2 (B), U1.12 (3V3_OUT)
/3V3_S: D1.3 (VSS), R3.1, SW1.1 (A), U1.3 (D2), U2.1 (VIN)
/BAT: BT1.1 (+), R1.1, U1.21 (VBAT)
/BAT_MESURE: C1.1, R1.2, R2.1, U1.2 (D1)
/BUZZ: TP2.1 (1_1), U1.4 (D3)
/CHARGE: R4.2, R5.1, U1.11 (D10)
/LEDS: D1.4 (DIN), U1.8 (D7)
/SCL: U1.5 (D4), U2.3 (SCL)
/SDA: U1.6 (D5), U2.4 (SDA)
/VBUS: R4.1, U1.14 (VBUS)
GND: BT1.2 (-), C1.2, D1.1 (VDD), R2.2, R3.2, R6.2, TP1.1 (1_1), U1.13 (GND), U1.22 (GND), U2.2 (GND)
unnamed: R5.2, R6.1

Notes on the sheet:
ON / OFF switch
Détection de charge
Prévision pour un buzzer
5V * (200K / 300K) = 3.33V
LIGHT TRAINER V3
Leds strips
BAT_MESURE = BAT / 2 pour ne pas endomager l'entrée ADC car 3.7V > 3.3V donc on réduit à 3.7 / 2 = 1.85V
Batterie
TOF sensor

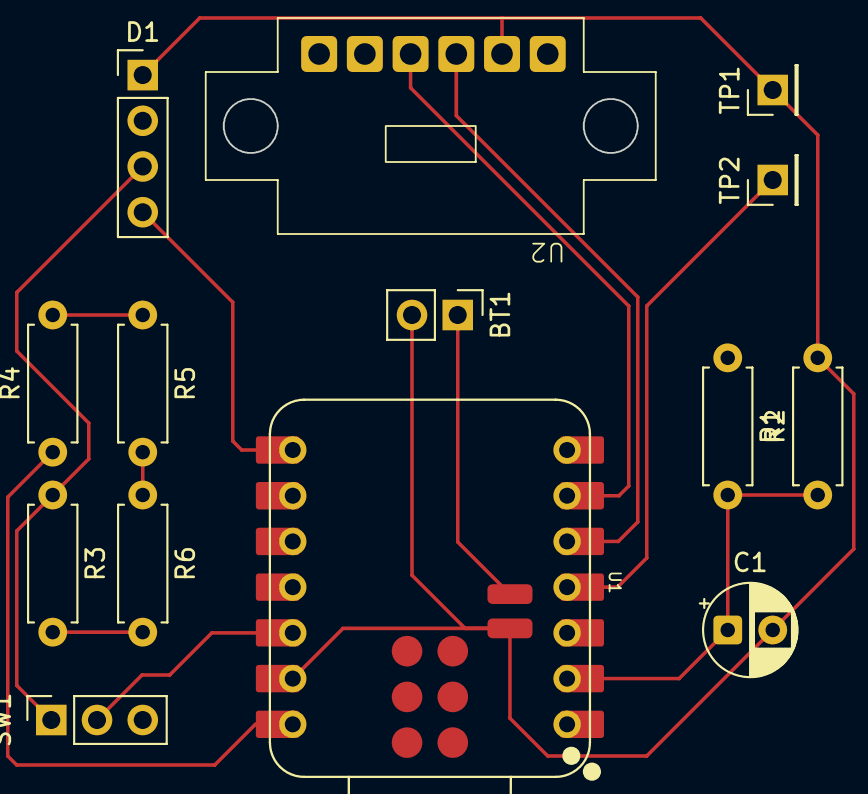
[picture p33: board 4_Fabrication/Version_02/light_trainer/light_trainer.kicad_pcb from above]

Board: 2 copper layers, 14 parts (0 on the bottom side), 12 nets.

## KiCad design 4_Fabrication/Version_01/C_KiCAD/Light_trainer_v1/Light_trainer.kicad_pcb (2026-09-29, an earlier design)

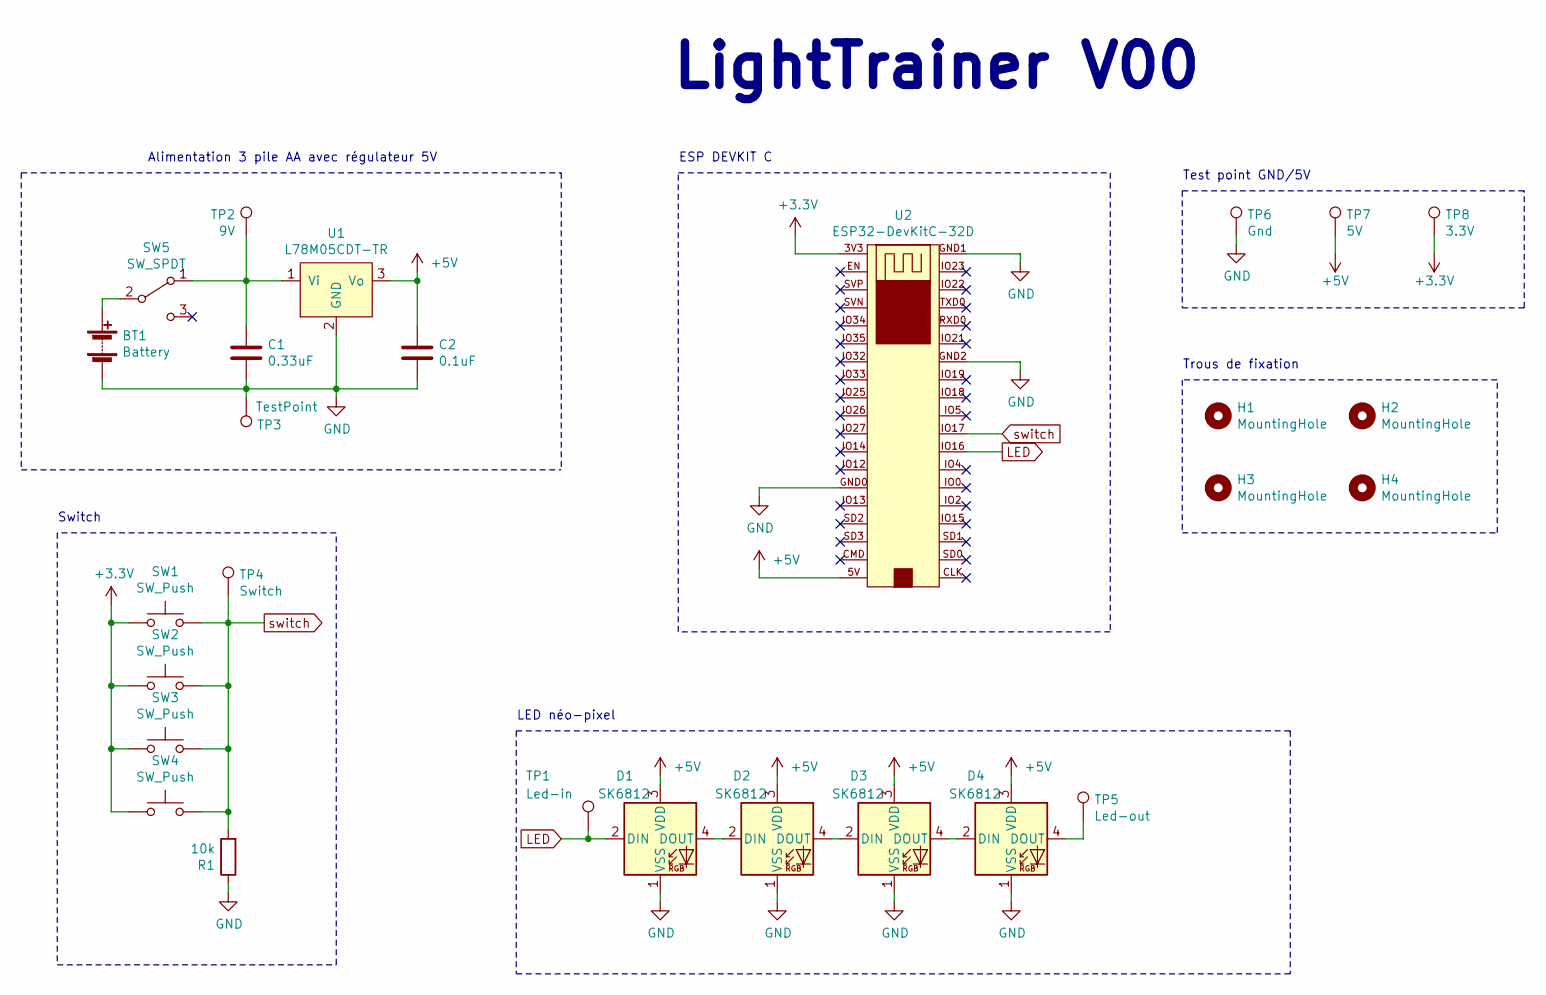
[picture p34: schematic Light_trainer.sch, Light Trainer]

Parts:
BT1: Battery; BatteryHolder_Keystone_593-594
C1: 0.33uF; C_0805_2012Metric
C2: 0.1uF; C_0805_2012Metric
D1, D2, D3, D4: SK6812; LED_SK6812_PLCC4_5.0x5.0mm_P3.2mm
H1, H2, H3, H4: MountingHole; MountingHole_3.2mm_M3
R1: 10k; R_1206_3216Metric
SW1, SW2, SW3, SW4: SW_Push; SW_Cherry_MX_1.00u_PCB_3D
SW5: SW_SPDT; C&K-1101M2S5CQE2
TP1: Led-in; TestPoint_THTPad_2.5x2.5mm_Drill1.2mm
TP2: 9V; TestPoint_THTPad_2.5x2.5mm_Drill1.2mm
TP3: TestPoint; TestPoint_THTPad_2.5x2.5mm_Drill1.2mm
TP4: Switch; TestPoint_THTPad_2.5x2.5mm_Drill1.2mm
TP5: Led-out; TestPoint_THTPad_2.5x2.5mm_Drill1.2mm
TP6: Gnd; TestPoint_THTPad_2.5x2.5mm_Drill1.2mm
TP7: 5V; TestPoint_THTPad_2.5x2.5mm_Drill1.2mm
TP8: 3.3V; TestPoint_THTPad_2.5x2.5mm_Drill1.2mm
U1: L78M05CDT-TR; TO-252-2
U2: ESP32-DevKitC-32D

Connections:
+3V3: SW1.1, SW2.1, SW3.1, SW4.1, TP8.1, U2.3V3
+5V: C2.1, D1.3 (VDD), D2.3 (VDD), D3.3 (VDD), D4.3 (VDD), TP7.1, U1.3 (Vo), U2.5V
GND: BT1.2 (-), C1.2, C2.2, D1.1 (VSS), D2.1 (VSS), D3.1 (VSS), D4.1 (VSS), R1.1, TP3.1, TP6.1, U1.2 (GND), U2.GND0, U2.GND1, U2.GND2
LED: D1.2 (DIN), TP1.1, U2.IO16
unnamed: BT1.1 (+), SW5.2 (B)
unnamed: C1.1, SW5.1 (A), TP2.1, U1.1 (Vi)
unnamed: D1.4 (DOUT), D2.2 (DIN)
unnamed: D2.4 (DOUT), D3.2 (DIN)
unnamed: D3.4 (DOUT), D4.2 (DIN)
unnamed: D4.4 (DOUT), TP5.1
switch: R1.2, SW1.2, SW2.2, SW3.2, SW4.2, TP4.1, U2.IO17

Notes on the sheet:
Switch
LightTrainer V00
LED néo-pixel
ESP DEVKIT C
Alimentation 3 pile AA avec régulateur 5V
Test point GND/5V
Trous de fixation

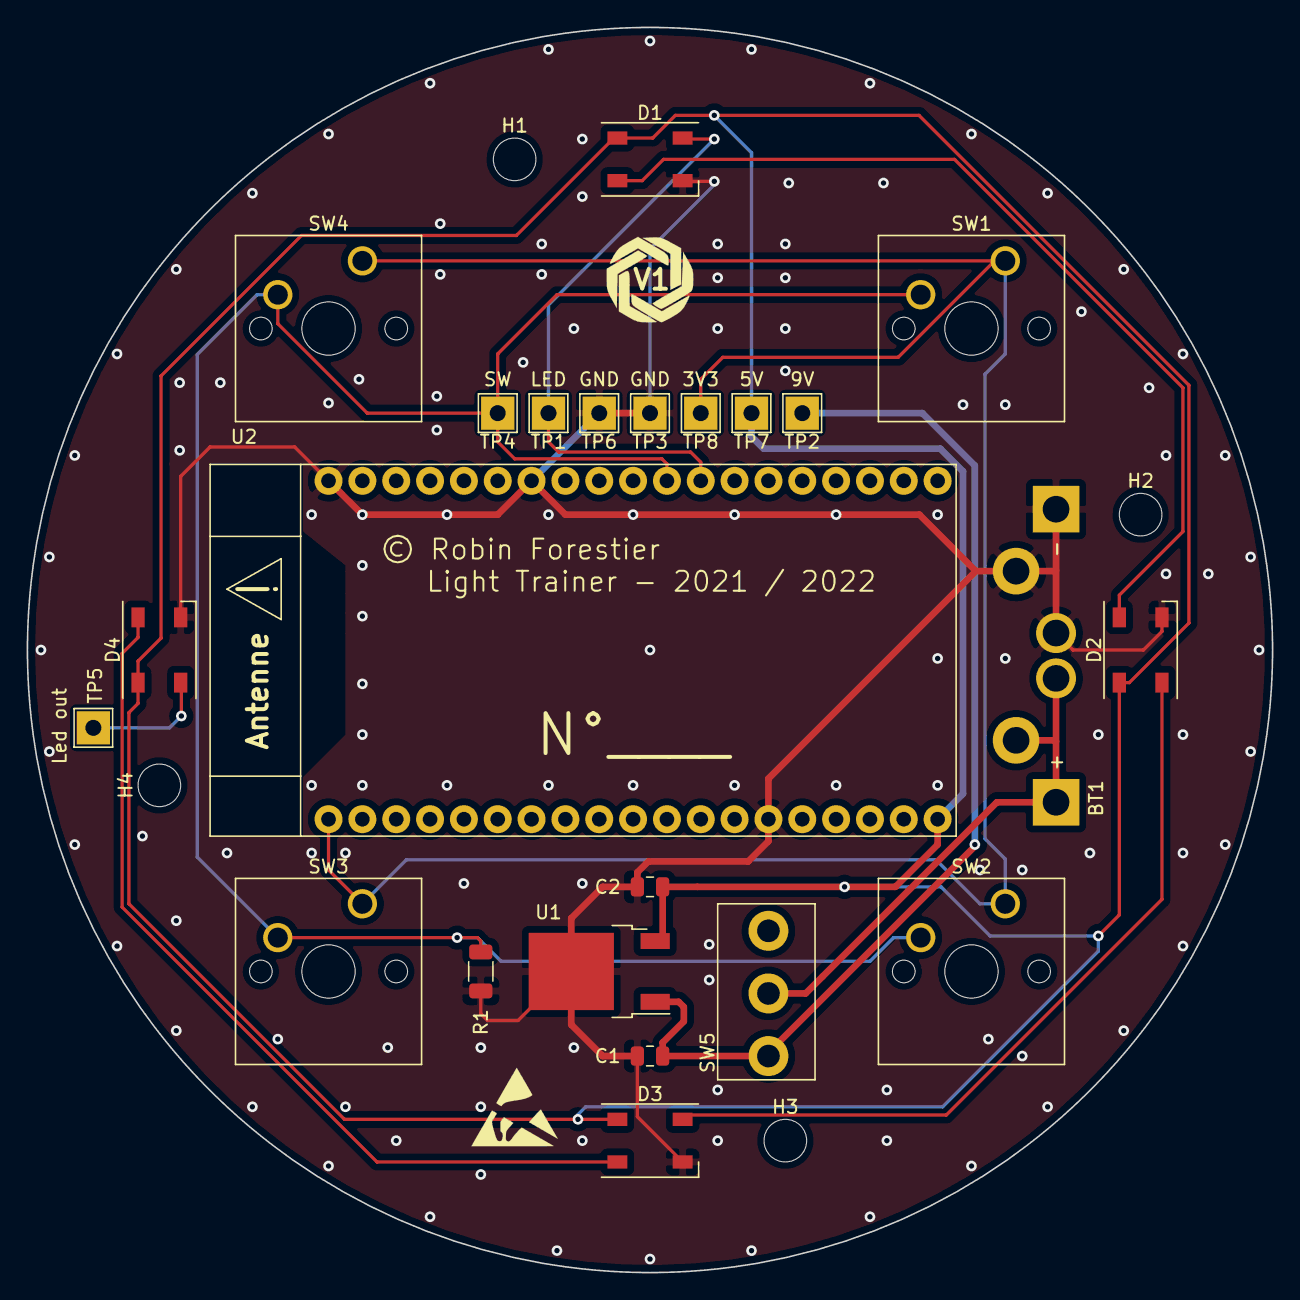
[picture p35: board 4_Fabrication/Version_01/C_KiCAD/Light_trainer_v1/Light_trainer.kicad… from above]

Board: 2 copper layers, 93.5 x 93.5 mm, 27 parts (0 on the bottom side), 11 nets.

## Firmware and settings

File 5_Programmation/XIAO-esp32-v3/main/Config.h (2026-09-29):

#ifndef CONFIG_H
#define CONFIG_H

#include <Arduino.h>

// Version du firmware (utilisée pour l'UI, l'API et les releases OTA)
#define FIRMWARE_VERSION "3.1.0"

// ---- CONFIGURATION MATERIELLE (Alignée Schéma V3 & Veroboard) ----
#define LED_PIN D7        // Broche 8 de U1 (LEDS WS2812B Data)
#define NUM_LEDS 7
#define SCL_PIN D4        // Broche 5 de U1 (I2C SCL - VL53L0X)
#define SDA_PIN D5        // Broche 6 de U1 (I2C SDA - VL53L0X)

#define SW_PIN D2         // Broche 3 de U1 (3V3_S - Détection ON/OFF & Wake-up)
#define CHARGE_PIN D10    // Broche 11 de U1 (Détection 5V USB VBUS)
#define BUZZER_PIN D3     // Broche 4 de U1 (Prévision Buzzer TP2)

// ---- CONFIGURATION TOF (VL53L0X) & GESTES UX ----
#define TOF_TRIGGER_DISTANCE 150 // Distance max en mm pour détecter la présence de la main (Tap / Hit / Hold)
#define TOF_PRECISION_MODE Adafruit_VL53L0X::VL53L0X_SENSE_HIGH_SPEED // Mode 50Hz pour réactivité sportive

// ---- PARAMETRES GESTUELS ----
#define GESTURE_TAP_MAX_MS 500            // Durée max pour un Tap court (changement de mode en Menu)
#define GESTURE_START_HOLD_MS 1500        // Durée de maintien pour démarrer la partie (Start en Menu)
#define GESTURE_MENU_HOLD_MS 3000         // Durée de maintien pour retourner au Menu depuis le jeu
#define GESTURE_GLITCH_TOLERANCE_MS 250   // Tolérance aux micro-décrochages optiques avant réinitialisation du Hold
#define HIT_FLASH_MS 60                   // Durée du flash blanc de confirmation lors d'un Hit

#define NVS_KEY_BRIGHTNESS "led_bright" // NVS key for brightness
#define DEFAULT_BRIGHTNESS 50 // Default brightness (0-255)

// ---- BATTERY MONITORING ----
#define ENABLE_BATTERY_MANAGEMENT true   // Activé pour le prototype Veroboard
#define BAT_ADC_PIN D1                   // Broche 2 de U1 (Mesure tension batterie)

// Pont diviseur 100k / 100k
#define BAT_R1 100.0  // kOhm
#define BAT_R2 100.0  // kOhm
#define VOLTAGE_DIVIDER_RATIO (BAT_R2 / (BAT_R1 + BAT_R2))

#define BAT_VOLT_FULL 4.2   // Volts (100% for LiPo)
#define BAT_VOLT_LOW 3.4    // Volts (approx 5% for LiPo, check datasheet for exact value)
#define BAT_VOLT_EMPTY 3.0  // Volts (0% for LiPo, critical cut-off)

#define ADC_MAX_VALUE 4095.0  // 12-bit ADC
#define ADC_REF_VOLTAGE 3.3   // ADC reference voltage for ESP32

// ---- BATTERY THRESHOLDS ----
#define CRITICAL_BATTERY_PERCENTAGE 2  // %
#define USB_POWERED_VOLTAGE_THRESHOLD 0.5 // Volts - if battery voltage is below this, assume USB power and no deep sleep

// ---- CONFIGURATION SYSTEME ----
#define MAX_NODES 20                // Remplacer std::vector par un tableau fixe pour la stabilité
#define SENSOR_TIMEOUT 200          // Evite de bloquer si le capteur plante
#define DISCOVERY_INT 5000         // Découverte toutes les 5s
#define INACTIVITY_TIMEOUT 1800000  // 30 minutes

// ---- DEBUG CONFIGURATION ----
// Define debug levels
#define DEBUG_NONE 0
#define DEBUG_ERROR 1
#define DEBUG_WARNING 2
#define DEBUG_INFO 3
#define DEBUG_VERBOSE 4

// Set the desired debug level (e.g., DEBUG_INFO to show errors and info, DEBUG_VERBOSE for all)
#define CURRENT_DEBUG_LEVEL DEBUG_INFO

// Debug macro for serial printing
#define DEBUG_PRINT(level, format, ...) \
  do { \
    if (level <= CURRENT_DEBUG_LEVEL) { \
      Serial.printf("[%s] " format "\n", \
                    (level == DEBUG_ERROR ? "ERROR" : (level == DEBUG_INFO ? "INFO" : (level == DEBUG_WARNING ? "WARNING" : (level == DEBUG_VERBOSE ? "VERBOSE" : "UNKNOWN")))), \
                    ##__VA_ARGS__); \
    } \
  } while (0)

// ---- MESH CONFIGURATION ----
#define DEFAULT_MESH_TTL 3          // Nombre maximum de sauts dans le réseau mesh

// ---- PROTOCOLE ----
enum MsgType { CMD_START,
               CMD_ACTIVATE,
               CMD_HIT,
               CMD_PING,
               CMD_ACK,
               CMD_RETURN_TO_MENU,
               CMD_MANUAL_SET,
               CMD_TEST_LEDS,
               CMD_POD_TELEMETRY,
               CMD_HEARTBEAT,
               CMD_CLAIM_MASTER };

// ---- GESTION DU MASTER & ÉLECTION DYNAMIQUE ----
#define MASTER_HEARTBEAT_INTERVAL_MS 1000  // Période d'émission du Heartbeat Master
#define MASTER_TIMEOUT_MS            3000  // Délai sans heartbeat avant élection d'urgence
#define BOOT_ELECTION_WINDOW_MS      2000  // Fenêtre d'attente au boot avant auto-élection

typedef struct __attribute__((packed)) struct_message {
  uint32_t msgId;     // Identifiant unique du message pour le mesh
  uint64_t senderID;  // ID du pod expéditeur original
  uint64_t targetID;  // 0 = Broadcast (tous), sinon ID du pod ciblé
  uint8_t msgType;    // Type de message (MsgType)
  uint8_t ttl;        // Time-To-Live (nombre de sauts restants)
  uint32_t color;     // Couleur associée
} struct_message;

// ---- ETATS DU POD ----
enum State { MENU,              // Mode selection
             CONTROLLER,        // This pod is the orchestrator
             CONTROLLER_TARGET, // This pod is the orchestrator AND the current target to light up
             ACTIVE_TARGET,     // Target to light up
             IDLE_LISTENER };   // Wait for command

// ---- MODES DE JEU ----
struct GameMode {
  uint32_t color1;
  uint32_t color2;
  uint32_t delayMin;  // secondes
  uint32_t delayMax;  // secondes
};

// ---- HELPERS DE DEBUG ----
inline const char* msgTypeToString(uint8_t type) {
  switch (type) {
    case CMD_START:          return "CMD_START";
    case CMD_ACTIVATE:       return "CMD_ACTIVATE";
    case CMD_HIT:            return "CMD_HIT";
    case CMD_PING:           return "CMD_PING";
    case CMD_ACK:            return "CMD_ACK";
    case CMD_RETURN_TO_MENU: return "CMD_RETURN_TO_MENU";
    case CMD_MANUAL_SET:     return "CMD_MANUAL_SET";
    case CMD_TEST_LEDS:      return "CMD_TEST_LEDS";
    case CMD_POD_TELEMETRY:  return "CMD_POD_TELEMETRY";
    case CMD_HEARTBEAT:      return "CMD_HEARTBEAT";
    case CMD_CLAIM_MASTER:   return "CMD_CLAIM_MASTER";
    default:                 return "CMD_UNKNOWN";
  }
}

inline const char* stateToString(State s) {
  switch (s) {
    case MENU:              return "MENU";
    case CONTROLLER:        return "CONTROLLER (Master)";
    case CONTROLLER_TARGET: return "CONTROLLER_TARGET (Master actif)";
    case ACTIVE_TARGET:     return "ACTIVE_TARGET (Esclave actif)";
    case IDLE_LISTENER:     return "IDLE_LISTENER (Esclave en attente)";
    default:                return "UNKNOWN_STATE";
  }
}

#endif

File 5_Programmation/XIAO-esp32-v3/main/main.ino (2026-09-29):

#include "Config.h"
#include "Hardware.h"
#include "GameNetwork.h"
#include "GameEngine.h"
#include "WebConfig.h"

unsigned long lastDiscovery = 0;

void setup() {
  Serial.begin(115200);
  
  // --- SÉCURITÉ ANTI-BRICK / FLASH USB ---
  // Délai de sécurité au démarrage avec port USB ouvert pour le téléversement
  delay(3000);
  DEBUG_PRINT(DEBUG_VERBOSE, "Entering setup()");

  // 1. Vérification de l'interrupteur ON/OFF après le délai de sécurité
  pinMode(SW_PIN, INPUT_PULLDOWN);
  pinMode(CHARGE_PIN, INPUT); // Haute impédance

  // Si l'interrupteur est sur OFF ET que le câble USB n'est pas branché -> Deep Sleep
  if (digitalRead(SW_PIN) == LOW && digitalRead(CHARGE_PIN) == LOW) {
    DEBUG_PRINT(DEBUG_INFO, "Switch OFF et pas d'USB -> Passage en Deep Sleep.");
    Hardware.goToDeepSleep();
  }

  // 2. Initialiser le Hardware
  Hardware.init();

  // 3. Charger les réglages persistants NVS
  WebConfig.loadSettings(Game.getAllGameModes());
  Hardware.setBrightness(WebConfig.getBrightness());

  // 4. Initialiser le réseau ESP-NOW (WIFI_STA pur)
  DEBUG_PRINT(DEBUG_INFO, "Initialisation GameNetwork (WIFI_STA pur)...");
  GameNetwork.init();

  // 5. Initialiser le Moteur de Jeu
  DEBUG_PRINT(DEBUG_INFO, "Initialisation GameEngine...");
  Game.init();

  // 6. Enregistrer les routes du Web Dashboard & API (SoftAP en veille jusqu'à élection Master)
  DEBUG_PRINT(DEBUG_INFO, "Enregistrement routes Web Dashboard & API...");
  WebConfig.init();

  DEBUG_PRINT(DEBUG_INFO, "Système Prêt ! ID Pod : %llu (Élection Master en cours...)", GameNetwork.getMyId());

  // Première diffusion de télémétrie et découverte
  uint8_t initPct = 85;
  float initVolt = 3.9f;
  bool initChg = false;
#if ENABLE_BATTERY_MANAGEMENT
  initPct = (uint8_t)Hardware.getBatteryPercentage();
  initVolt = Hardware.getBatteryVoltage();
  initChg = Hardware.isCharging();
#endif
  uint16_t initVCent = (uint16_t)(initVolt * 100.0f);
  uint32_t initTelem = (initPct & 0xFF) | ((initVCent & 0xFFFF) << 8) | ((initChg ? 1 : 0) << 24);
  GameNetwork.broadcast(CMD_POD_TELEMETRY, initTelem);
}

void loop() {
  // 1. Vérification de l'interrupteur mécanique ON/OFF
  Hardware.checkPowerSwitch();

  // 2. Boucle de jeu et matériel
  Hardware.update();
#if ENABLE_BATTERY_MANAGEMENT
  Hardware.updateBatteryLED(); // Mise à jour état de charge / batterie faible
#endif
  Hardware.checkSleep();
  Game.loop();
  GameNetwork.update();

  // 3. Gestion du Serveur Web & Portail Captif (Non-bloquant)
  WebConfig.update();

  // 4. Découverte réseau et télémétrie batterie périodique
  if (millis() - lastDiscovery > DISCOVERY_INT) {
    lastDiscovery = millis();
    uint8_t pct = 85;
    float volt = 3.9f;
    bool chg = false;
#if ENABLE_BATTERY_MANAGEMENT
    pct = (uint8_t)Hardware.getBatteryPercentage();
    volt = Hardware.getBatteryVoltage();
    chg = Hardware.isCharging();
#endif
    uint16_t vCent = (uint16_t)(volt * 100.0f);
    uint32_t telem = (pct & 0xFF) | ((vCent & 0xFFFF) << 8) | ((chg ? 1 : 0) << 24);
    DEBUG_PRINT(DEBUG_VERBOSE, "Diffusion télémétrie batterie: %d%% (%.2fV)", pct, volt);
    GameNetwork.broadcast(CMD_POD_TELEMETRY, telem);
  }
}

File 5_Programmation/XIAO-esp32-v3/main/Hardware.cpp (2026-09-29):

#include "Hardware.h"

HardwareManager Hardware;

HardwareManager::HardwareManager() :
  lox(),
  hasSensor(false),
  lastSensorRead(0),
  lastActivityTime(0),
  triggerTap(false),
  triggerStartHold(false),
  triggerMenuHold(false),
  triggerHit(false),
  holdProgress(0.0f),
  isHandPresent(false),
  handPresenceStartTime(0),
  handAbsenceStartTime(0),
  startHoldTriggered(false),
  menuHoldTriggered(false),
  isFlashingWhite(false),
  flashWhiteEndTime(0),
  blinkState(BLINK_IDLE),
  blinkColor(0),
  blinkCountRemaining(0),
  blinkTimer(0),
  blinkDelay(100),
  rainbowBlinkState(RAINBOW_BLINK_IDLE),
  rainbowBlinkCountRemaining(0),
  rainbowBlinkTimer(0),
  rainbowBlinkDelay(0),
  rainbowBlinkCurrentColorIndex(0)
#if ENABLE_BATTERY_MANAGEMENT
  ,
  batteryVoltage(0.0),
  lastBatteryCheckTime(0),
  voltageHistory{0},
  voltageHistoryIndex(0)
#endif
{
}

void HardwareManager::init() {
  DEBUG_PRINT(DEBUG_INFO, "Initializing HardwareManager...");

  // Configuration des broches d'entrée matérielles
  pinMode(SW_PIN, INPUT_PULLDOWN);       // Interrupteur ON/OFF (D2)
  pinMode(CHARGE_PIN, INPUT);            // Détection USB 5V (D10) - haute impédance sans pull-down interne

  // Init LEDs sur D7
  FastLED.addLeds<WS2812B, LED_PIN, GRB>(leds, NUM_LEDS);
  setBrightness(DEFAULT_BRIGHTNESS);
  setLight(0);
  DEBUG_PRINT(DEBUG_INFO, "LEDs initialized on pin D%d.", LED_PIN);

#if ENABLE_BATTERY_MANAGEMENT
  pinMode(BAT_ADC_PIN, INPUT);
  analogSetAttenuation(ADC_11db); // Atténuation 11dB pour lecture pleine échelle ADC ESP32-C3
  DEBUG_PRINT(DEBUG_INFO, "Battery initialized on pin D%d.", BAT_ADC_PIN);
  recordBatterySample(); // Échantillon initial à l'allumage
#else
  DEBUG_PRINT(DEBUG_INFO, "Battery verification not initialized");
#endif

  // Init I2C & Sensor en mode HIGH_SPEED pour réactivité sportive (SDA=D5, SCL=D4)
  Wire.begin(SDA_PIN, SCL_PIN);
  if (!lox.begin(0x29, false, &Wire, TOF_PRECISION_MODE)) {
    hasSensor = false;
    setLight(0xFFA500);  // Orange = Erreur Capteur
    DEBUG_PRINT(DEBUG_ERROR, "VL53L0X sensor initialization failed! Setting light to Orange.");
  } else {
    hasSensor = true;
    lox.startRangeContinuous();  // Mode rapide continu
    DEBUG_PRINT(DEBUG_INFO, "VL53L0X sensor initialized successfully in HIGH_SPEED mode.");
  }
}

void HardwareManager::setBrightness(uint8_t brightness) {
  FastLED.setBrightness(brightness);
  FastLED.show();
  DEBUG_PRINT(DEBUG_INFO, "LED brightness set to %d.", brightness);
}

void HardwareManager::setLight(uint32_t color) {
  uint8_t r = (color >> 16) & 0xFF;
  uint8_t g = (color >> 8) & 0xFF;
  uint8_t b = color & 0xFF;

  CRGB grbColor = CRGB(r, g, b);

  for (int i = 0; i < NUM_LEDS; i++) {
    leds[i] = grbColor;
  }
  FastLED.show();
}

void HardwareManager::setGauge(uint32_t activeColor, float progress, uint32_t bgColor) {
  progress = constrain(progress, 0.0f, 1.0f);
  int numActiveLeds = round(progress * NUM_LEDS);

  uint8_t ar = (activeColor >> 16) & 0xFF;
  uint8_t ag = (activeColor >> 8) & 0xFF;
  uint8_t ab = activeColor & 0xFF;
  CRGB activeCRGB = CRGB(ar, ag, ab);

  uint8_t br = (bgColor >> 16) & 0xFF;
  uint8_t bg = (bgColor >> 8) & 0xFF;
  uint8_t bb = bgColor & 0xFF;
  CRGB bgCRGB = CRGB(br, bg, bb);

  for (int i = 0; i < NUM_LEDS; i++) {
    leds[i] = (i < numActiveLeds) ? activeCRGB : bgCRGB;
  }
  FastLED.show();
}

void HardwareManager::flashWhite(uint16_t durationMs) {
  isFlashingWhite = true;
  flashWhiteEndTime = millis() + durationMs;
  for (int i = 0; i < NUM_LEDS; i++) {
    leds[i] = CRGB(255, 255, 255);
  }
  FastLED.show();
}

void HardwareManager::blink(uint32_t color, int count) {
  if (blinkState == BLINK_IDLE) {
    DEBUG_PRINT(DEBUG_INFO, "Initiating non-blocking blink for color %lx, count %d.", (unsigned long)color, count);
    blinkColor = color;
    blinkCountRemaining = count * 2;
    blinkState = BLINK_ON;
    blinkTimer = millis();
    setLight(blinkColor);
  }
}

void HardwareManager::rainbowBlink(int count, int delayMs) {
  if (rainbowBlinkState == RAINBOW_BLINK_IDLE) {
    DEBUG_PRINT(DEBUG_INFO, "Initiating non-blocking rainbow blink for %d cycles with %dms delay.", count, delayMs);
    rainbowBlinkCountRemaining = count;
    rainbowBlinkDelay = delayMs;
    rainbowBlinkCurrentColorIndex = 0;
    rainbowBlinkState = RAINBOW_BLINK_CYCLE;
    rainbowBlinkTimer = millis();
    setLight(rainbowColors[rainbowBlinkCurrentColorIndex]);
  }
}

void HardwareManager::rainbowAnimation() {
  static unsigned long lastUpdate = 0;
  static uint8_t hue = 0;

  if (millis() - lastUpdate > 20) {
    lastUpdate = millis();
    fill_rainbow(leds, NUM_LEDS, hue, 7);
    FastLED.show();
    hue++;
    if (hue >= 255) hue = 0;
  }
}
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

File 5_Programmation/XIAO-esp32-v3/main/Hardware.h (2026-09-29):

#ifndef HARDWARE_H
#define HARDWARE_H

#include "Config.h"
#include <FastLED.h>
#include <Wire.h>
#include <vector>
#include "Adafruit_VL53L0X.h"

// Échantillon de télémétrie batterie pour graphique style iOS
struct BatterySample {
  uint32_t timestampSec;
  uint8_t percentage;
  float voltage;
  bool isCharging;
};

// States for non-blocking blink
enum BlinkState {
  BLINK_IDLE,
  BLINK_ON,
  BLINK_OFF
};

// States for non-blocking rainbow blink
enum RainbowBlinkState {
  RAINBOW_BLINK_IDLE,
  RAINBOW_BLINK_CYCLE
};

class HardwareManager {
public:
  HardwareManager(); // Constructor declaration
  void init();
  void update();  // Pour les animations LED

  // LEDs
  void setLight(uint32_t color);
  void setBrightness(uint8_t brightness);
  void blink(uint32_t color, int count);
  void rainbowBlink(int count, int delayMs);
  void rainbowAnimation(); // Continuous rainbow animation
  void setGauge(uint32_t activeColor, float progress, uint32_t bgColor = 0); // Jauge circulaire 0.0 - 1.0 sur les 7 LEDs
  void flashWhite(uint16_t durationMs = HIT_FLASH_MS); // Flash blanc instantané de confirmation

  // Capteur
  bool isSensorActive() const { return hasSensor; }
  int getDistance();
  int getLastValidDistance() const { return lastStoredDistance; }
  bool isHandCurrentlyPresent() const { return isHandPresent; }
  String getSensorDebugString();

  // Public getters for triggers
  bool getTriggerTap() const { return triggerTap; }
  bool getTriggerStartHold() const { return triggerStartHold; }
  bool getTriggerMenuHold() const { return triggerMenuHold; }
  bool getTriggerHit() const { return triggerHit; }
  float getHoldProgress() const { return holdProgress; }

  // Public setter for triggers
  void setTriggerHit(bool state) { triggerHit = state; }

  // Public methods to clear triggers
  void clearAllTriggers() {
    triggerTap = false;
    triggerStartHold = false;
    triggerMenuHold = false;
    triggerHit = false;
  }

  // Sleep & Power Switch
  void checkSleep();
  void checkPowerSwitch(); // Gère l'interrupteur ON/OFF matériel
  void goToDeepSleep();    // Isole les GPIOs et active la veille profonde
  void resetActivityTimer() {
    lastActivityTime = millis();
  }

#if ENABLE_BATTERY_MANAGEMENT
  // Battery Management & History
  float getBatteryVoltage();
  int getBatteryPercentage();
  bool isCharging();
  bool isLowBattery();
  void updateBatteryLED();
  String getBatteryDebugString();
  void recordBatterySample();
  const std::vector<BatterySample>& getBatteryHistory() const { return batteryHistory; }
#else
  String getBatteryDebugString() { return "Gestion batterie desactivee"; }
#endif

private:
  CRGB leds[NUM_LEDS];
  Adafruit_VL53L0X lox = Adafruit_VL53L0X();
  bool hasSensor = false;
  unsigned long lastSensorRead = 0;
  unsigned long lastActivityTime = 0;
  int lastStoredDistance = 8192;

  // Inputs détectés
  bool triggerTap = false;
  bool triggerStartHold = false;
  bool triggerMenuHold = false;
  bool triggerHit = false;
  float holdProgress = 0.0f;
  unsigned long lastHitTriggerTime = 0;
  bool hitArmed = true;

  // Machine à états gestuelle ToF
  bool isHandPresent = false;
  unsigned long handPresenceStartTime = 0;
  unsigned long handAbsenceStartTime = 0;
  bool startHoldTriggered = false;
  bool menuHoldTriggered = false;

  // Non-blocking hit flash
  bool isFlashingWhite = false;
  unsigned long flashWhiteEndTime = 0;

  // Non-blocking blink variables
  BlinkState blinkState = BLINK_IDLE;
  uint32_t blinkColor;
  int blinkCountRemaining = 0;
  unsigned long blinkTimer = 0;
  int blinkDelay = 100;

  // Non-blocking rainbow blink variables
  RainbowBlinkState rainbowBlinkState = RAINBOW_BLINK_IDLE;
  int rainbowBlinkCountRemaining = 0;
  unsigned long rainbowBlinkTimer = 0;
  int rainbowBlinkDelay = 0;
  int rainbowBlinkCurrentColorIndex = 0;
  uint32_t rainbowColors[7] = {0xFF0000, 0xFF7F00, 0xFFFF00, 0x00FF00, 0x0000FF, 0x4B0082, 0x9400D3};

  // Helper for non-blocking LED animations
  void processNonBlockingLEDAnimations();
  
#if ENABLE_BATTERY_MANAGEMENT
  // Battery related members
  float batteryVoltage = 0.0;
  unsigned long lastBatteryCheckTime = 0;
  unsigned long lastBatterySampleTime = 0;
  std::vector<BatterySample> batteryHistory;
  float voltageHistory[10];
  int voltageHistoryIndex = 0;
#endif
};

extern HardwareManager Hardware;  // Instance globale

#endif

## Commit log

2020-11-27 fisrts commit
    creation folder
    [Liste des pièces.xlsx]
2020-11-28 liste des pièce
    add liste de pièce + 3d
    [Liste des pièces.xlsx, Liste_des_pieces.xlsx]
2020-12-08 add kicad
    add first kicad + modif readme
    [Light_trainer.kicad_pcb, Light_trainer.sch]
2020-12-09 modif kicad
    [Light_trainer.sch]
2020-12-15 modif kicad
    add programateur, protection, esd
    [Light_trainer.sch]
2020-12-16 add neo-pixel led
    add néo-pixel led
    add 3V to 5V
    modif condo EN
    add listes des composants
    [Light_trainer.sch]
2020-12-19 add label
    [Light_trainer.sch]
2021-01-04 modif KiCad
    modif protect batt
    change usb driver
    add data sheet and foot print
    [Light_trainer.sch]
2021-01-05 modif kicad
    first layout
    8 néo pixel
    [Light_trainer.sch]
2021-06-22 add code
    I maybe want to work with pi pico and NRF24l01.
    But I have to abandoned my idea of the site web.
    [Light_trainer.kicad_pcb]
2021-09-11 add datasheet
    Restart the project
    [Light_trainer.kicad_pcb, Light_trainer.sch]
2021-09-12 add footprint
    [Light_trainer.sch]
2021-09-12 ADD all footprint
    All footprint
    miss 1 3d (battery holder 3xAA)
    [Light_trainer.kicad_pcb, Light_trainer.sch]
2021-09-12 add all 3D
    [Light_trainer.kicad_pcb, Light_trainer.sch]
2021-09-13 first routage
    first placement + start routage
    [Light_trainer.kicad_pcb]
2021-09-14 placement + routage
    [Light_trainer.kicad_pcb, Light_trainer.sch]
2021-09-15 Creat Gerber
    creation des fichiers gerber.
    [Light_trainer-B_Cu.gbr, Light_trainer-B_Mask.gbr, Light_trainer-B_Paste.gbr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]
2021-09-15 add pdf fabrication
    add pdf fabrication
    [Light_trainer.kicad_pcb]
2021-09-15 add pdf DOC FAB
    [Light_trainer.kicad_pcb]
2021-09-15 add liste panier
    [Digi-Key_Panier.xlsx]
2021-09-17 creat archive
    creat archive V1
    [1101M2S5CQE2.stp, C_0805_2012Metric.step, Cherry_-_MX1A-11NW.step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]
2022-06-15 new pcb
    [1101M2S5CQE2.stp, 629105150521.stp, 9V Battery.STEP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]
2026-02-05 Add ESP32 Light Trainer (XIAO) project
    Introduce a complete ESP32 (XIAO) Light Trainer project implementing a multiplayer game system. Adds core modules: Hardware (WS2812B LED and VL53L0X sensor handling), GameNetwork (ESP-NOW peer discov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
2026-02-05 Refactor GameEngine/Hardware; add battery support
    Major refactor across GameEngine, Hardware and GameNetwork plus docs update:
    - Config.h: add NVS brightness key, default brightness, battery monitoring config (divider, ADC pin, thresholds), reorder debug levels and add CMD_RETURN_TO_MENU.
    - GameEngine: move initial state to constructor, implement non-blocking startGame sequence, add returnToMenu and long-press menu trigger handling, use getters for modes/IDs, adapt scheduling/activation to new APIs and remove blocking delays.
    - GameNetwork: encapsulate myId and known nodes (fixed-size array), add getMyId/getKnownNodes, make addNode return bool, robust MAC conversion helper and peer-add erro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
    [Config.h, GameEngine.h, Hardware.cpp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]
2026-09-29 feat: V3 firmware architecture, dynamic master election, GZIP web optimization & repo cleanup
    - Firmware V3 (5_Programmation/XIAO-esp32-v3):
    - Exclusive SoftAP on Master node (WIFI_STA by default on slaves, zero RF beacon clutter).
    - Dynamic master election with MAC/battery priority and 3s failover watchdog.
    - Physical user override: Hold 1.5s gesture claims master role dynamically.
    - GZIP web compression (DashboardHtml.h, 78.6% reduction to 15.6KB, <80ms load time).
    - Decoupled REST API (/api/config static vs zero-allocation /api/status in <0.5ms).
    - Adaptive smart polling (100ms during active game, 1000ms in standby/menu).
    - Documentation & Hardware:
    - Added system architectu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
    [Digi-Key_Panier.xlsx, LIGHT_TRAINER_PCB.step, Light_trainer.kicad_pcb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]
2026-09-29 feat(ci): add CI/CD pipeline, sanity tests, and auto-release on merge
    [huge_app.csv]
2026-09-29 feat(ota): add dual-partition OTA support, /update route and 4G GitHub check tab
    [huge_app.csv]

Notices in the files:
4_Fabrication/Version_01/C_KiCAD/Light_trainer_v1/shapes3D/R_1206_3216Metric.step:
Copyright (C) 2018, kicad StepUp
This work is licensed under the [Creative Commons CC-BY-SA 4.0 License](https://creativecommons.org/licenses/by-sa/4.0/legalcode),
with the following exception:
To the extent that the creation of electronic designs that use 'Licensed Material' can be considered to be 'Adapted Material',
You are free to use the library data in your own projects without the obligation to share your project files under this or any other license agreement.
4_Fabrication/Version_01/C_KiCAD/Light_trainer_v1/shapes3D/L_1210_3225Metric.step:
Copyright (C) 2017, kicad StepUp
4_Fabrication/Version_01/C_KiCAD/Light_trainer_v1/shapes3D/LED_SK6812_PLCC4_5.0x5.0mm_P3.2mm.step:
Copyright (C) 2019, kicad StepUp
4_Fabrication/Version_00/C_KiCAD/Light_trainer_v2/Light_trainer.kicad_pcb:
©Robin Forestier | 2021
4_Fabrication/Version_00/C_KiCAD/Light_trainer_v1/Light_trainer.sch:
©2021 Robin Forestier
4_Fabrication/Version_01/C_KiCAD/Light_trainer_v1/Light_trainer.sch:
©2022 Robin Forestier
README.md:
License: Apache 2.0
